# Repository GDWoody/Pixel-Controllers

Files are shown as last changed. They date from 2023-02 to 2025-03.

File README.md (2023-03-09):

# Copyright and Disclaimer
Copyright: GDWoody

This documentation describes Open Hardware and is licensed under the CERN Open Hardware License Version 2 - Strongly Reciprocal. (CERN-OHL-S)

You may redistribute and modify this documentation under the terms of the CERN OHL-S-v2 (https://ohwr.org/cern_ohl_s_v2.txt). This documentation is distributed WITHOUT ANY EXPRESS OR IMPLIED WARRANTY, INCLUDING OF MERCHANTABILITY, SATISFACTORY QUALITY AND FITNESS FOR A PARTICULAR PURPOSE. Please see the CERN OHL v2-S for applicable conditions

Under CERN OHL-S-v2, derivative work must be publicly released as defined in subsection 3.3

---
# Controllers & Expansion Boards

These Pixel Controllers are based on Scott Hanson's BBB 16v2 SMD controller [https://github.com/computergeek1507/PB_16](https://github.com/computergeek1507/PB_16/blob/master/BBB_16_SMD/README.md) with a few modifications and are designed as open source DIY hobbyist controllers. They are **not** intended to be sold as commercial products. All controller boards are 5v DC only and do not supply power for Pixel Strings, only data and ground. They all run FPP to drive the pixel and serial ports. Connection to a network/internet is by ethernet also WIFI and audio are supported via the USB port. All design files are open source and available on github, EasyEDA was used to create the designs.

Disclaimer: If you wish to build your own boards, please do so at your own risk. I use [jlcpcb.com](https://jlcpcb.com) for PCB manufacture and [lcsc.co](https://www.lcsc.com/) for parts, all the nessasary files are in the jlcpcb folders.

## [**BBB 16v2 SMD**](bbb_16/)

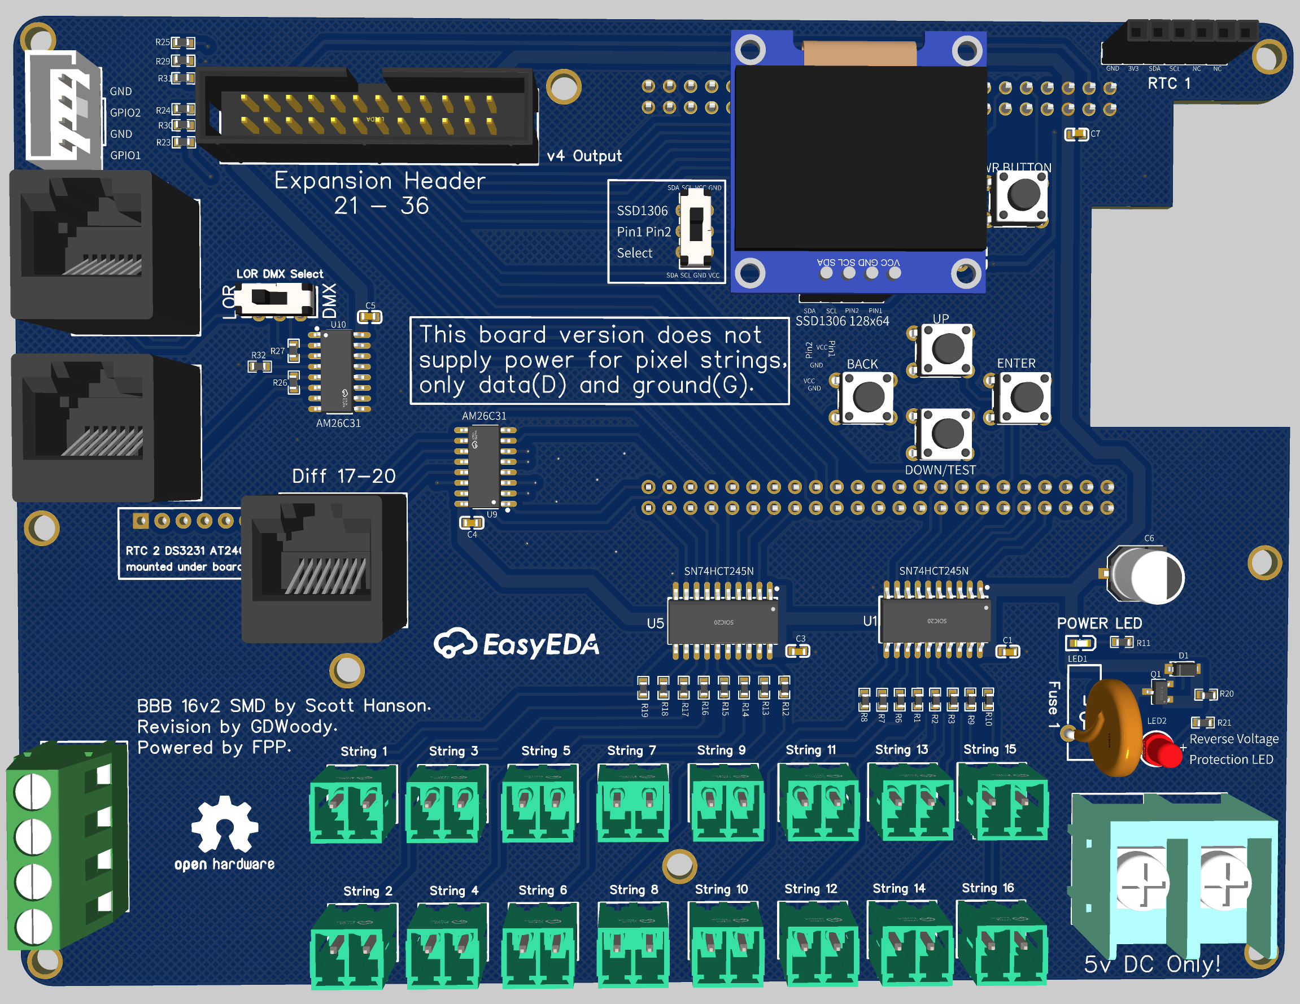
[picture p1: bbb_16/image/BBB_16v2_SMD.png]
Image of BBB 16v2 SMD Out


---
## [**Ordering PCB's from JLCPCB Instructions**](https://github.com/GDWoody/Pixel-Controllers/blob/main/JLC_PCB.md)

## [**Ordering Parts from LCSC Instructions**](https://github.com/GDWoody/Pixel-Controllers/blob/main/LCSC.md)

---
# Variants
I created different variants of the BB 16v2 SMD, to give more options for specific needs.

* [**BBB 16v2 SMD Push Fit**](bbb_16_push/) - 16 local ports with push fit connectors, 1 Differential port and 2 serial ports.

* [**BBB 8v1 SMD**](bbb_8/) - 8 local ports, 3 Differnetial ports and 2 serial ports.

* [**BBB 8v1 SMD Push Fit**](bbb_8_push/) - 8 local ports with push fit connectors, 3 Differential ports and 2 serial ports.

* [**BBB 4v1 SMD**](bbb_4/) - 4 local ports, 4 Differential ports and 2 serial ports.

* [**BBB 4v1 SMD Push Fit**](bbb_4_push/) - 4 local ports with push fit connectors, 4 Differential ports and 2 serial ports

* [**BBB All Diff v1**](bbb_all_diff/) - No local ports, 5 Differential ports and 2 serial ports.

---
# Expansion Boards
 All Expansion Boards are compatable with my BBB boards and variants.

* [**Differential Expansion**](bbb_diff_expansion/) - 4 Port Remote Differential Expansion (24 pins).

* [**16 Port Expansion**](bbb_16_expansion/) - 16 Port Local Expansion.

---
# Differential Receiver Boards
 All Receiver Boards are compatable with my BBB boards and variants.

* [**Differential Receivers**](diff_receiver/) - 4 Port Remote Differential Receivers.

---
## Additional Hardware Required

* A good quality SD card with FPP installed on it

* FPP images can be found at [**https://github.com/FalconChristmas/fpp/releases**](https://github.com/FalconChristmas/fpp/releases)

* A BeagleBone Black, BeagleBone Black Wireless, BeagleBone Green, or SanCloud BeagleBone enhanced 

* A SSD1306 128x64 OLED Display

---
# WLED Controllers

* [**WLED Controller with 4 output ports**](wled/)

* [**WLED Controller with 1 Differential port**](wled_d/)

---
## [**View All Boards**](image/)

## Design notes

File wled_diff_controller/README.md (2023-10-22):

## Copyright and Disclaimer
Copyright: GDWoody

This documentation describes Open Hardware and is licensed under the CERN Open Hardware License Version 2 - Strongly Reciprocal. (CERN-OHL-S)

You may redistribute and modify this documentation under the terms of the CERN OHL-S-v2 (https://ohwr.org/cern_ohl_s_v2.txt). This documentation is distributed WITHOUT ANY EXPRESS OR IMPLIED WARRANTY, INCLUDING OF MERCHANTABILITY, SATISFACTORY QUALITY AND FITNESS FOR A PARTICULAR PURPOSE. Please see the CERN OHL v2-S for applicable conditions

Under CERN OHL-S-v2, derivative work must be publicly released as defined in subsection 3.3

# WLED Differential Controller

The WLED Differential Controller requires a 5v DC only! Connecting any other size power source will damage the board. The board does not supply power outputs for pixels, only pixel data and ground connections.

# Features

* 1 Differential Port

* Reverse Voltage Protection

* GPIO 15 Relay Connector

* Power On Timer Delay Connections

## Additional Hardware Required

* A ESP32 WT32-ETH01 with WLED Software installed.

* WLED Software can be found at [**https://github.com/Aircoookie/WLED/releases**](https://github.com/Aircoookie/WLED/releases)

* WLED Software Installation and Help can be found at [**https://kno.wled.ge/basics/getting-started/**](https://kno.wled.ge/basics/getting-started/)

* Fully Compatable with [**Differential Receivers - 4 Port Remote Differential Receivers**](https://github.com/GDWoody/Pixel-Controllers/tree/main/diff_receiver/)

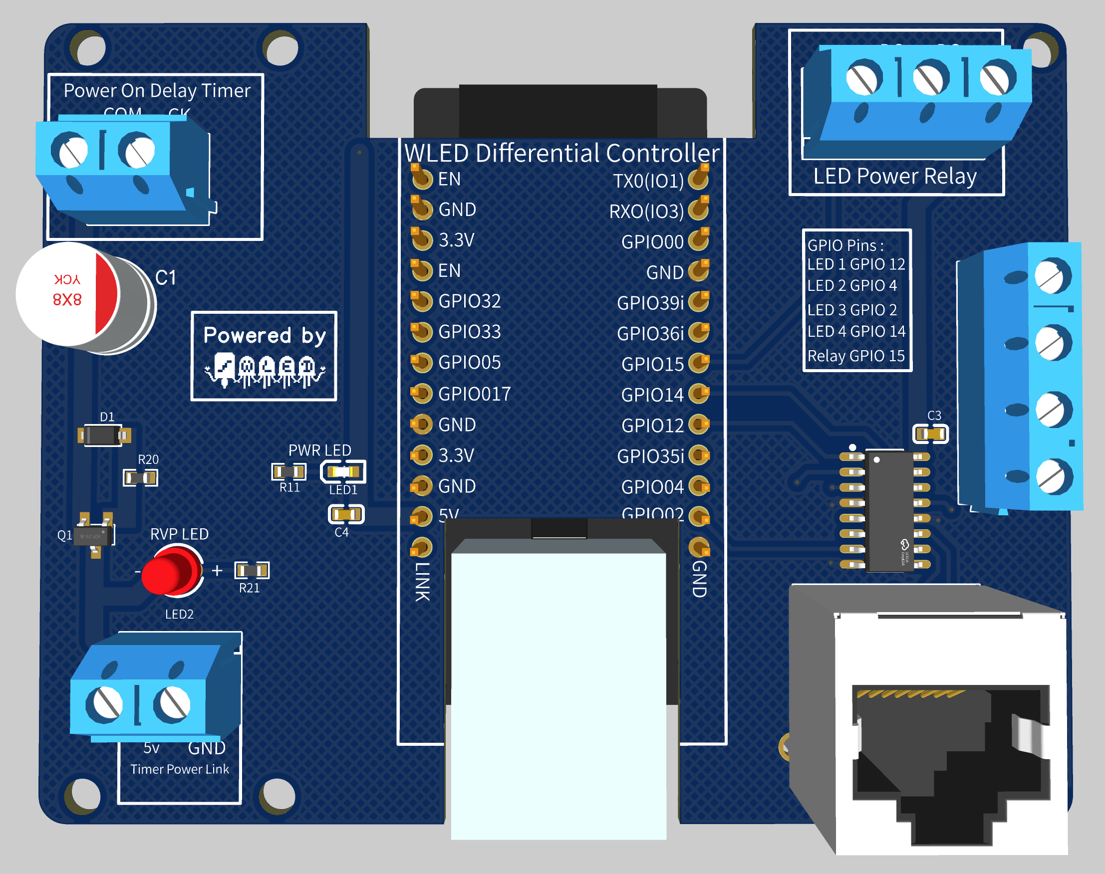
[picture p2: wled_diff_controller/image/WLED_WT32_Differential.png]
Image of WLED Differential Out


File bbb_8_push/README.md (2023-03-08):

## Copyright and Disclaimer
Copyright: GDWoody

This documentation describes Open Hardware and is licensed under the CERN Open Hardware License Version 2 - Strongly Reciprocal. (CERN-OHL-S)

You may redistribute and modify this documentation under the terms of the CERN OHL-S-v2 (https://ohwr.org/cern_ohl_s_v2.txt). This documentation is distributed WITHOUT ANY EXPRESS OR IMPLIED WARRANTY, INCLUDING OF MERCHANTABILITY, SATISFACTORY QUALITY AND FITNESS FOR A PARTICULAR PURPOSE. Please see the CERN OHL v2-S for applicable conditions

Under CERN OHL-S-v2, derivative work must be publicly released as defined in subsection 3.3

# BBB 8v1 SMD Push Fit Controller

Customised Pixel Controller based on Scott Hanson's BBB 16v2 SMD controller [https://github.com/computergeek1507/PB_16](https://github.com/computergeek1507/PB_16/blob/master/BBB_16_SMD/README.md). The board is largely the same as Scott's, but with a few modifications.

Note: The BBB 8v1 SMD Push Fit Controller requires a 5v DC only! Connecting any other size power source will damage the board. The board does no supply power outputs for pixels, only pixel data and ground connections.

# Features

* 700 pixel per output at 40 FPS or 1300 at 20 FPS

* 8 local ports with push fit connectors

* 3 Differential RJ45 ports

* 2 DMX Serial ports, DMX 1 can be selected as a DMX or LOR port

* 2 GPIO header

* 24 Pin expansion header

* SSD1306 128x64 OLED header

* Onboard 24LC256 eeprom

* Reverse Voltage Protection

* A RTC DS3231 AT24C32 can be connected to the board, either top mount or under mount.

* Onboard Resettable Fuse

---
## [**DIY Build Infomation**](https://github.com/GDWoody/Pixel-Controllers/blob/main/build.md)

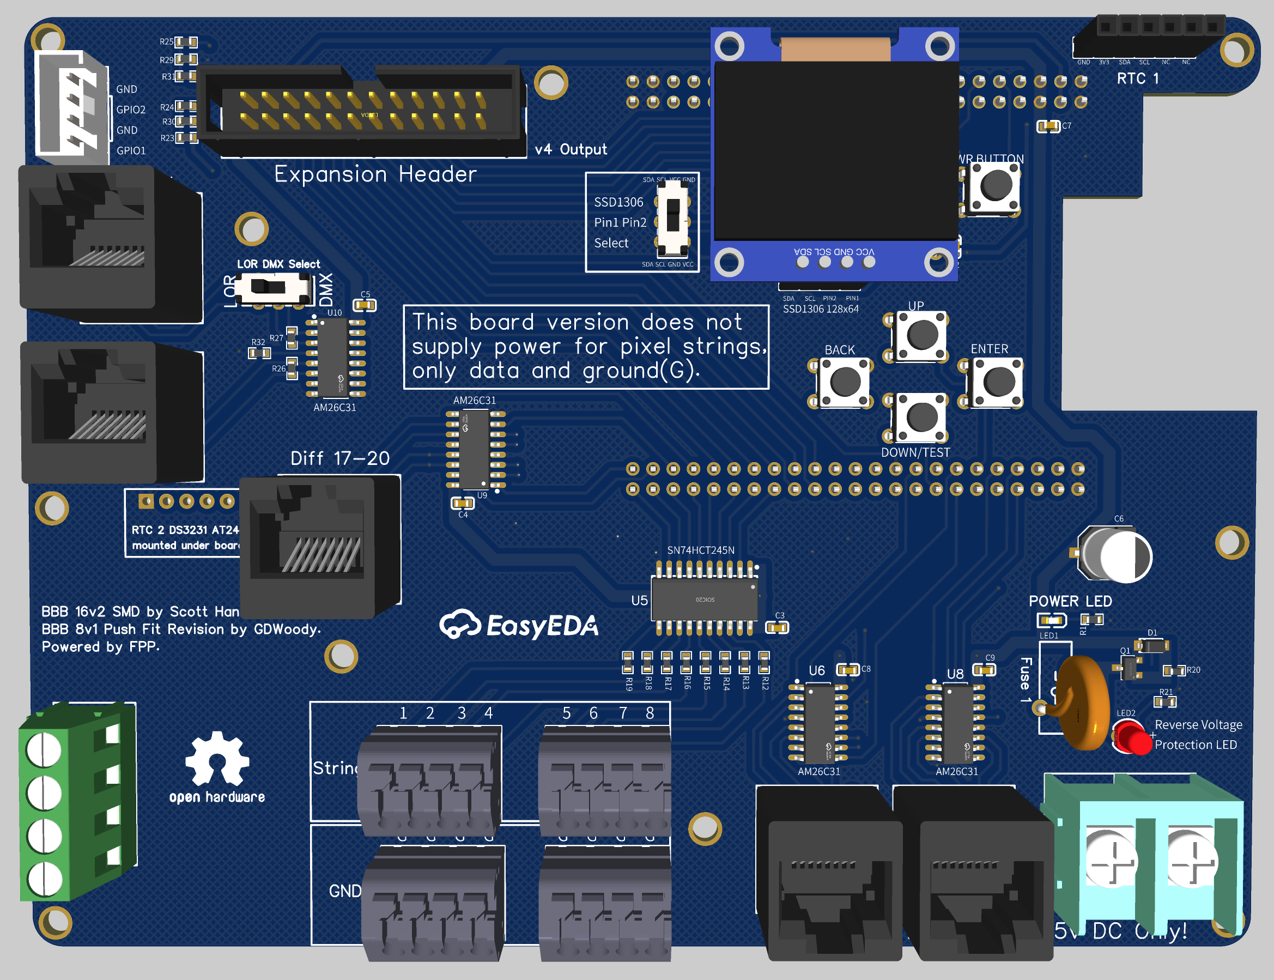
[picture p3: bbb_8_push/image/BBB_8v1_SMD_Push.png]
BBB_8v1_SMD_Push


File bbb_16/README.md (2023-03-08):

## Copyright and Disclaimer
Copyright: GDWoody

This documentation describes Open Hardware and is licensed under the CERN Open Hardware License Version 2 - Strongly Reciprocal. (CERN-OHL-S)

You may redistribute and modify this documentation under the terms of the CERN OHL-S-v2 (https://ohwr.org/cern_ohl_s_v2.txt). This documentation is distributed WITHOUT ANY EXPRESS OR IMPLIED WARRANTY, INCLUDING OF MERCHANTABILITY, SATISFACTORY QUALITY AND FITNESS FOR A PARTICULAR PURPOSE. Please see the CERN OHL v2-S for applicable conditions

Under CERN OHL-S-v2, derivative work must be publicly released as defined in subsection 3.3

# BBB 16v2 SMD Controller

Customised Pixel Controller based on Scott Hanson's BBB 16v2 SMD controller [https://github.com/computergeek1507/PB_16](https://github.com/computergeek1507/PB_16/blob/master/BBB_16_SMD/README.md). The board is largely the same as Scott's, but with a few modifications.

Note: The BBB 16v2 SMD Controller requires a 5v DC only! Connecting any other size power source will damage the board. The board does not supply power outputs for pixels, only pixel data and ground connections.

# Features

* 700 pixel per output at 40 FPS or 1300 at 20 FPS

* 16 local ports with 2 pin Phoenix style connectors

* 1 Differential RJ45 port

* 2 DMX Serial ports, DMX 1 can be selected as a DMX or LOR port

* 2 GPIO header

* 24 Pin expansion header

* SSD1306 128x64 OLED header

* Onboard 24LC256 eeprom

* Reverse Voltage Protection LED

* A RTC DS3231 AT24C32 can be connected to the board by either the top header RTC 1 or the under board header RTC 2

* Onboard Resettable Fuse

* Screw Terminal Block with 4 Additional GND connections

---
## [**DIY Build Infomation**](https://github.com/GDWoody/Pixel-Controllers/blob/main/build.md)

 BBB_16v2_SMD

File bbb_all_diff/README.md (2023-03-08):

## Copyright and Disclaimer
Copyright: GDWoody

This documentation describes Open Hardware and is licensed under the CERN Open Hardware License Version 2 - Strongly Reciprocal. (CERN-OHL-S)

You may redistribute and modify this documentation under the terms of the CERN OHL-S-v2 (https://ohwr.org/cern_ohl_s_v2.txt). This documentation is distributed WITHOUT ANY EXPRESS OR IMPLIED WARRANTY, INCLUDING OF MERCHANTABILITY, SATISFACTORY QUALITY AND FITNESS FOR A PARTICULAR PURPOSE. Please see the CERN OHL v2-S for applicable conditions

Under CERN OHL-S-v2, derivative work must be publicly released as defined in subsection 3.3

# BBB All Diff SMD Controller

Customised Pixel Controller based on Scott Hanson's BBB 16v2 SMD controller [https://github.com/computergeek1507/PB_16](https://github.com/computergeek1507/PB_16/blob/master/BBB_16_SMD/README.md). The board is largely the same as Scott's, but with a few modifications.

Note: The BBB All Diff SMD Controller requires 5v DC only! Connecting any other size power source will damage the board.

# Features

* 700 pixel per output at 40 FPS or 1300 at 20 FPS

* 5 Differential RJ45 ports

* 2 DMX Serial ports, DMX 1 can be selected as a DMX or LOR port

* 2 GPIO header

* 24 Pin expansion header

* SSD1306 128x64 OLED header

* Onboard 24LC256 eeprom

* Reverse Voltage Protection LED

* A RTC DS3231 AT24C32 can be connected to the board by either the top header RTC 1 or the under board header RTC 2

* Onboard Resettable Fuse

* Screw Terminal Blocks with 8 Additional GND connections

## [**DIY Build Infomation**](https://github.com/GDWoody/Pixel-Controllers/blob/main/build.md) 

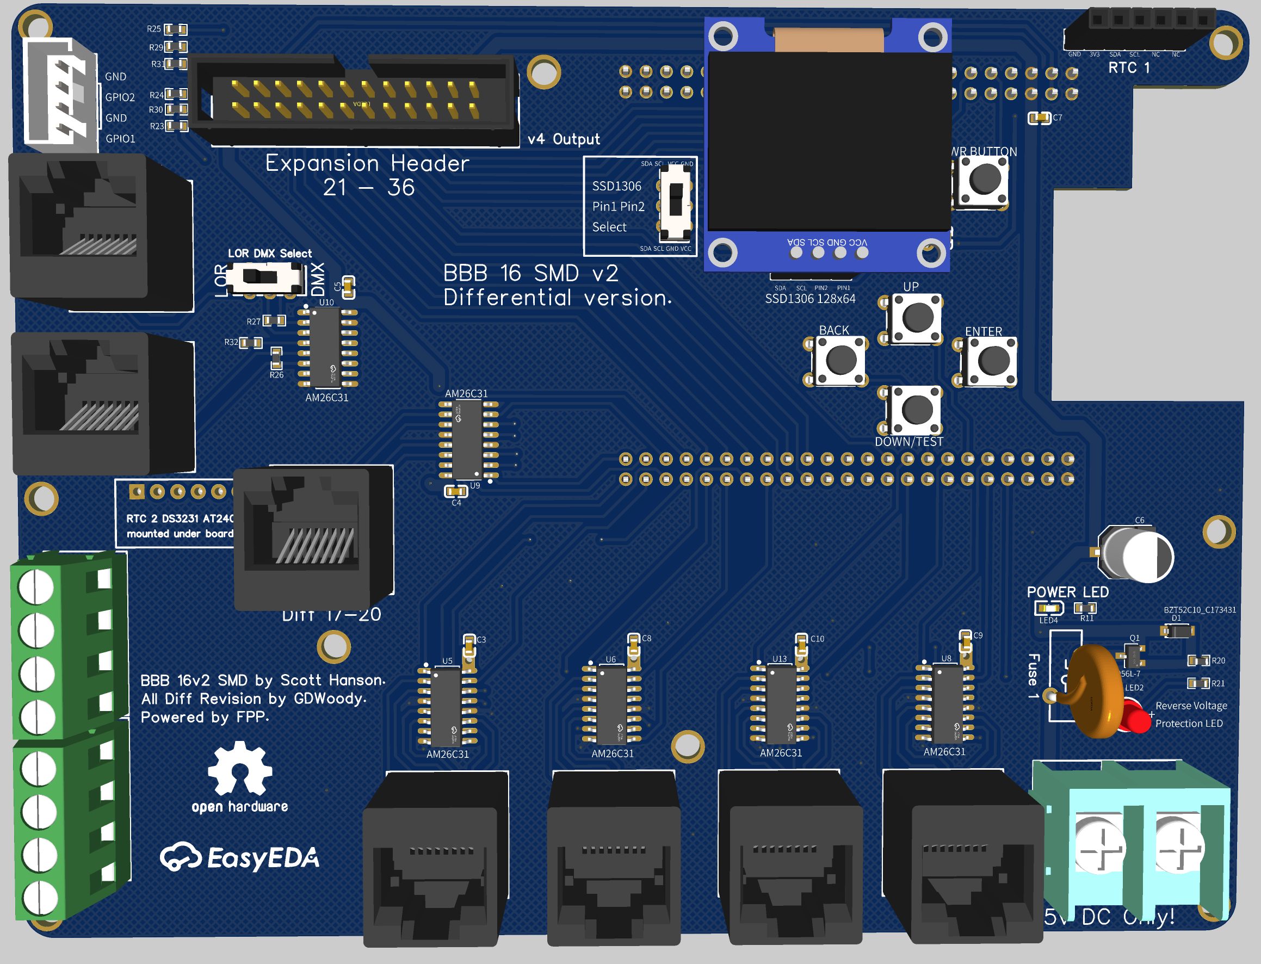
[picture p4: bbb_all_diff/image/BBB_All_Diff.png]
Image of BBB_All_Diff Out


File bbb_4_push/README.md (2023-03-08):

## Copyright and Disclaimer
Copyright: GDWoody

This documentation describes Open Hardware and is licensed under the CERN Open Hardware License Version 2 - Strongly Reciprocal. (CERN-OHL-S)

You may redistribute and modify this documentation under the terms of the CERN OHL-S-v2 (https://ohwr.org/cern_ohl_s_v2.txt). This documentation is distributed WITHOUT ANY EXPRESS OR IMPLIED WARRANTY, INCLUDING OF MERCHANTABILITY, SATISFACTORY QUALITY AND FITNESS FOR A PARTICULAR PURPOSE. Please see the CERN OHL v2-S for applicable conditions

Under CERN OHL-S-v2, derivative work must be publicly released as defined in subsection 3.3

# BBB 4v1 SMD Push Fit Controller

Customised Pixel Controller based on Scott Hanson's BBB 16v2 SMD controller [https://github.com/computergeek1507/PB_16](https://github.com/computergeek1507/PB_16/blob/master/BBB_16_SMD/README.md). The board is largely the same as Scott's, but with a few modifications.

Note: The BBB 4v1 SMD Push Fit Controller requires a 5v DC only! Connecting any other size power source will damage the board. The board does no supply power outputs for pixels, only pixel data and ground connections.

# Features

* 700 pixel per output at 40 FPS or 1300 at 20 FPS

* 4 local ports with push fit connectors

* 4 Differential RJ45 ports

* 2 DMX Serial ports, DMX 1 can be selected as a DMX or LOR port

* 2 GPIO header

* 24 Pin expansion header

* SSD1306 128x64 OLED header

* Onboard 24LC256 eeprom

* Reverse Voltage Protection

* A RTC DS3231 AT24C32 can be connected to the board, either top mount or under mount.

* Onboard Resettable Fuse

## [**DIY Build Infomation**](https://github.com/GDWoody/Pixel-Controllers/blob/main/build.md)

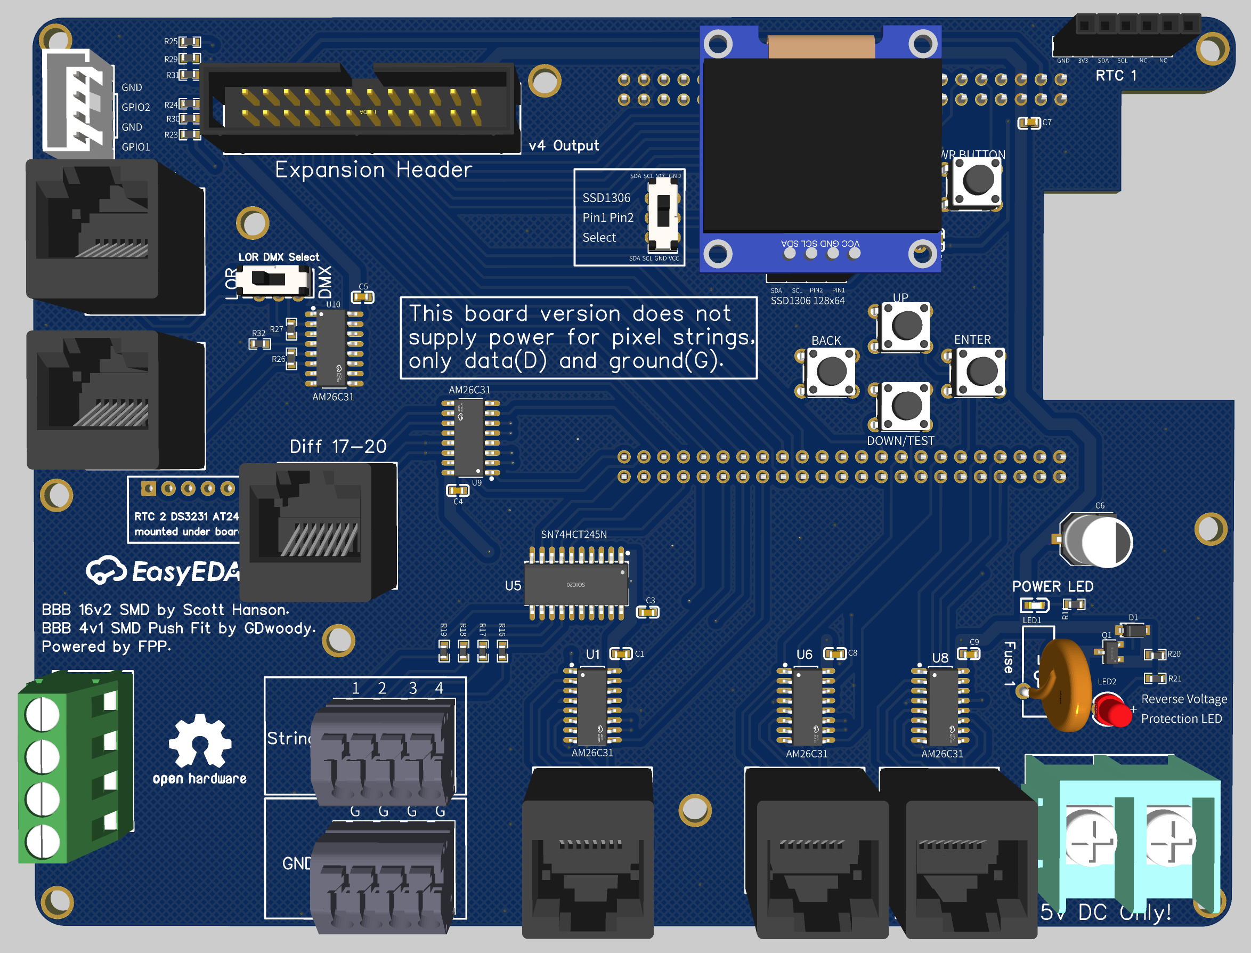
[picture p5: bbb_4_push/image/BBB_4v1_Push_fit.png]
BBB_4v1_SMD_Push


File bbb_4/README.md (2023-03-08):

## Copyright and Disclaimer
Copyright: GDWoody

This documentation describes Open Hardware and is licensed under the CERN Open Hardware License Version 2 - Strongly Reciprocal. (CERN-OHL-S)

You may redistribute and modify this documentation under the terms of the CERN OHL-S-v2 (https://ohwr.org/cern_ohl_s_v2.txt). This documentation is distributed WITHOUT ANY EXPRESS OR IMPLIED WARRANTY, INCLUDING OF MERCHANTABILITY, SATISFACTORY QUALITY AND FITNESS FOR A PARTICULAR PURPOSE. Please see the CERN OHL v2-S for applicable conditions

Under CERN OHL-S-v2, derivative work must be publicly released as defined in subsection 3.3

# BBB 4v1 SMD Controller

Customised Pixel Controller based on Scott Hanson's BBB 16v2 SMD controller [https://github.com/computergeek1507/PB_16](https://github.com/computergeek1507/PB_16/blob/master/BBB_16_SMD/README.md). The board is largely the same as Scott's, but with a few modifications.

Note: The BBB 4v1 SMD Controller requires a 5v DC only! Connecting any other size power source will damage the board. The board does not supply power outputs for pixels, only pixel data and ground connections.

# Features

* 700 pixel per output at 40 FPS or 1300 at 20 FPS

* 4 local ports with 2 pin Phoenix style connectors

* 4 Differential RJ45 ports

* 2 DMX Serial ports, DMX 1 can be selected as a DMX or LOR port

* 2 GPIO header

* 24 Pin expansion header

* SSD1306 128x64 OLED header

* Onboard 24LC256 eeprom

* Reverse Voltage Protection

* A RTC DS3231 AT24C32 can be connected to the board, either top mount or under mount.

* Onboard Resettable Fuse
 
## [**DIY Build Infomation**](https://github.com/GDWoody/Pixel-Controllers/blob/main/build.md)

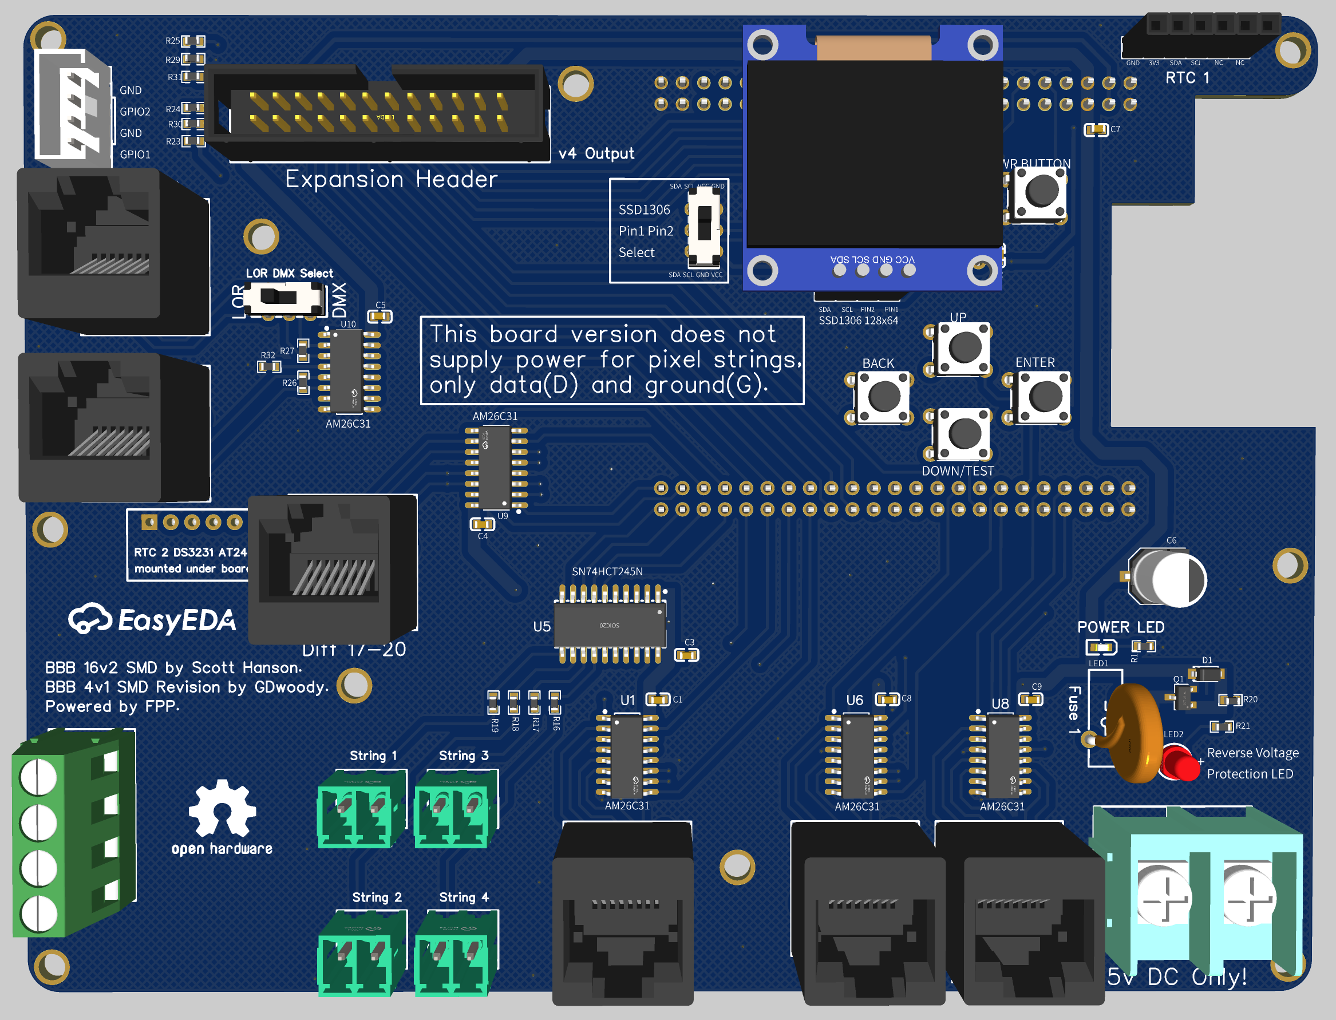
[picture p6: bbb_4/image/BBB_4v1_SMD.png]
Image of BBB 4v1 Out


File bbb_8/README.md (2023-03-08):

## Copyright and Disclaimer
Copyright: GDWoody

This documentation describes Open Hardware and is licensed under the CERN Open Hardware License Version 2 - Strongly Reciprocal. (CERN-OHL-S)

You may redistribute and modify this documentation under the terms of the CERN OHL-S-v2 (https://ohwr.org/cern_ohl_s_v2.txt). This documentation is distributed WITHOUT ANY EXPRESS OR IMPLIED WARRANTY, INCLUDING OF MERCHANTABILITY, SATISFACTORY QUALITY AND FITNESS FOR A PARTICULAR PURPOSE. Please see the CERN OHL v2-S for applicable conditions

Under CERN OHL-S-v2, derivative work must be publicly released as defined in subsection 3.3

# BBB 8v1 SMD Controller

Customised Pixel Controller based on Scott Hanson's BBB 16v2 SMD controller [https://github.com/computergeek1507/PB_16](https://github.com/computergeek1507/PB_16/blob/master/BBB_16_SMD/README.md). The board is largely the same as Scott's, but with a few modifications.

Note: The BBB 8v1 SMD Controller requires a 5v DC only! Connecting any other size power source will damage the board. The board does not supply power outputs for pixels, only pixel data and ground connections.

# Features

* 700 pixel per output at 40 FPS or 1300 at 20 FPS

* 8 local ports with 2 pin Phoenix style connectors

* 3 Differential RJ45 ports

* 2 DMX Serial ports, DMX 1 can be selected as a DMX or LOR port

* 2 GPIO header

* 24 Pin expansion header

* SSD1306 128x64 OLED header

* Onboard 24LC256 eeprom

* Reverse Voltage Protection

* A RTC DS3231 AT24C32 can be connected to the board, either top mount or under mount.

* Onboard Resettable Fuse

## [**DIY Build Infomation**](https://github.com/GDWoody/Pixel-Controllers/blob/main/build.md) 

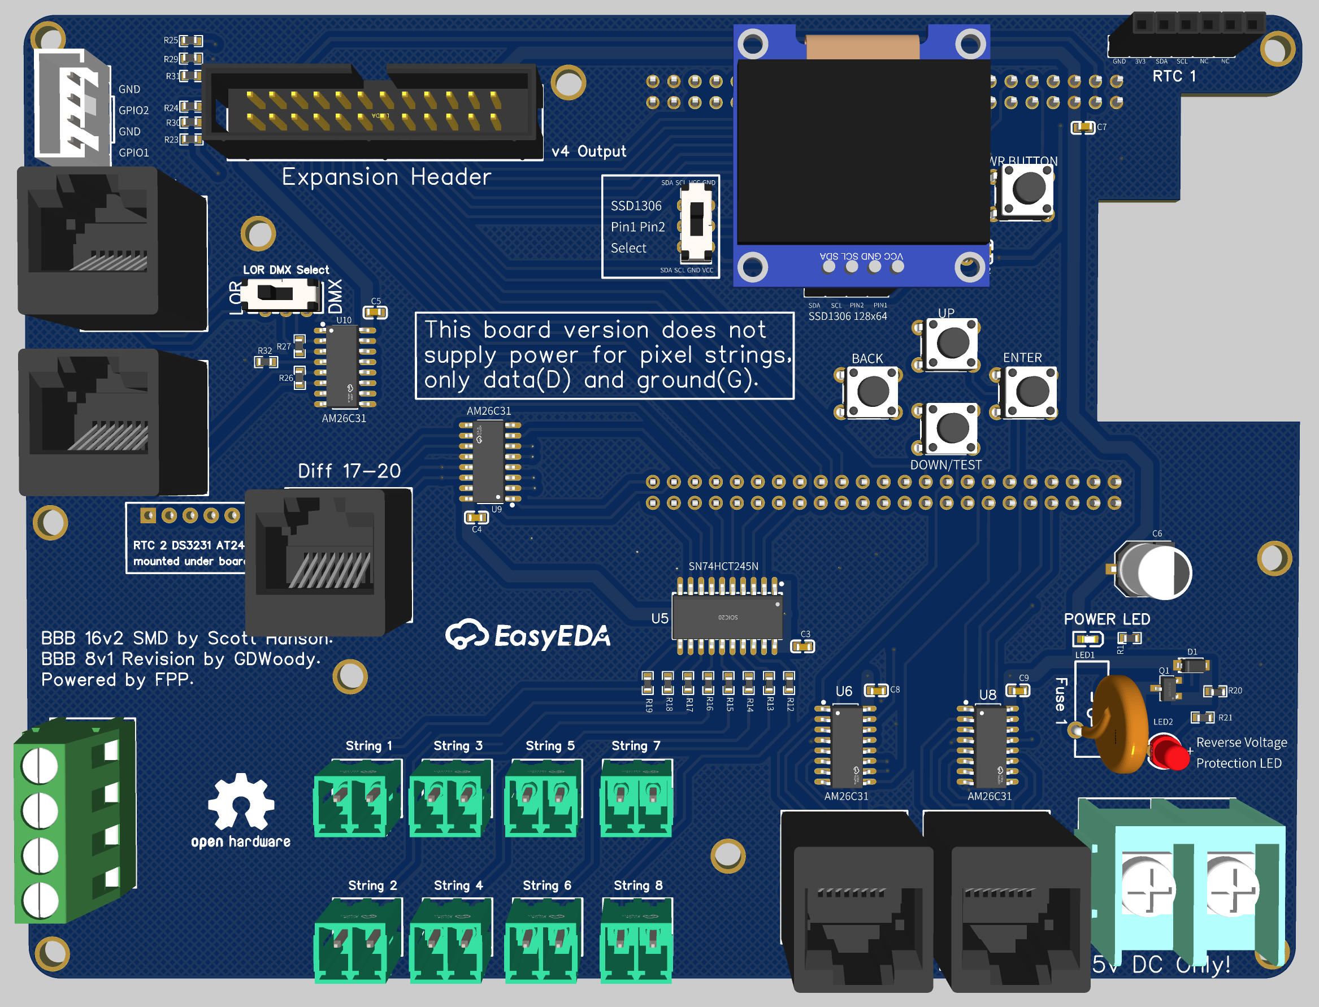
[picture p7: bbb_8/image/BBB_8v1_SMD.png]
Image of BBB 8v1 Out


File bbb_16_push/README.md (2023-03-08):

## Copyright and Disclaimer
Copyright: GDWoody

This documentation describes Open Hardware and is licensed under the CERN Open Hardware License Version 2 - Strongly Reciprocal. (CERN-OHL-S)

You may redistribute and modify this documentation under the terms of the CERN OHL-S-v2 (https://ohwr.org/cern_ohl_s_v2.txt). This documentation is distributed WITHOUT ANY EXPRESS OR IMPLIED WARRANTY, INCLUDING OF MERCHANTABILITY, SATISFACTORY QUALITY AND FITNESS FOR A PARTICULAR PURPOSE. Please see the CERN OHL v2-S for applicable conditions

Under CERN OHL-S-v2, derivative work must be publicly released as defined in subsection 3.3

# BBB 16v2 SMD Push Fit Controller

Customised Pixel Controller based on Scott Hanson's BBB 16v2 SMD controller [https://github.com/computergeek1507/PB_16](https://github.com/computergeek1507/PB_16/blob/master/BBB_16_SMD/README.md). The board is largely the same as Scott's, but with a few modifications.

Note: The BBB 16v2 SMD Push Fit Controller requires a 5v DC only! Connecting any other size power source will damage the board. The board does not supply power outputs for pixels, only pixel data and ground connections.

# Features

* 700 pixel per output at 40 FPS or 1300 at 20 FPS

* 16 local ports with push fit connectors

* 1 Differential RJ45 connection

* 2 DMX Serial ports, DMX 1 can be selected as a DMX or LOR port

* 2 GPIO header

* 24 Pin expansion header

* SSD1306 128x64 OLED header

* Onboard 24LC256 eeprom

* Reverse Voltage Protection

* A RTC DS3231 AT24C32 can be connected to the board, either top mount or under mount.

* Onboard Resettable Fuse

## [**DIY Build Infomation**](https://github.com/GDWoody/Pixel-Controllers/blob/main/build.md)

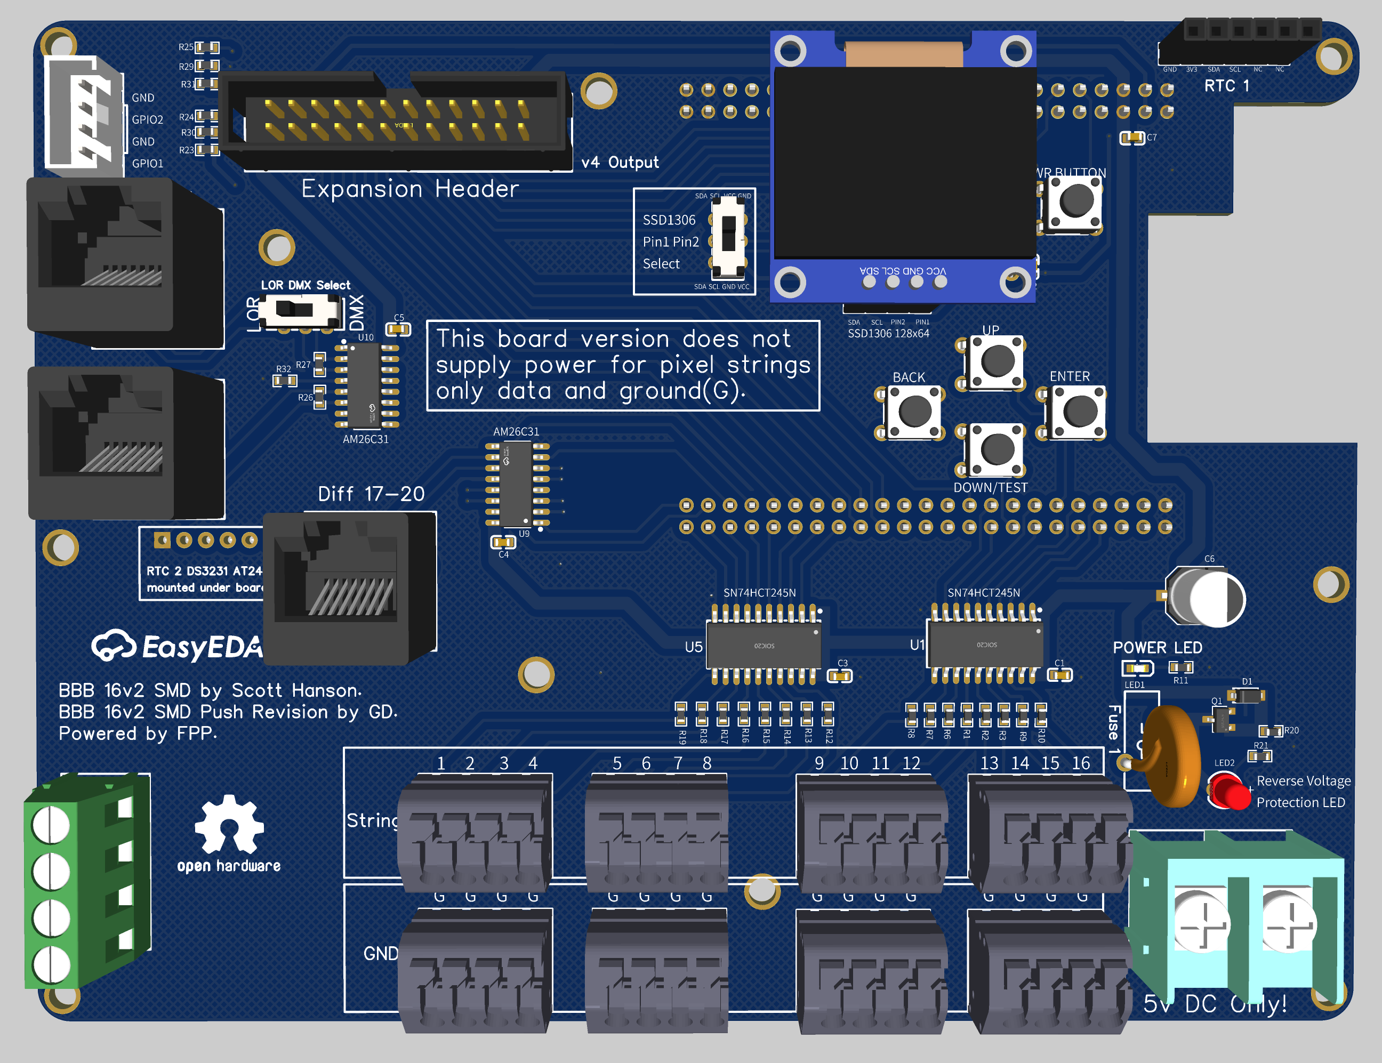
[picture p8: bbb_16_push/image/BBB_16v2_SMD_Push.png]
Image of BBB_16v2_SMD_Push Out


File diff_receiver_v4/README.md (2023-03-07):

## Copyright and Disclaimer
Copyright: GDWoody

This documentation describes Open Hardware and is licensed under the CERN Open Hardware License Version 2 - Strongly Reciprocal. (CERN-OHL-S)

You may redistribute and modify this documentation under the terms of the CERN OHL-S-v2 (https://ohwr.org/cern_ohl_s_v2.txt). This documentation is distributed WITHOUT ANY EXPRESS OR IMPLIED WARRANTY, INCLUDING OF MERCHANTABILITY, SATISFACTORY QUALITY AND FITNESS FOR A PARTICULAR PURPOSE. Please see the CERN OHL v2-S for applicable conditions

Under CERN OHL-S-v2, derivative work must be publicly released as defined in subsection 3.3

# Differential Receiver Boards

Note: All Differential Receiver Boards are 5v DC only! Connecting any other size power source will damage the board. The boards do not supply power outputs for pixels, only pixel data and ground connections.

* All boards have 4 output ports

* v2 boards have screw terminals

* v3 boards have 2 pin pheonix style plug connectors

* v4 boards have push fit connectors 
 
---
## v2

* Screw Terminals

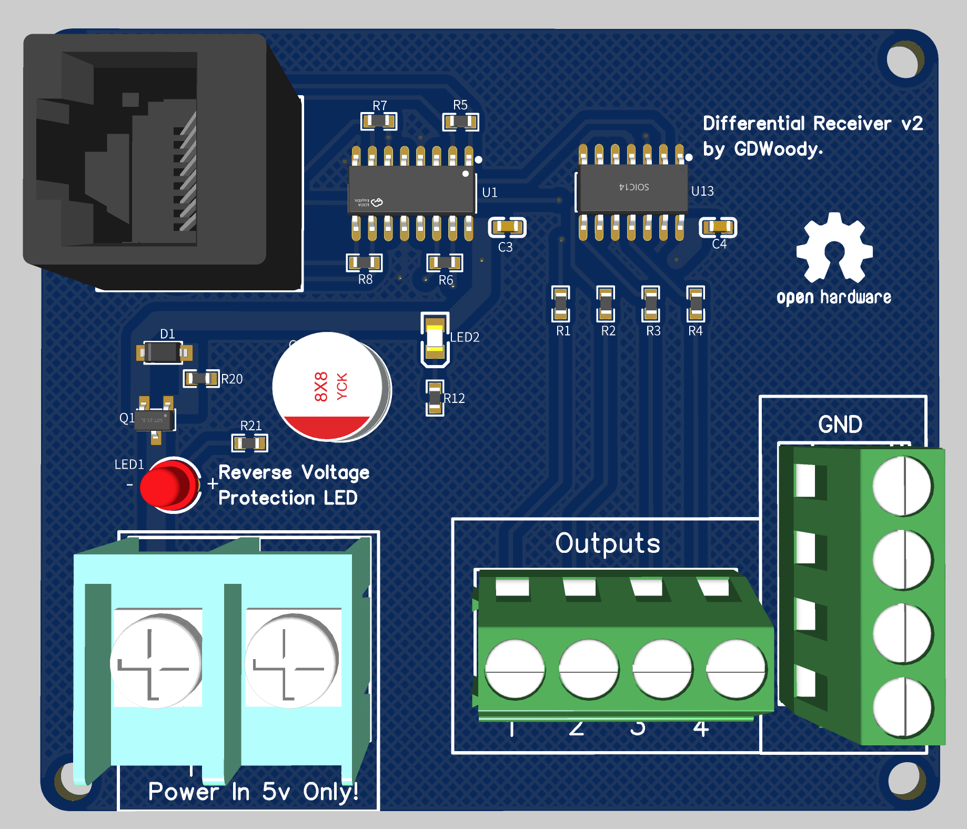
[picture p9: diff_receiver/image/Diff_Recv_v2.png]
Image of v2 Out


## v3

* 2 Pin Phoenix Style Connectors

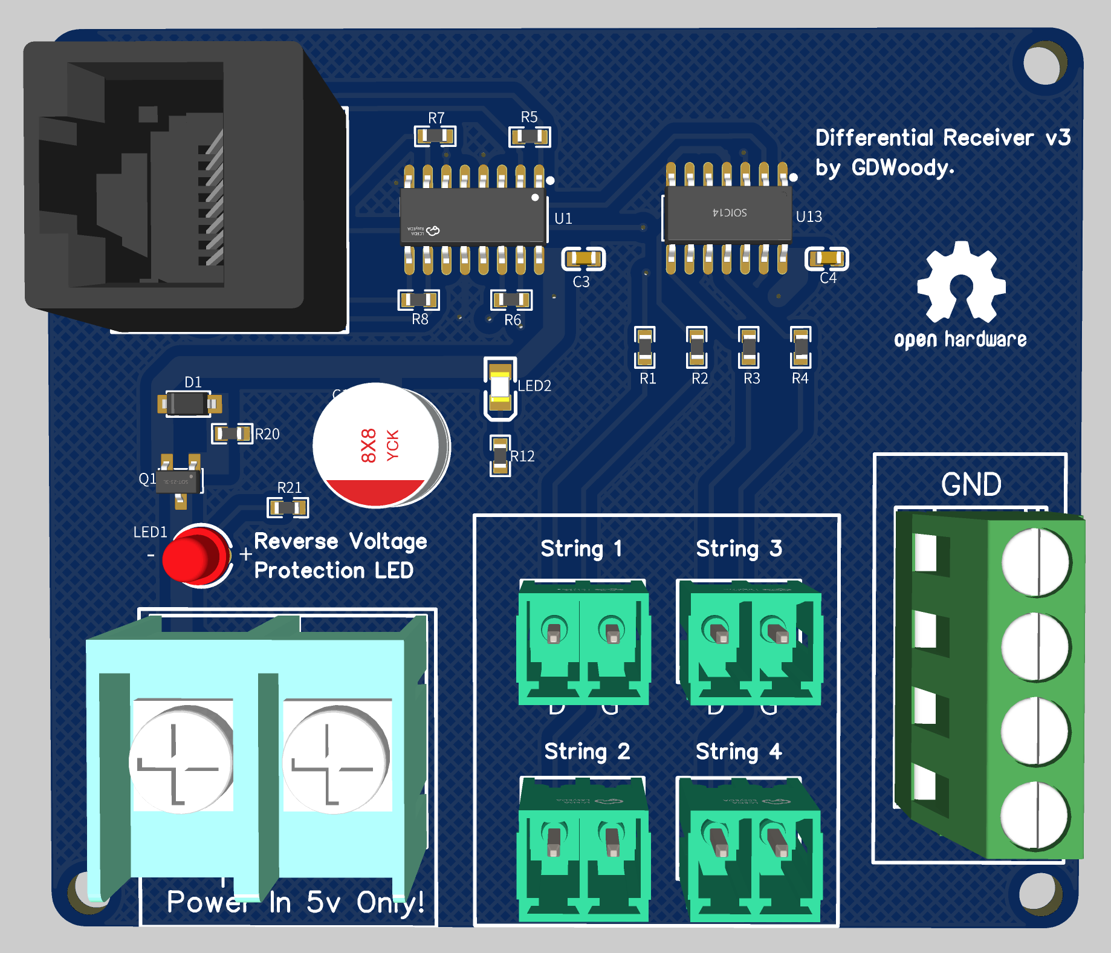
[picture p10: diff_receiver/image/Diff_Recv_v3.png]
Image of v3 Out


## v4

* Push Fit Connectors

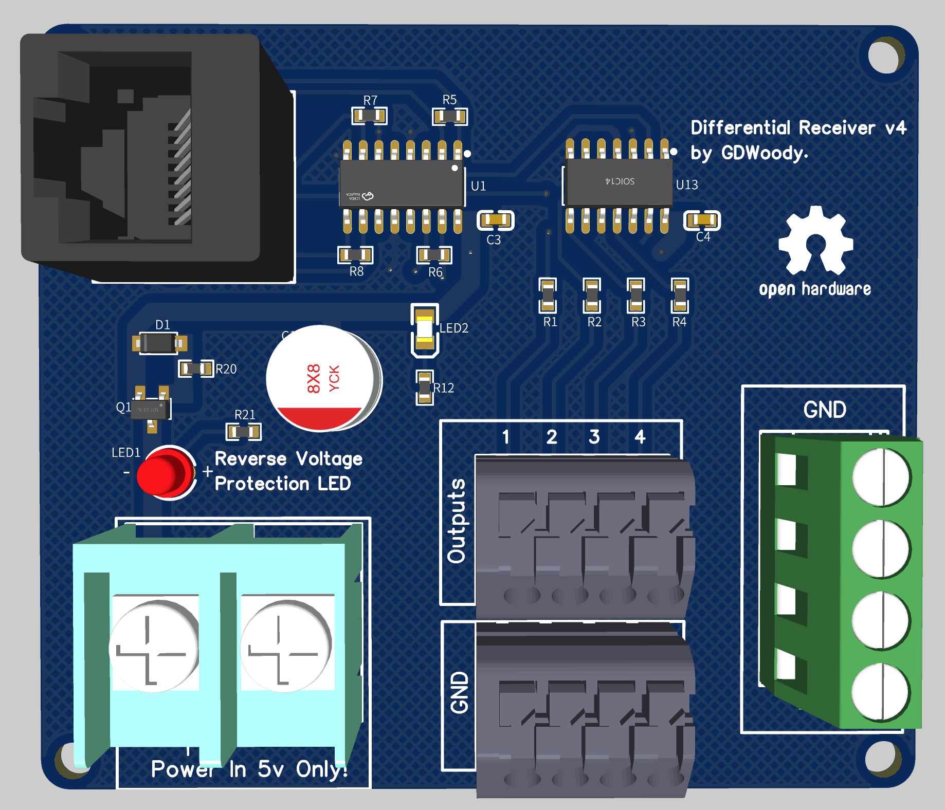
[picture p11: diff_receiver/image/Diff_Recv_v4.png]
Image of v4 Out


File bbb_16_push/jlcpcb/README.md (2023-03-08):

# BBB 16v2 SMD Push Fit Controller

## Copyright and Disclaimer
Copyright: GDWoody

This documentation describes Open Hardware and is licensed under the CERN Open Hardware License Version 2 - Strongly Reciprocal. (CERN-OHL-S)

You may redistribute and modify this documentation under the terms of the CERN OHL-S-v2 (https://ohwr.org/cern_ohl_s_v2.txt). This documentation is distributed WITHOUT ANY EXPRESS OR IMPLIED WARRANTY, INCLUDING OF MERCHANTABILITY, SATISFACTORY QUALITY AND FITNESS FOR A PARTICULAR PURPOSE. Please see the CERN OHL v2-S for applicable conditions

Under CERN OHL-S-v2, derivative work must be publicly released as defined in subsection 3.3

---
## BBB 16v2 SMD Push Fit Controller PCB's and Part Ordering
Following the instructions below your boards will arrive with only the SMD components fitted. To complete them you will also need to get and fit the 'Additional Components'.  

## To order BBB 16v2 SMD Push Fit PCBs From JLCPCB:

* Download the  [**Gerber_BBB_16v2_SMD_Push.zip**](https://github.com/GDWoody/Pixel-Controllers/blob/main/bbb_16_push/jlcpcb/gerber/Gerber_BBB_16v2_SMD_Push.zip) file in the jlcpcb\gerber folder.

* Download the  [**BOM_BBB_16v2_SMD_Push.xlsx**](https://github.com/GDWoody/Pixel-Controllers/blob/main/bbb_16_push/jlcpcb/assembly/BOM_BBB_16v2_SMD_Push.xlsx) file in the jlcpcb\assembly folder.

* Download the  [**CPL_BBB_16v2_SMD_Push.xlsx**](https://github.com/GDWoody/Pixel-Controllers/blob/main/bbb_16_push/jlcpcb/assembly/CPL_BBB_16v2_SMD_Push.xlsx) file in the jlcpcb\assembly folder.

*  Goto [**jlcpcb.com**](https://jlcpcb.com), sign in or make a new account, select Instant Quote and Upload the the Gerber_BBB_16v2_SMD_Push.zip file.

* The default settings should be ok. However you can choose 'PCB Color' and change 'Remove Order Number' to 'Specify a location'.

* Enable the SMD service, 'BOM_BBB_16v2_SMD_Push.xlsx' is the BOM file and 'CPL_BBB_16v2_SMD_Push.xlsx' is the CPL file.

* [**See here for detailed PCB ordering instructions for JLCPCB**](https://github.com/GDWoody/Pixel-Controllers/blob/main/JLC_PCB.md)

## To order Additional Required Parts from LCSC

* Download the [**BOM_BBB_16v2_SMD_Push_other_parts.xlsx**](https://github.com/GDWoody/Pixel-Controllers/blob/main/bbb_16_push/lcsc/BOM_BBB_16v2_SMD_Push_other_parts.xlsx) file in the lcsc folder.

* Goto [**lcsc.com**](https://lcsc.com), sign in or make a new account and select 'BOM Tool' and upload the /BOM_BBB_16v2_SMD_Push_other_parts.xlsx file.

* [**See here for detailed Parts ordering instructions for LCSC**](https://github.com/GDWoody/Pixel-Controllers/blob/main/LCSC.md)

## [**DIY Build Infomation**](https://github.com/GDWoody/Pixel-Controllers/blob/main/build.md)

---
## Additional Components Required

* A BeagleBone Black, BeagleBone Black Wireless, BeagleBone Green, or SanCloud BeagleBone enhanced 

* A SSD1306 128x64 OLED Display

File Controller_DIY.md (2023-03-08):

## Copyright and Disclaimer
Copyright: GDWoody

This documentation describes Open Hardware and is licensed under the CERN Open Hardware License Version 2 - Strongly Reciprocal. (CERN-OHL-S)

You may redistribute and modify this documentation under the terms of the CERN OHL-S-v2 (https://ohwr.org/cern_ohl_s_v2.txt). This documentation is distributed WITHOUT ANY EXPRESS OR IMPLIED WARRANTY, INCLUDING OF MERCHANTABILITY, SATISFACTORY QUALITY AND FITNESS FOR A PARTICULAR PURPOSE. Please see the CERN OHL v2-S for applicable conditions

Under CERN OHL-S-v2, derivative work must be publicly released as defined in subsection 3.3

# DIY Instructions for all Controller Boards

**Instructions apply to all Controller Boards, the example images shown here are for the BBB 16v2.**

## SMD Parts

* When you recieve your PCB's from JLCPCB they will only have the SMD parts fitted.

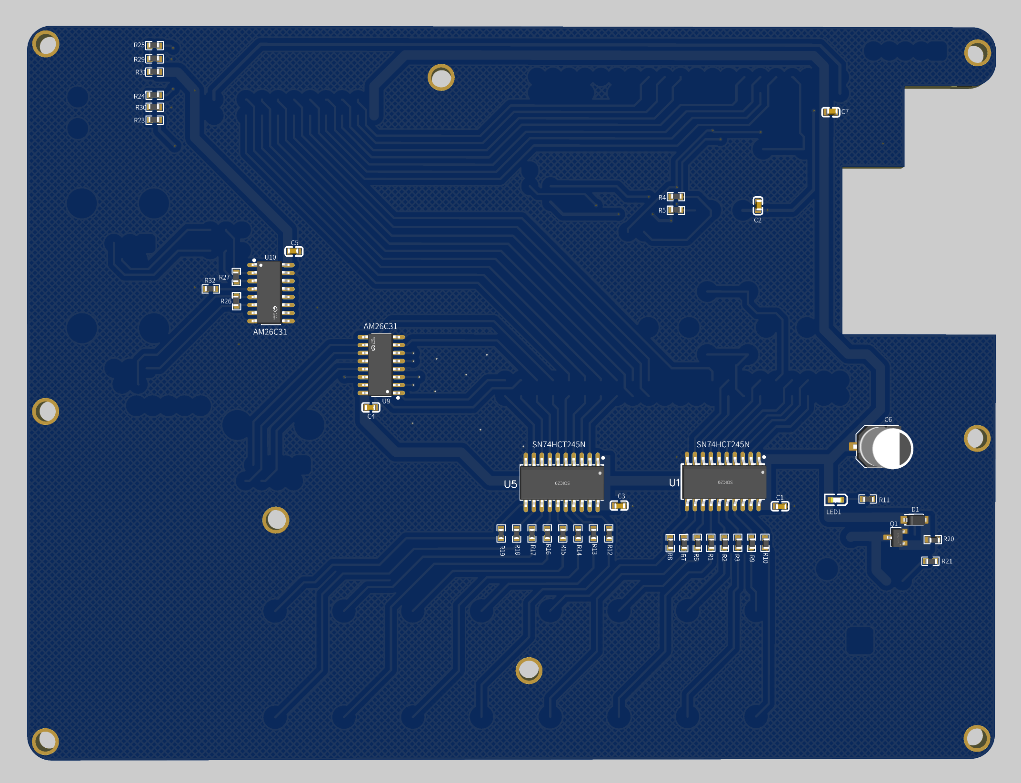
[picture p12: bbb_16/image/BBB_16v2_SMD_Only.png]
SMD Only


## Upper side DIY Parts

You can now complete the boards with the additional parts you ordered from LCSC.com

* Install the parts with the correct orientation 

* Make sure LED 2 is installed with the correct polarity!

* I recomend to use a DIP IC Socket for the 24LC256 EEPROM

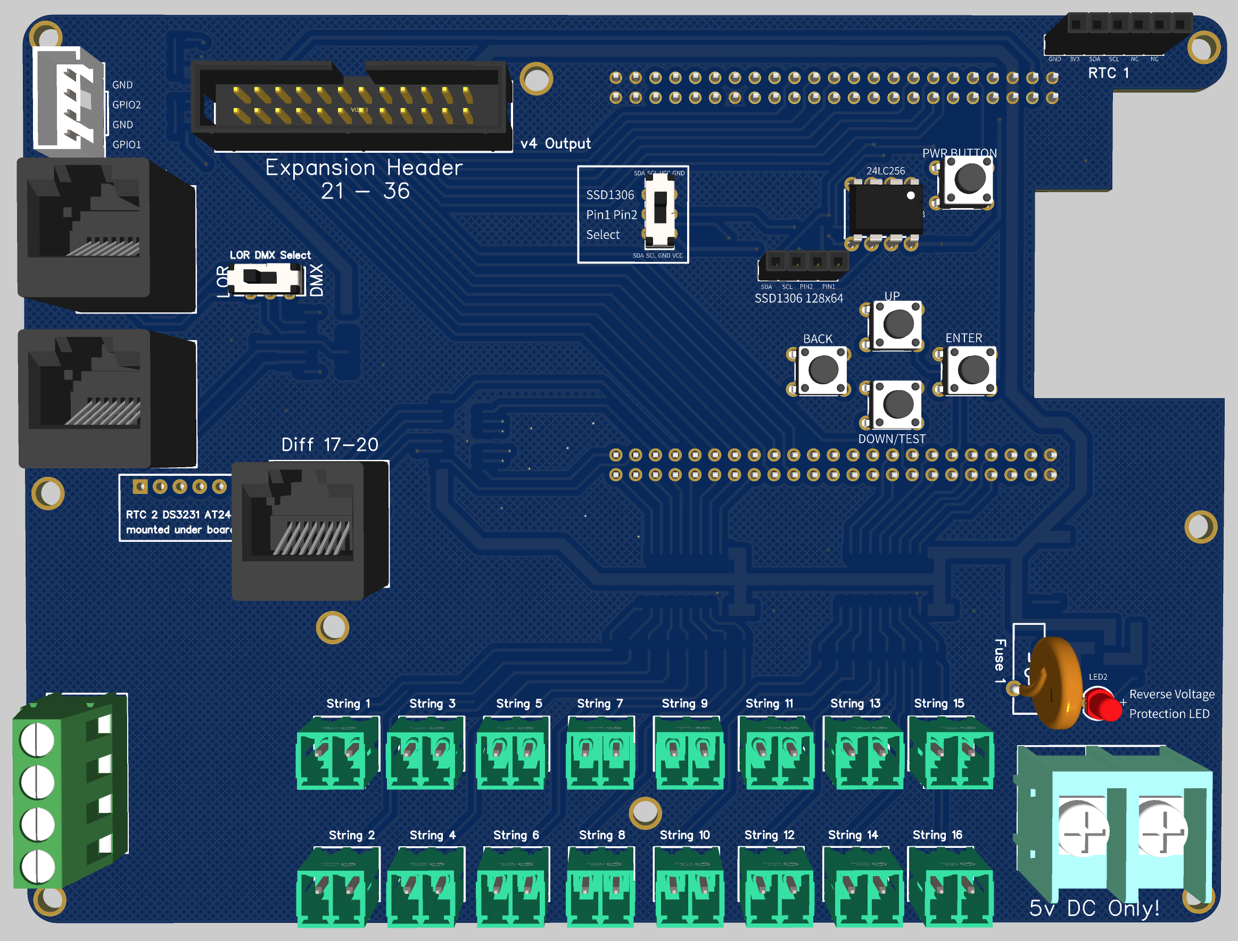
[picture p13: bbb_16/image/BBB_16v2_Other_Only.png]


## Under side DIY Parts

* Two 46 pin headers

* One 6 pin right angle header 

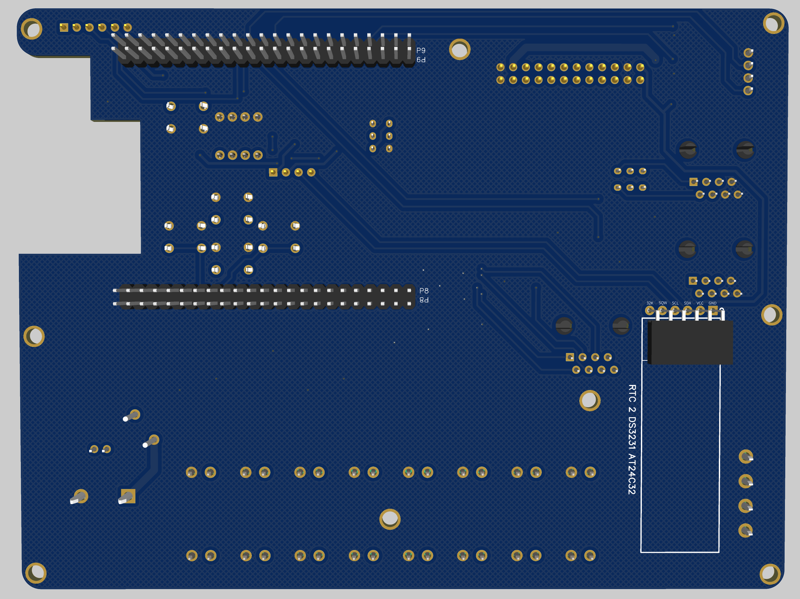
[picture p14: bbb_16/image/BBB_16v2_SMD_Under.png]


## You should now have a completed board

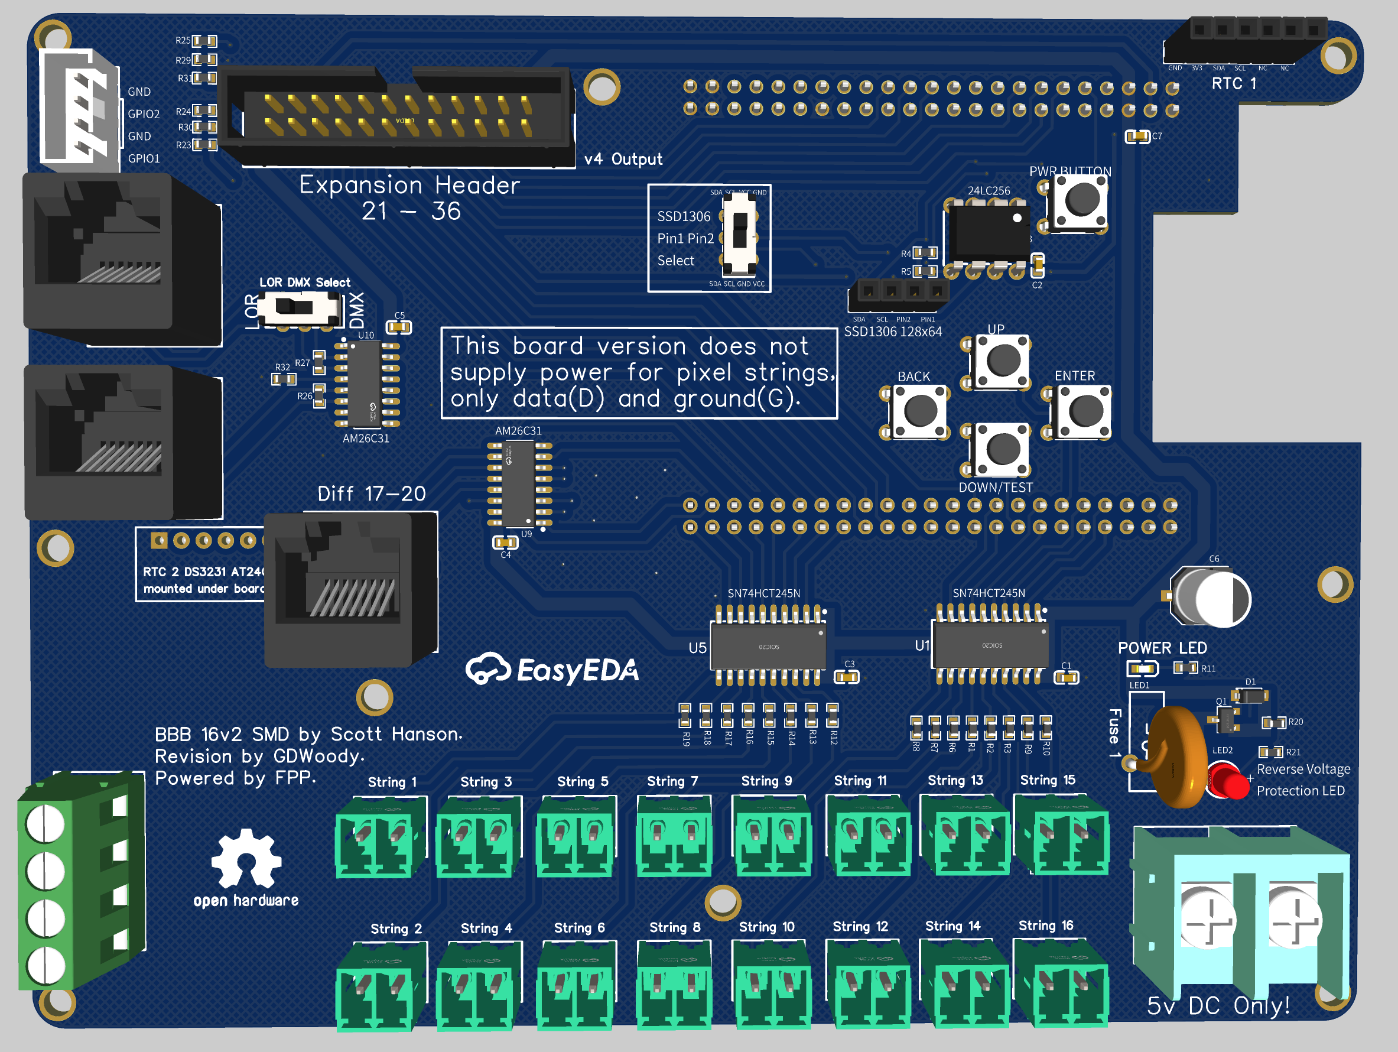
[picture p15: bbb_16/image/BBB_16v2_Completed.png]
Completed


## SSD1306 128x64 OLED Display

* Note: Some SSD1306 OLED displays have different VCC and GND pin layout

* Before powering up use the 'SSD1306 Select Switch' to set Pin1 and Pin2 on the SSD1306 128x64 header for your OLED display!

SSD1306

 ## EEPROM

 * [EEPROM Download](https://github.com/GDWoody/Pixel-Controllers/blob/main/eeprom/BBB16v2-221118135219-eeprom.bin)

 * [Scott's EEPROM lashing instructions](https://github.com/computergeek1507/PB_16/blob/master/Flashing_EEPROM.md)

---
## Controller Interactive Bom's

* ## [**BBB 16v2 iBom**](https://gdwoody.github.io/bbb_16/ibom.html)
* ## [**BBB 16v2 Push Fit iBom**](https://gdwoody.github.io/bbb_16_push/ibom.html)
* ## [**BBB 8v1 iBom**](https://gdwoody.github.io/bbb_8/ibom.html)
* ## [**BBB 8v1 Push Fit iBom**](https://gdwoody.github.io/bbb_8_push/ibom.html)
* ## [**BBB 4v1 iBom**](https://gdwoody.github.io/bbb_4/ibom.html)
* ## [**BBB 4v1 Push Fit iBom**](https://gdwoody.github.io/bbb_4_push/ibom.html)
* ## [**BBB All Differential iBom**](https://gdwoody.github.io/bbb_all_diff/ibom.html)

 ## Additional Hardware Required

* A good quality SD card with FPP installed on it. FPP images can be found at [**https://github.com/FalconChristmas/fpp/releases**](https://github.com/FalconChristmas/fpp/releases)

* A BeagleBone Black, BeagleBone Black Wireless, BeagleBone Green, or SanCloud BeagleBone enhanced 

* A SSD1306 128x64 OLED Display

---

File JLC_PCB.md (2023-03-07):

## Ordering from [jlcpcb.com](https://jlcpcb.com/)

Download the Gerber file from the jlcpcb/gerber folder for the board you are making.

* 'Gerber_xxxxxxx.zip' is the Gerber file.

Download the BOM and CPL files from the jlcpcb/assembly folder for the board you are making.

* 'BOM_xxxxxxx.xlsx' is the BOM file.
* 'CPL_xxxxxxx.xlsx' is the CPL file.

### SMD PCB's

Go to https://cart.jlcpcb.com/quote to upload the PCB design files.

Upload the "Gerber_xxxxx.zip" file by clicking the "Add Gerber File" button.

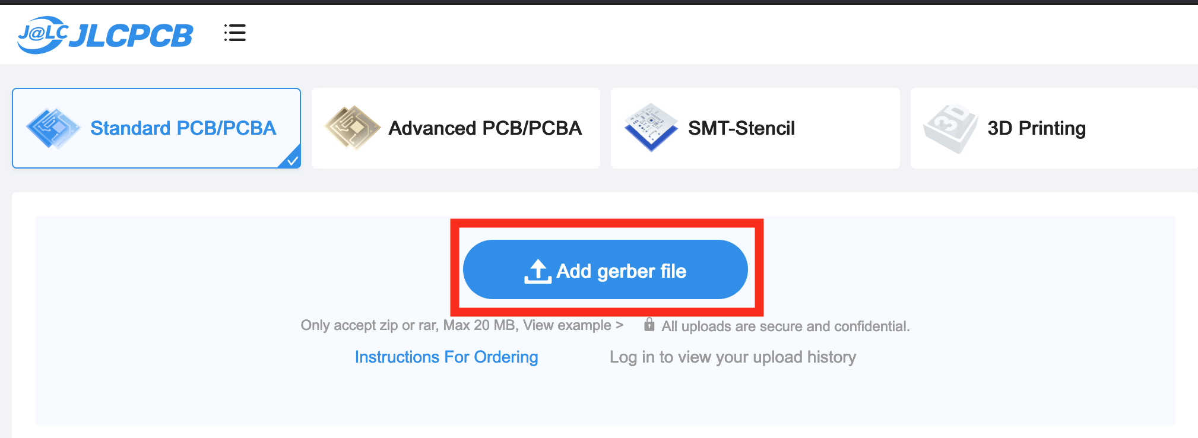
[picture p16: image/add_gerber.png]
Add Button


The default settings should be ok. However you can choose 'PCB Color', any other color than green will add two days to the build time.

Option: To hide the order number being visable on the PCB change 'Remove Order Number' to 'Specify a location'.

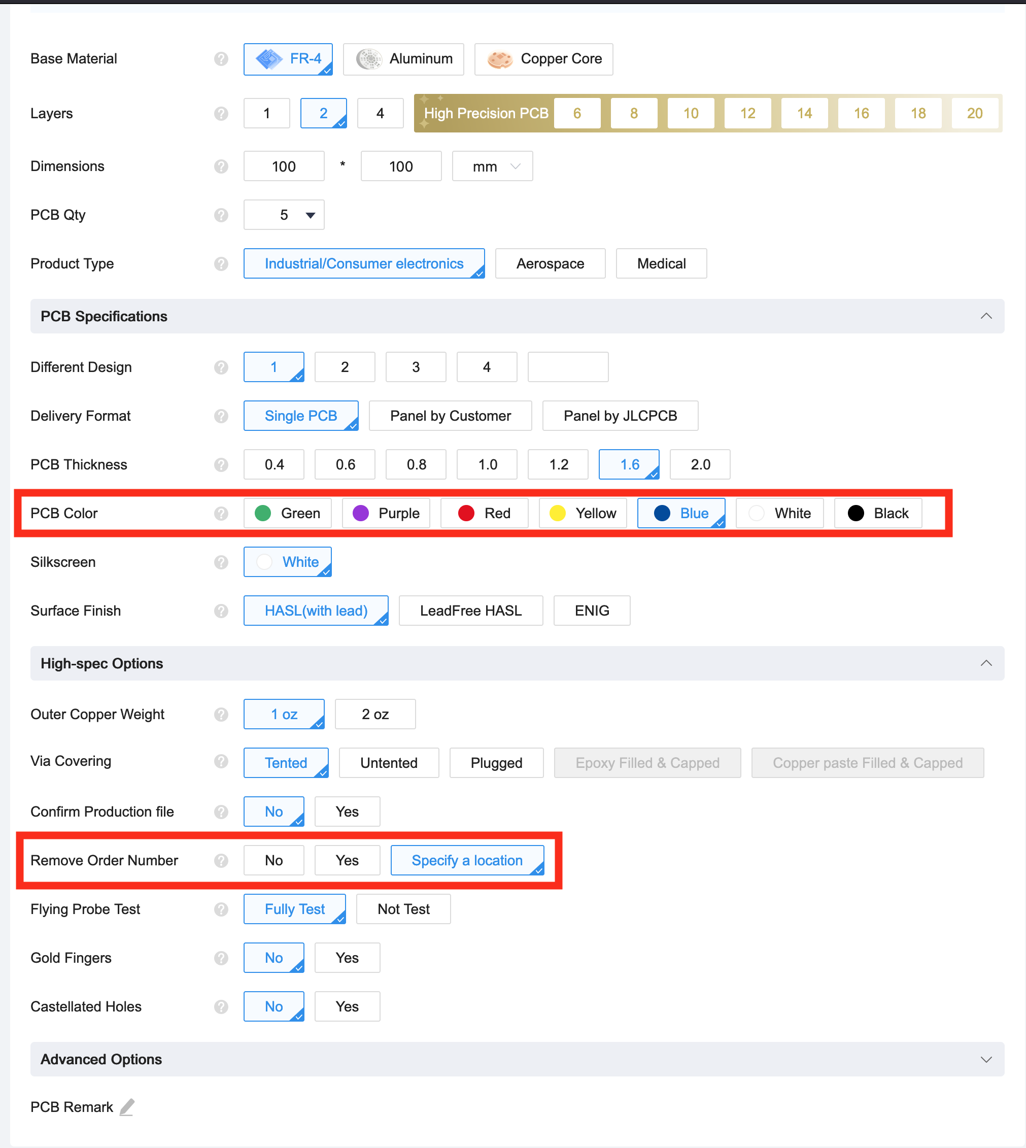
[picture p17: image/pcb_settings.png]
PCB Settings


### Surface Mount Assembly Service

Scroll down and Enable the SMD service and make sure the settings are as in the image.

Accept the Terms and Conditions then click "Confirm".

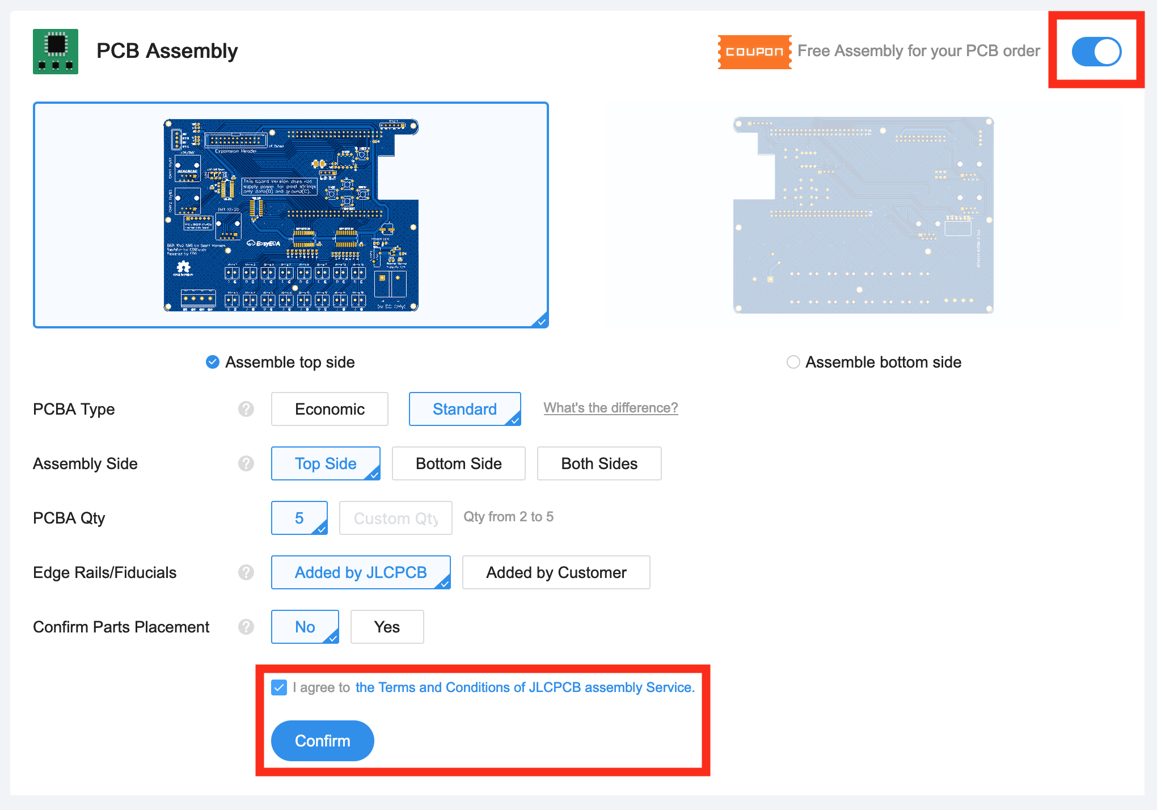
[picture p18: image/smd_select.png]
SMD ON


Click "Next" on the right below the Calculated Price heading.

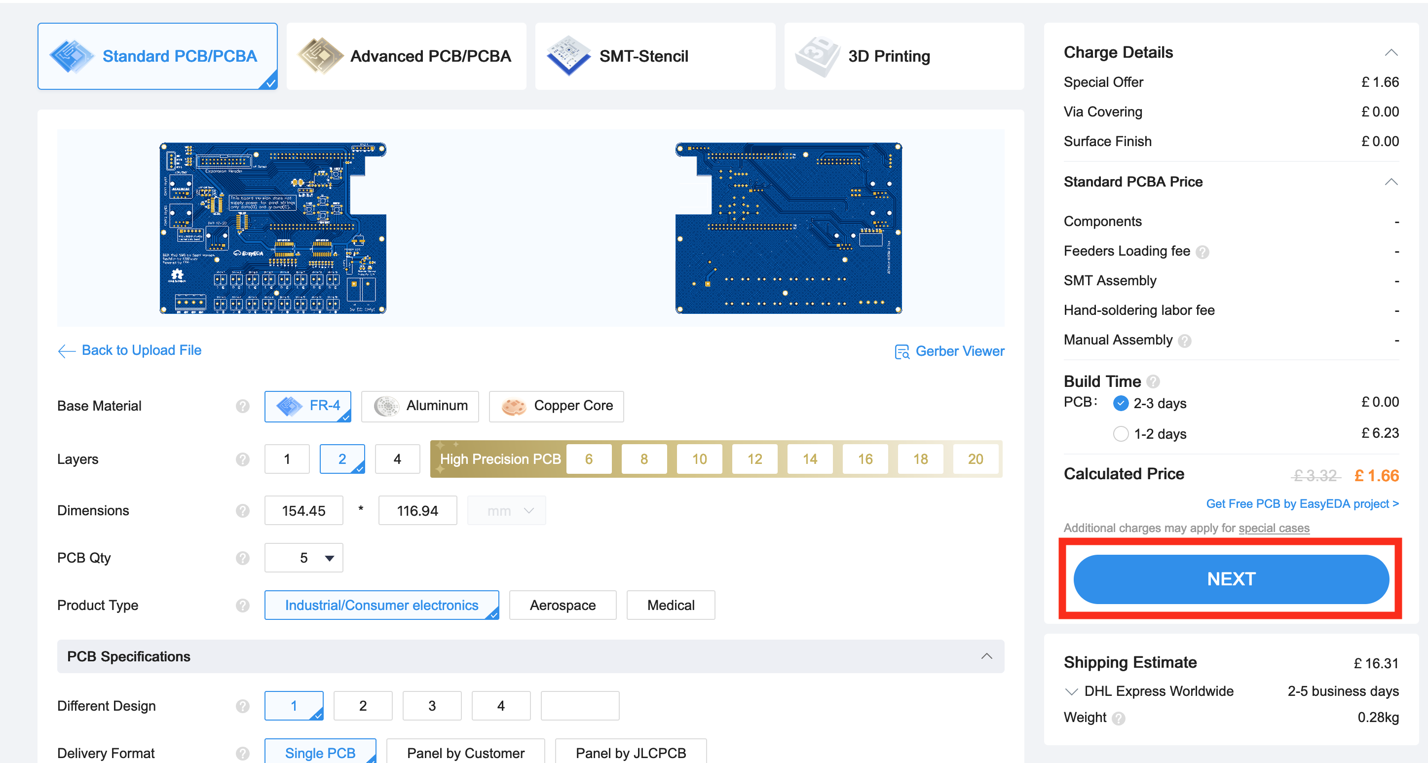
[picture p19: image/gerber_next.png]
SMD Next


### PCB page

Click "Next"

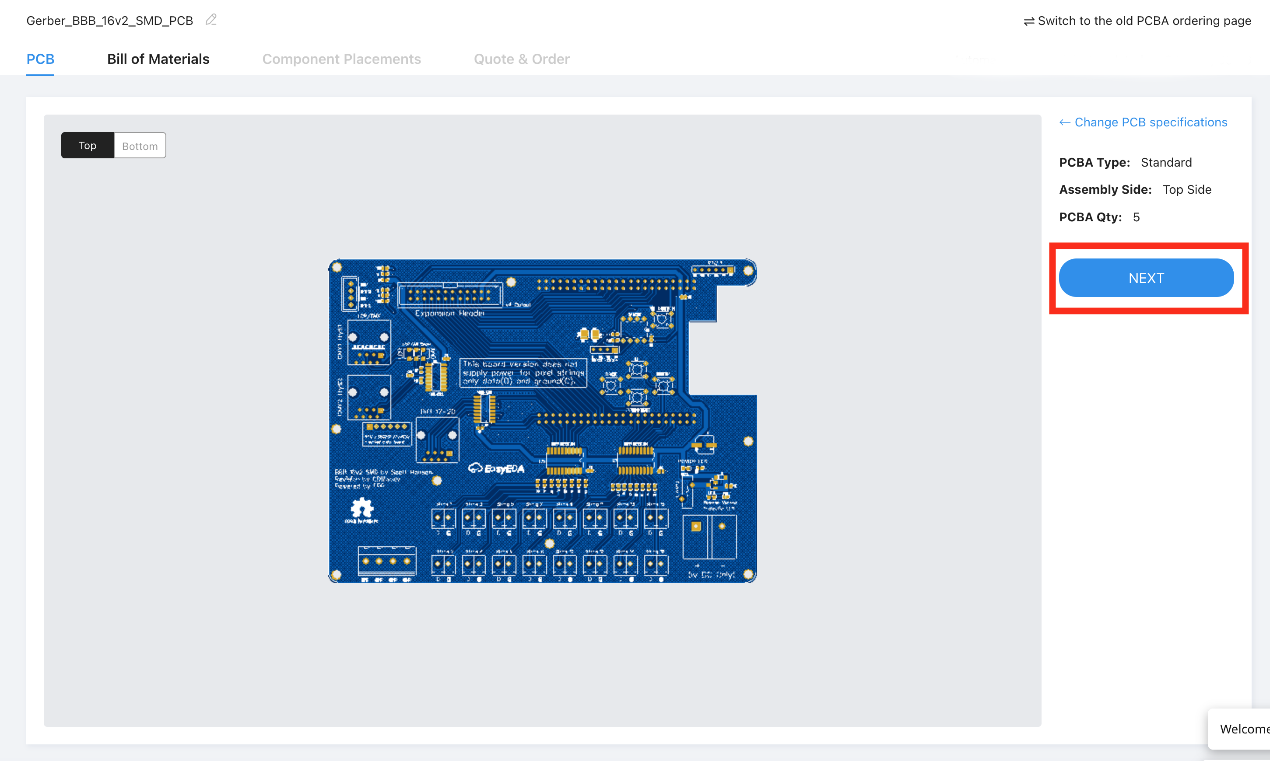
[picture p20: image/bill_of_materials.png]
Bill of Materials Next


### Bill of Materials page

Select the BOM and CPL Files to upload.

* 'BOM_xxxxxxx.xlsx' is the BOM file.
* 'CPL_xxxxxxx.xlsx' is the CPL file.

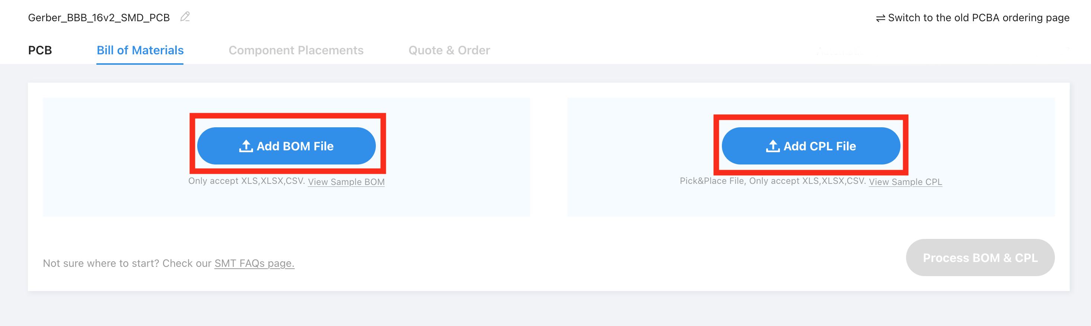
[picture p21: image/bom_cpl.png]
Bom and CPL


* When upload is complete click Procces BOM & CPL

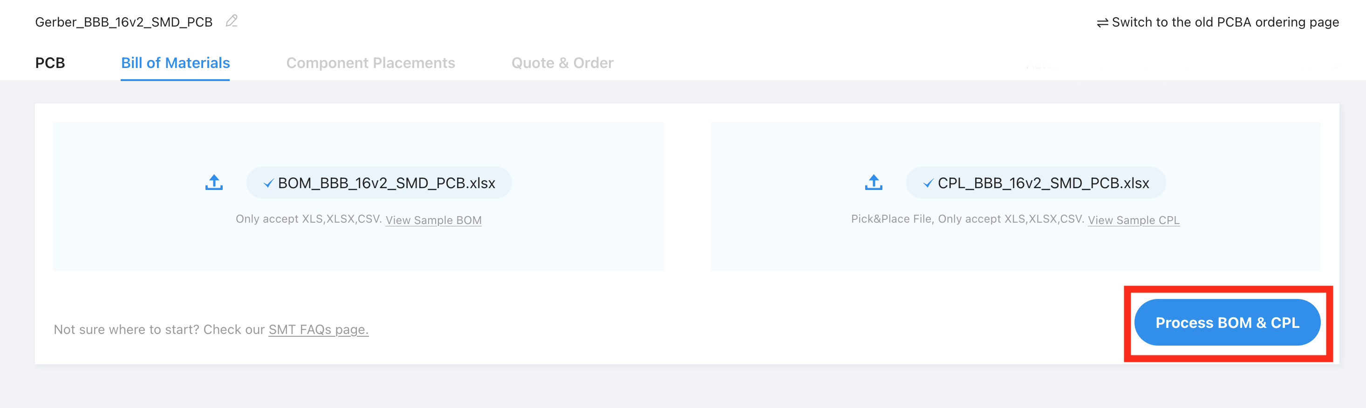
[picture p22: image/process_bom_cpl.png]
Bom and CPL Process


The next page will need to confirm all the BOM parts in the 'BOM_xxxxxxxx.xlsx' file.

* Click "Next"

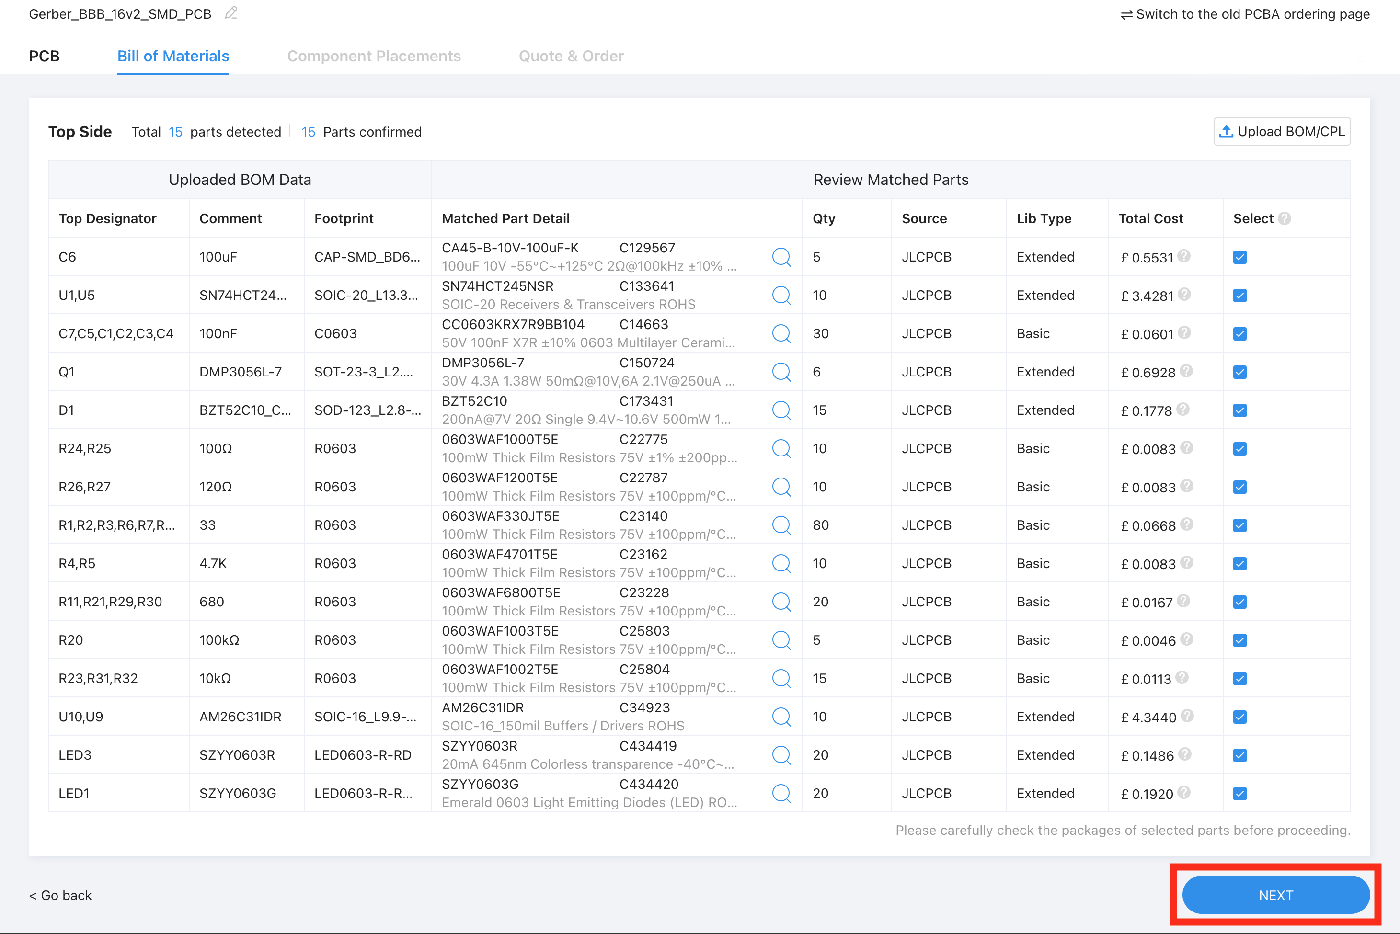
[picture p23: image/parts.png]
Bom Parts


### Component Placements page.

This page will confirm all the SMD part placements in the CPL XLSX file.
* Click "Next"

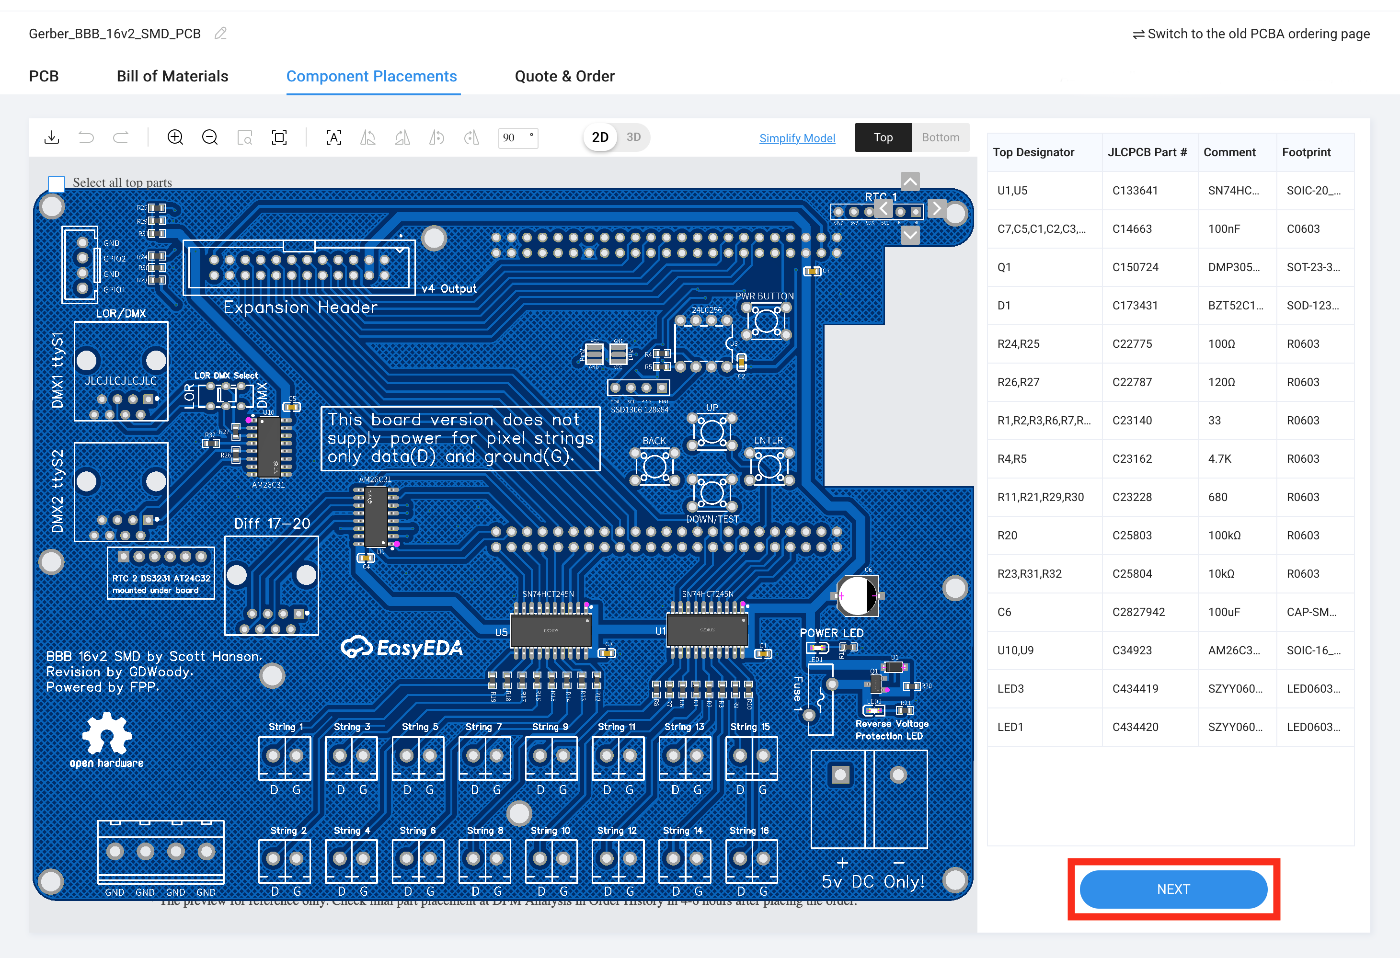
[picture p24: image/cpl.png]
Placement Review


### Order & Quote page.

You will need to choose the 'Product Description', this is used for Customs. I select ' Reserch\Education\DIY\Entertainment / Developnent Board' your choice may be different depending on your circumstances.

* Click Save to Cart and proceed to Checkout and Shipping as normal.

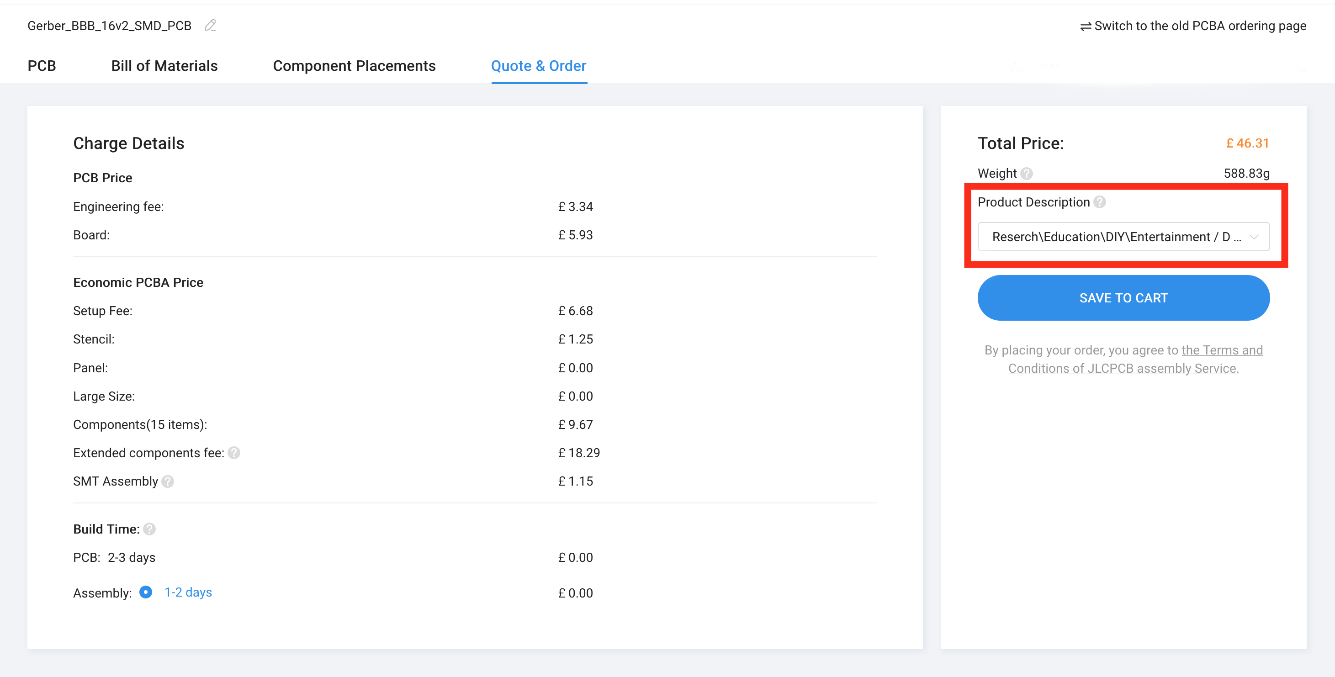
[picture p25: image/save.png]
Order & Quote


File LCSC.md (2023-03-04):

## Ordering Parts from [lcsc.com](https://lcsc.com/)

### Parts to complete PCB's

Download the appropriate 'BOM_xxxxxx_Other_Parts.xlsx' file from the lcsc folder for the board you are making.

* Note: The minimum number of PCB boards that can be ordered from JLCPCB is 5, this BOM file will have enough parts to complete all 5 PCB's.

Go to https://lcsc.com 

* Select BOM Tool

LCSC

Upload the 'BOM_xxxxxx_Other_Parts.xlsx' file

LCSC

* Change 'select type' for the Quantity column to 'Quantity'

* Change 'select type' for the Supplier Part column to 'LCSC Part Number'

* Click "Next"

LCSC

You should now see the uploaded BOM

* Check that all parts are there and in stock

* Note: Some parts have a minimum order quantity, you may need to increase the number of parts to reach the minimum required

* Click "Add To Cart" and proceed to Checkout and Shipping as normal.

LCSC

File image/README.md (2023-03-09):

## Copyright and Disclaimer
Copyright: GDWoody

This documentation describes Open Hardware and is licensed under the CERN Open Hardware License Version 2 - Strongly Reciprocal. (CERN-OHL-S)

You may redistribute and modify this documentation under the terms of the CERN OHL-S-v2 (https://ohwr.org/cern_ohl_s_v2.txt). This documentation is distributed WITHOUT ANY EXPRESS OR IMPLIED WARRANTY, INCLUDING OF MERCHANTABILITY, SATISFACTORY QUALITY AND FITNESS FOR A PARTICULAR PURPOSE. Please see the CERN OHL v2-S for applicable conditions

Under CERN OHL-S-v2, derivative work must be publicly released as defined in subsection 3.3

---
# All boards

* # BBB 16v2

Image of BBB 16v2

* # BBB 16v2 Push Fit

Image of BBB 16v2 Push Fit

* # BBB 8v1

Image of BBB 8v1

* # BBB 8v1 Push Fit

Image of BBB 8v1 Push Fit

* # BBB 4v1

Image of BBB 4v1

* # BBB 4v1 Push Fit

Image of BBB 4v1 Push Fit

* # BBB All Differential

Image of BBB All Differential

## Expansion Boards

* # BBB 16 Expansion Board

Image of BBB 16 Expansion

* # BBB Differential Board

Image of BBB differential Expansion

---
## WLED Boards

* # WLED 4 Port Controller

Image of WLED 4 Port

* # WLED Differential Controller

Image of WLED 4 Port

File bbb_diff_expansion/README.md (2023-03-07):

## Copyright and Disclaimer
Copyright: GDWoody

This documentation describes Open Hardware and is licensed under the CERN Open Hardware License Version 2 - Strongly Reciprocal. (CERN-OHL-S)

You may redistribute and modify this documentation under the terms of the CERN OHL-S-v2 (https://ohwr.org/cern_ohl_s_v2.txt). This documentation is distributed WITHOUT ANY EXPRESS OR IMPLIED WARRANTY, INCLUDING OF MERCHANTABILITY, SATISFACTORY QUALITY AND FITNESS FOR A PARTICULAR PURPOSE. Please see the CERN OHL v2-S for applicable conditions

Under CERN OHL-S-v2, derivative work must be publicly released as defined in subsection 3.3

# Differential Expansion Board

* 4 port Differential Output Expansion Board. 

Image of Diff Expansion Out

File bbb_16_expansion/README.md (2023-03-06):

## Copyright and Disclaimer
Copyright: GDWoody

This documentation describes Open Hardware and is licensed under the CERN Open Hardware License Version 2 - Strongly Reciprocal. (CERN-OHL-S)

You may redistribute and modify this documentation under the terms of the CERN OHL-S-v2 (https://ohwr.org/cern_ohl_s_v2.txt). This documentation is distributed WITHOUT ANY EXPRESS OR IMPLIED WARRANTY, INCLUDING OF MERCHANTABILITY, SATISFACTORY QUALITY AND FITNESS FOR A PARTICULAR PURPOSE. Please see the CERN OHL v2-S for applicable conditions

Under CERN OHL-S-v2, derivative work must be publicly released as defined in subsection 3.3

# 16 Expansion 24 Pin

# Features

* Adds additional 16 local ports

Image of 16 Expansion Out

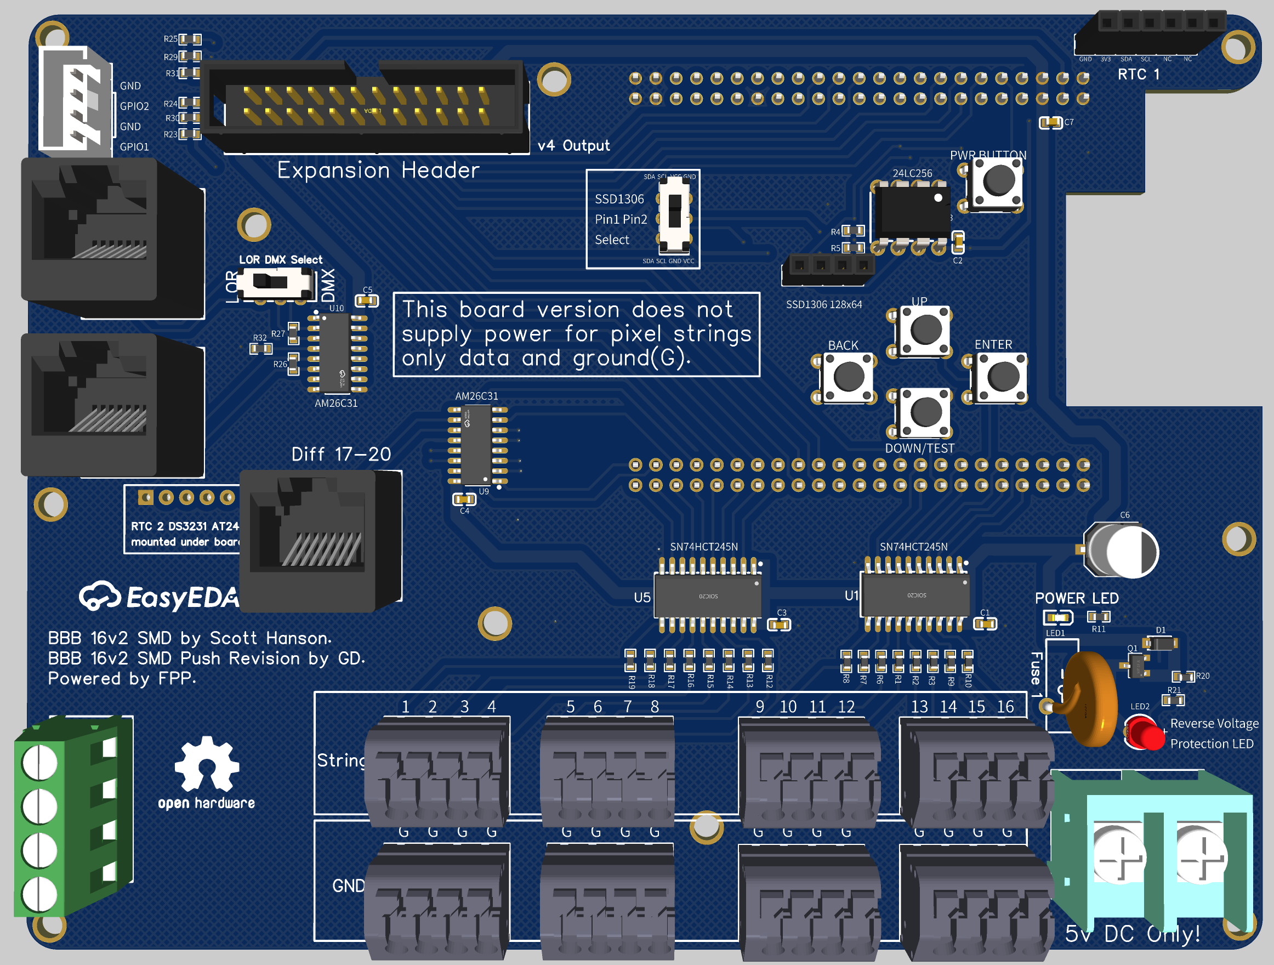
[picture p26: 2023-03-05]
bbb_16_push/image/BBB_16v2_Push_Complete.png

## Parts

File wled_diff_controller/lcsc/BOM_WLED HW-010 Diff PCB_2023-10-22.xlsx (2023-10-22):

ID | Name | Designator | Footprint | Quantity | Manufacturer Part | Manufacturer | Supplier | Supplier Part | Price
1 | 100nF | C3,C4 | C0603 | 2 | CC0603KRX7R9BB104 | YAGEO(国巨) | LCSC | C14663 | 0.002
2 | DMP3056L-7 | Q1 | SOT-23-3_L2.9-W1.6-P1.90-LS2.8-BR-CW | 1 | DMP3056L-7 | DIODES(美台) | LCSC | C150724 | 0.063
3 | 204-10SURD/S530-A3-L | LED2 | LED-TH_BD3.0-P2.54-FD | 1 | 204-10SURD/S530-A3-L | EVERLIGHT(亿光) | LCSC | C99771 | 0.025
4 | 680 | R11,R21 | R0603 | 2 | 0603WAF6800T5E | UNI-ROYAL(厚声) | LCSC | C23228 | 0.001
5 | BZT52C10_C173431 | D1 | SOD-123_L2.8-W1.8-LS3.7-RD | 1 | BZT52C10 | MDD | LCSC | C173431 | 0.012
6 | SZYY0603G | LED1 | LED0603-R-RD_GREEN | 1 | SZYY0603G | yongyu(永裕光电) | LCSC | C434420 | 0.011
7 | WJ301V-5.0-2P | P8,P1,P5,P6 | CONN-TH_2P-P5.00_WJ301V-5.00-2P | 4 | WJ301V-5.0-2P | KANGNEX(康奈克斯电气) | LCSC | C8475 | 0.074
8 | 100kΩ | R20 | R0603 | 1 | 0603WAF1003T5E | UNI-ROYAL(厚声) | LCSC | C25803 | 0.001
9 | WT32-ETH01-GDv2 | U1 | NEW_HW-0103D | 1
10 | 100uF | C1 | CAP-TH_BD8.0-P3.50-D0.6-FD | 1 | KF107M025F05RR0VH2FG0 | CX(承兴) | LCSC | C13376 | 0.024
11 | AM26C31IDR | U2 | SOIC-16_L9.9-W3.9-P1.27-LS6.0-BL | 1 | AM26C31IDR | TI(德州仪器) | LCSC | C34923 | 0.622
12 | DS1134-07-S8B0P | RJ1 | RJ45-TH_DS1134-07-S8B0P | 1 | DS1134-07-S8B0P | CONNFLY | LCSC | C86579 | 0.648
13 | WJ301V-5.0-3P | P4 | CONN-TH_2P-P5.00_WJ301V-5.00-3P | 1 | WJ301V-5.0-3P | KANGNEX(康奈克斯电气) | LCSC | C8483 | 0.112

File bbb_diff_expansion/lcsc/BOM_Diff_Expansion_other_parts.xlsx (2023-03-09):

Name | Designator | Footprint | Quantity | Manufacturer Part | Supplier | Supplier Part
MT5224IWA3DY1027 | RJ1,RJ2,RJ3,RJ4 | RJ45-TH_MINTRON_MT5224IWA3DY1027 | 4 | MT5224IWA3DY1027 | LCSC | C2843197
100uF | C6 | CAP-TH_BD8.0-P3.50-D0.6-FD | 1 | KF107M025F05RR0VH2FG0 | LCSC | C13376
HDR-IDC-2.54-2X12P | P1 | IDC-TH_24P-P2.54-V-R2-C12-S2.54 | 1 | 2.54-2*12P直简牛 | LCSC | C9137

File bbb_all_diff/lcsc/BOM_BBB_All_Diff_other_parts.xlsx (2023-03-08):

Name | Designator | Footprint | Quantity | Manufacturer Part | Supplier | Supplier Part
BBB Headers | U1 | BBB HEADERS | 10 | X6521WV-2x23H-C30D60 | LCSC | C725895
DW254W-11-06-85 | U12 | CONN-TH_6P-P2.54_DEALON_DW254W-11-06-85 | 5 | DW254W-11-06-85 | LCSC | C2935996
204-10SURD/S530-A3-L | LED2 | LED-TH_BD3.0-P2.54-FD | 5 | 204-10SURD/S530-A3-L | LCSC | C99771
SS-3235D-02-L3 | SW7,SW6 | SW-TH_SS-3235D-02-L3 | 10 | SS-3235D-02-L3 | LCSC | C500054
TS665CJ | SW1,SW2,SW3,SW4,SW5 | SW-TH_4P-L6.0-W6.0-P4.50-LS6.5 | 25 | TS665CJ | LCSC | C393938
MT5224IWA3DY1027 | RJ1,RJ2,RJ7,RJ8,RJ9,RJ10,RJ11 | RJ45-TH_MINTRON_MT5224IWA3DY1027 | 35 | MT5224IWA3DY1027 | LCSC | C2843197
HDR-F-2.54_1x4 | H2 | HDR-F-2.54_1X4 | 5 |  | LCSC | C225501
WJ128V-4P-5.0-14-00A | CN1,CN17 | CONN-TH_4P-P5.00_WJ128V-4P-5.0-14-00A | 10 | WJ128V-5.0-4P | LCSC | C192769
JK16-500_C369117 | F1 | FUSE-TH_L11.5-W3.8-P5.08-D1.0-S3.8 | 5 | JK16-500 | LCSC | C369117
XHB-4A(White)/4needle | P2 | CONN-TH_4P_XHB-4A | 5 | XHB-4A | LCSC | C61277
24LC256-I/P | U3 | PDIP-8_L9.3-W6.4-P2.54-LS7.6-BL | 5 | 24LC256-I/P | LCSC | C411624
HDR-F-2.54_1x6 | H1 | HDR-F-2.54_1X6 | 5 |  | LCSC | C40877
DBT50P-9.5-2P-GN | U4 | CONN-TH_2P-P9.50_L16.0-W19.0-EX4.0 | 5 | DBT50P-9.5-2P-GN-P | LCSC | C496129
HDR-IDC-2.54-2X12P | P1 | IDC-TH_24P-P2.54-V-R2-C12-S2.54 | 5 | 2.54-2*12P直简牛 | LCSC | C9137
CONNFLY Elec DS1009-08AT1NX-0A2 |  |  | 5 | DS1009-08AT1NX-0A2 | LCSC | C72124

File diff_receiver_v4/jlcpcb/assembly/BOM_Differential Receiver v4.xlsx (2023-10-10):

ID | Name | Designator | Footprint | Quantity | Manufacturer Part | Manufacturer | Supplier | Supplier Part | Price | Pins
1 | 100nF | C3,C4 | C0603 | 2 | CC0603KRX7R9BB104 | YAGEO(国巨) | LCSC | C14663 | 0.002 | 2
2 | DMP3056L-7 | Q1 | SOT-23-3_L2.9-W1.6-P1.90-LS2.8-BR-CW | 1 | DMP3056L-7 | DIODES(美台) | LCSC | C150724 | 0.063 | 3
3 | 0805G (Green) | LED2 | LED0805-R-RD | 1 | KT-0805翠绿 | KENTO | LCSC | C2297 | 0.014 | 2
4 | MT5224IWA3DY1027 | RJ1 | RJ45-TH_MINTRON_MT5224IWA3DY1027 | 1 | MT5224IWA3DY1027 | MINTRON(明硕) | LCSC | C2843197 | 0.199 | 8
5 | KF250-3.5-4P-2 | CN6,CN7 | CONN-TH_4P-P3.50_KF250-3.5-4P-2 | 2 | KF250-3.5-4P-2 | KEFA(科发) | LCSC | C475165 | 0.225 | 4
6 | 204-10SURD/S530-A3-L | LED1 | LED-TH_BD3.0-P2.54-FD | 1 | 204-10SURD/S530-A3-L | EVERLIGHT(亿光) | LCSC | C99771 | 0.025 | 2
7 | 33 | R1,R2,R3,R4 | R0603 | 4 | RC0603FR-0733RL | YAGEO(国巨) | LCSC | C108661 | 0.001 | 2
8 | 120 | R5,R6,R7,R8 | R0603 | 4 | RC0603FR-07120RL | YAGEO(国巨) | LCSC | C114640 |  | 2
9 | 330 | R12 | R0603 | 1 | 0603WAF3300T5E | UNI-ROYAL(厚声) | LCSC | C23138 | 0.001 | 2
10 | 680 | R21 | R0603 | 1 | 0603WAF6800T5E | UNI-ROYAL(厚声) | LCSC | C23228 | 0.001 | 2
11 | WJ128V-4P-5.0-14-00A | CN1 | CONN-TH_4P-P5.00_WJ128V-4P-5.0-14-00A | 1 | WJ128V-5.0-4P | KANGNEX(康奈克斯电气) | LCSC | C192769 | 0.192 | 4
12 | 100uF | C1 | CAP-TH_BD8.0-P3.50-D0.6-FD | 1 | KF107M025F05RR0VH2FG0 | CX(承兴) | LCSC | C13376 | 0.024 | 2
13 | BZT52C10_C173431 | D1 | SOD-123_L2.8-W1.8-LS3.7-RD | 1 | BZT52C10 | MDD | LCSC | C173431 | 0.012 | 2
14 | 100kΩ | R20 | R0603 | 1 | 0603WAF1003T5E | UNI-ROYAL(厚声) | LCSC | C25803 | 0.001 | 2
15 | AM26C32IDR | U1 | SOIC-16_L9.9-W3.9-P1.27-LS6.0-BL | 1 | AM26C32IDR | TI(德州仪器) | LCSC | C36693 | 0.667 | 16
16 | DBT50P-9.5-2P-GN | U2 | CONN-TH_2P-P9.50_L16.0-W19.0-EX4.0 | 1 | DBT50P-9.5-2P-GN-P | DIBO(地博电气) | LCSC | C496129 | 0.198 | 2
17 | SN74AHCT125DR | U13 | SOIC-14_L8.7-W3.9-P1.27-LS6.0-BL | 1 | SN74AHCT125DR | TI(德州仪器) | LCSC | C155176 | 0.211 | 14

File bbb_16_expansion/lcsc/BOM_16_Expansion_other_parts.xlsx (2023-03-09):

Name | Designator | Footprint | Quantity | Manufacturer Part | Supplier | Supplier Part
KF2EDGV-3.81-2P | CN1,CN2,CN3,CN4,CN5,CN6,CN7,CN8,CN9,CN10,CN11,CN12,CN13,CN14,CN15,CN16 | CONN-TH_2P-P3.81_KF2EDGV-3.81-2P | 80 | KF2EDGV-3.81-2P | LCSC | C441332
HDR-IDC-2.54-2X12P | P1 | IDC-TH_24P-P2.54-V-R2-C12-S2.54 | 5 | 2.54-2*12P直简牛 | LCSC | C9137
100uF | C6 | CAP-TH_BD8.0-P3.50-D0.6-FD | 5 | KF107M025F05RR0VH2FG0 | LCSC | C13376

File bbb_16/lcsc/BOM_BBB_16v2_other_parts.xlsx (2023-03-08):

Name | Designator | Footprint | Quantity | Manufacturer Part | Supplier | Supplier Part
BBB Headers | U8 | BBB HEADERS | 10 | X6521WV-2x23H-C30D60 | LCSC | C725895
DW254W-11-06-85 | U12 | CONN-TH_6P-P2.54_DEALON_DW254W-11-06-85 | 5 | DW254W-11-06-85 | LCSC | C2935996
SS-3235D-02-L3 | SW7,SW6 | SW-TH_SS-3235D-02-L3 | 10 | SS-3235D-02-L3 | LCSC | C500054
204-10SURD/S530-A3-L | LED2 | LED-TH_BD3.0-P2.54-FD | 5 | 204-10SURD/S530-A3-L | LCSC | C99771
HDR-F-2.54_1x4 | H2 | HDR-F-2.54_1X4 | 5 |  | LCSC | C2718488
TS665CJ | SW1,SW2,SW3,SW4,SW5 | SW-TH_4P-L6.0-W6.0-P4.50-LS6.5 | 25 | TS665CJ | LCSC | C393938
MT5224IWA3DY1027 | RJ3,RJ4,RJ5 | RJ45-TH_MINTRON_MT5224IWA3DY1027 | 15 | MT5224IWA3DY1027 | LCSC | C2843197
KF2EDGV-3.81-2P | CN2,CN3,CN4,CN5,CN6,CN7,CN8,CN9,CN10,CN11,CN12,CN13,CN14,CN15,CN16,CN1 | CONN-TH_2P-P3.81_KF2EDGV-3.81-2P | 80 | KF2EDGV-3.81-2P | LCSC | C441332
WJ128V-4P-5.0-14-00A | CN17 | CONN-TH_4P-P5.00_WJ128V-4P-5.0-14-00A | 5 | WJ128V-5.0-4P | LCSC | C192769
JK16-500_C369117 | F1 | FUSE-TH_L11.5-W3.8-P5.08-D1.0-S3.8 | 5 | JK16-500 | LCSC | C369117
XHB-4A(White)/4needle | P2 | CONN-TH_4P_XHB-4A | 5 | XHB-4A | LCSC | C61277
24LC256-I/P | U3 | PDIP-8_L9.3-W6.4-P2.54-LS7.6-BL | 5 | 24LC256-I/P | LCSC | C411624
HDR-F-2.54_1x6 | H1 | HDR-F-2.54_1X6 | 5 |  | LCSC | C40877
DBT50P-9.5-2P-GN | U4 | CONN-TH_2P-P9.50_L16.0-W19.0-EX4.0 | 5 | DBT50P-9.5-2P-GN-P | LCSC | C496129
HDR-IDC-2.54-2X12P | P1 | IDC-TH_24P-P2.54-V-R2-C12-S2.54 | 5 | 2.54-2*12P直简牛 | LCSC | C9137
CONNFLY Elec DS1009-08AT1NX-0A2 |  |  | 5 | DS1009-08AT1NX-0A2 | LCSC | C72124
Cixi Kefa Elec KF2EDGK-3.81-2P |  |  | 80 | KF2EDGK-3.81-2P | LCSC | C440858

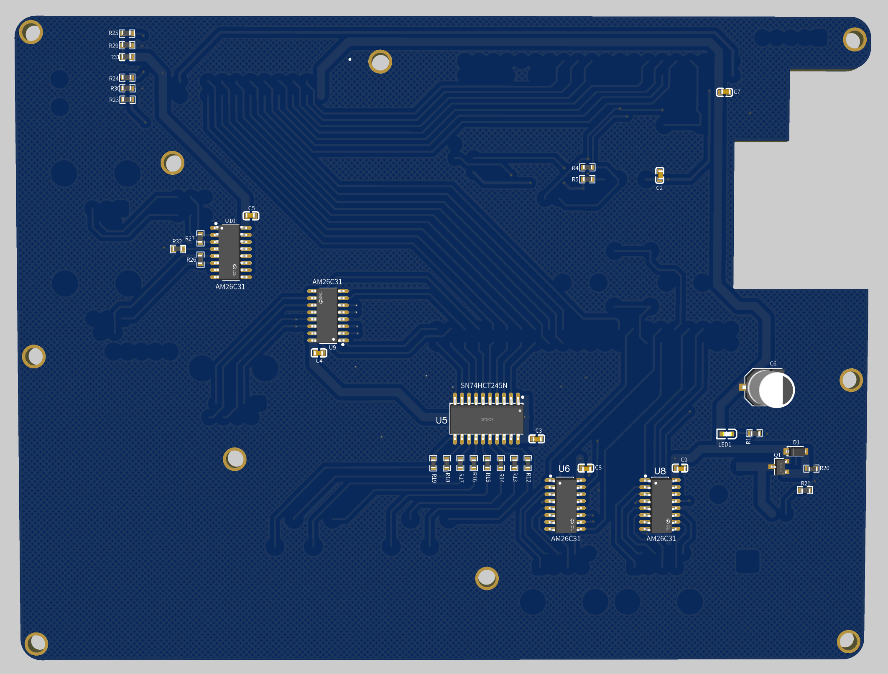
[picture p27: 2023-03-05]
bbb_8_push/image/BBB_8v1_SMD_Push_Parts.png

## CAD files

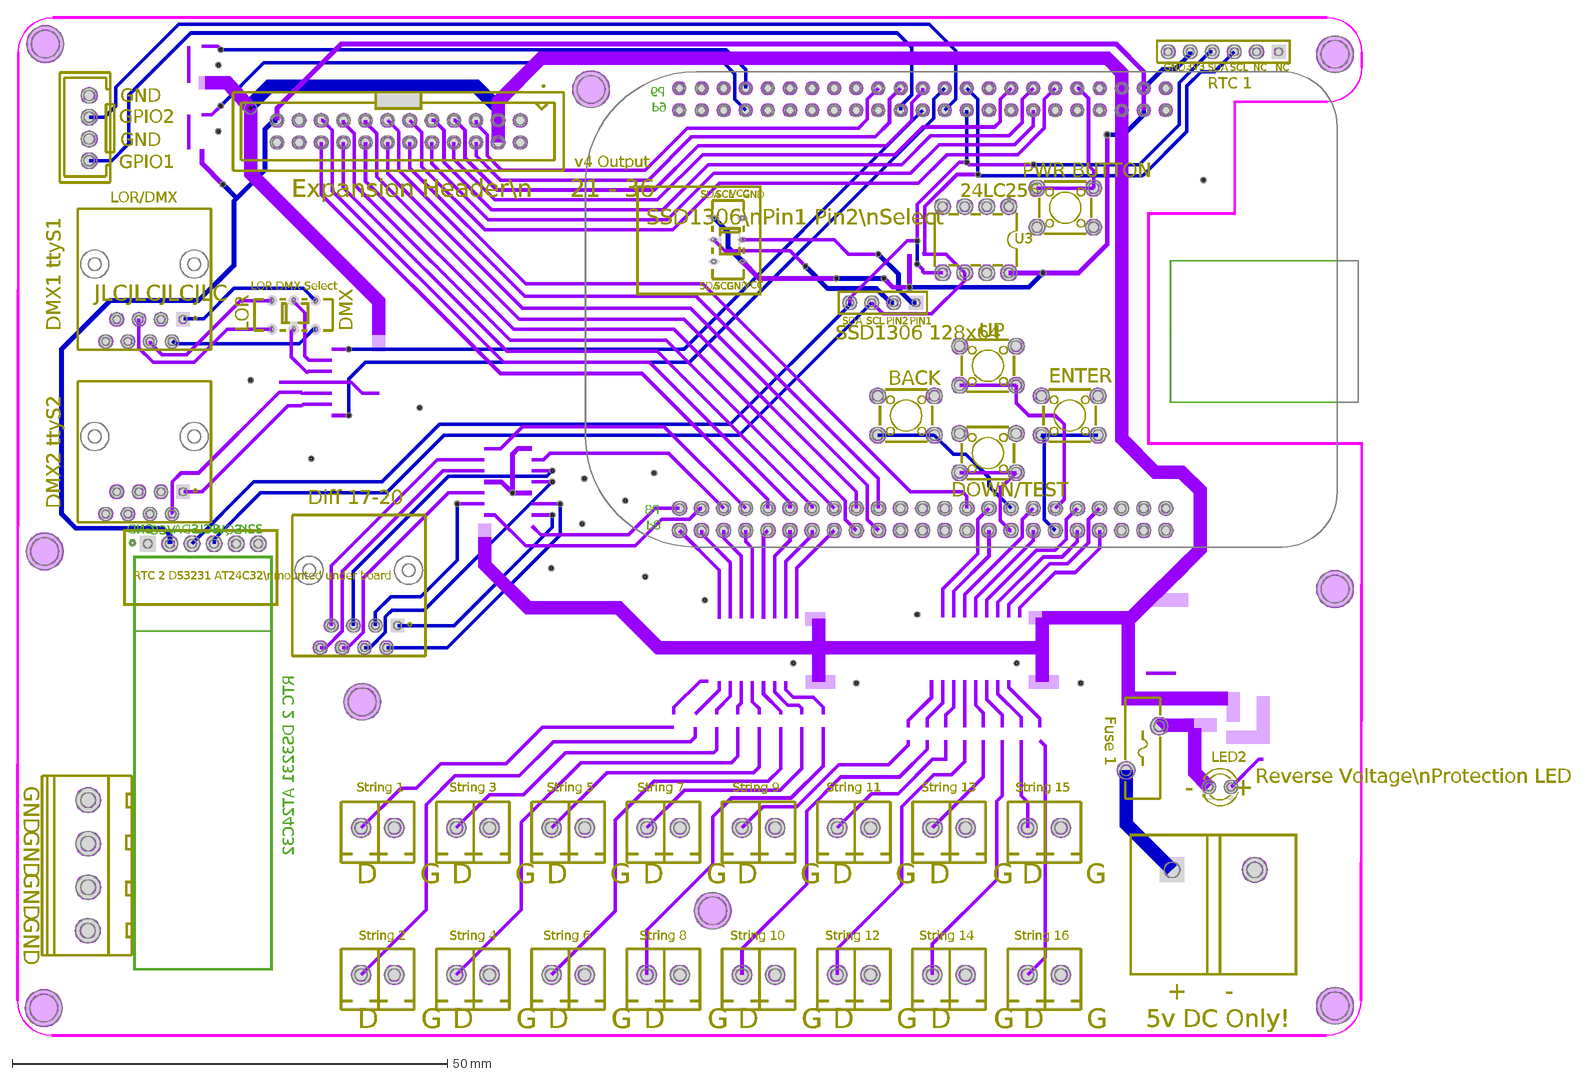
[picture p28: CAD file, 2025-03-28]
bbb_16/dfx/BBB-16v2-SMD-PCB-No-SMD-copy_2025-03-28.dxf
32K
SQW
SCL
SDA
VCC
GND
RTC 2 DS3231 AT24C32
DMX1 ttyS1
DMX2 ttyS2
UP
DOWN/TEST
ENTER
BACK
PWR BUTTON
RTC 1
3V3
Diff 17-20
+ -
5v DC Only!
JLCJLCJLCJLC
GPIO1
GPIO2
String 1
String 3
String 5
String 7
String 9
String 11
String 13
String 15
D G
String 8
String 16
String 14
String 12
String 10
String 6
String 4
String 2
SSD1306 128x64
v4 Output
24LC256
Fuse 1
NC
RTC 2 DS3231 AT24C32\nmounted under board
DMX
LOR
LOR DMX Select
LOR/DMX
Reverse Voltage\nProtection LED
-
+
SSD1306\nPin1 Pin2\nSelect
Expansion Header\n 21 - 36
PIN1
PIN2
P9
P8
LED2
U3

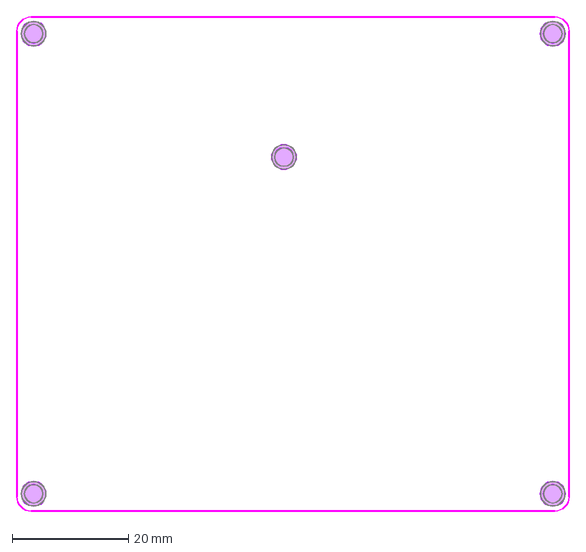
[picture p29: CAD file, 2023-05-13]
bbb_16_expansion/dfx/16 Expansion PCB Mount.dxf
95.3 x 85.3 mm

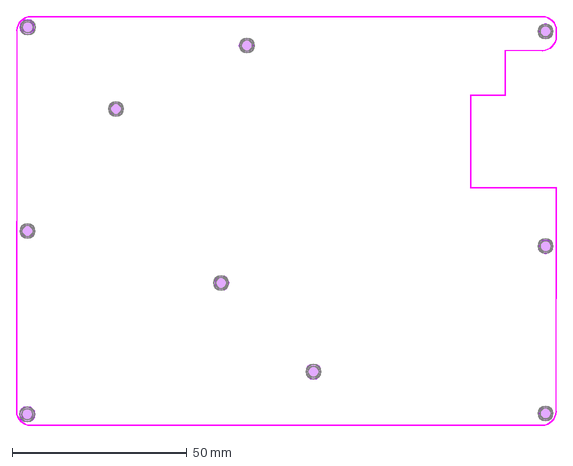
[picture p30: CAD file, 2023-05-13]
bbb_16_push/dfx/BBB 16v2 SMD Push Mount.dxf
154.7 x 117.2 mm

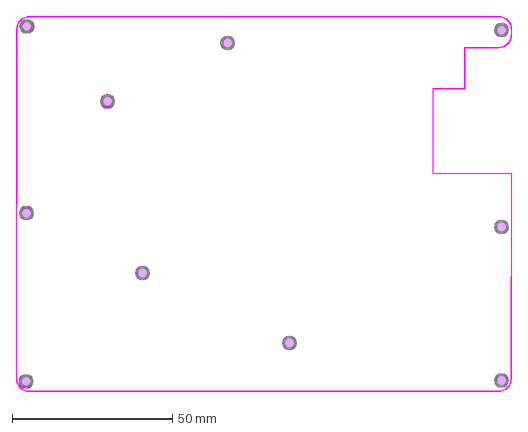
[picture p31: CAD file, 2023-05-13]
bbb_8_push/dfx/BBB 8v1 SMD PCB Push Mount.dxf
154.7 x 117.2 mm

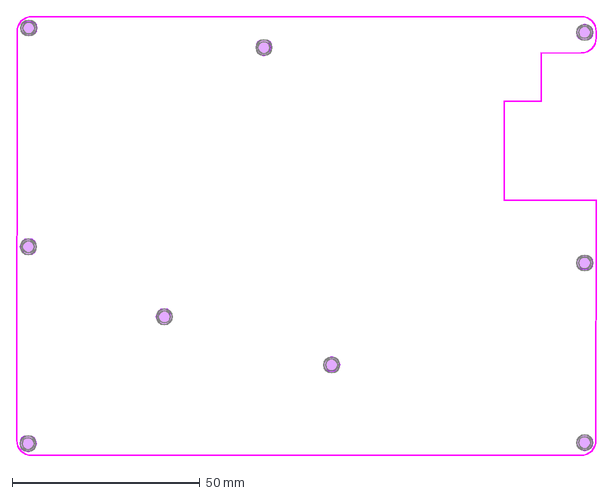
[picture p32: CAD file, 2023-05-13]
bbb_all_diff/dfx/BBB All Diff SMD Mount.dxf
154.7 x 117.2 mm

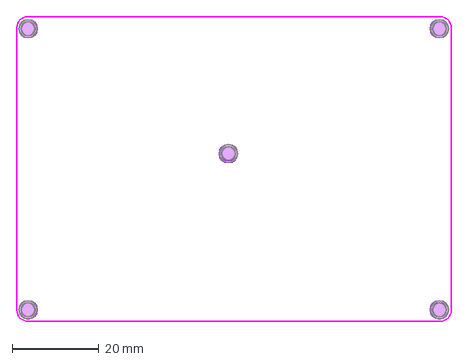
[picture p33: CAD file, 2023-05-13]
bbb_diff_expansion/dfx/Diff Expansion Mount.dxf
100.2 x 70.3 mm

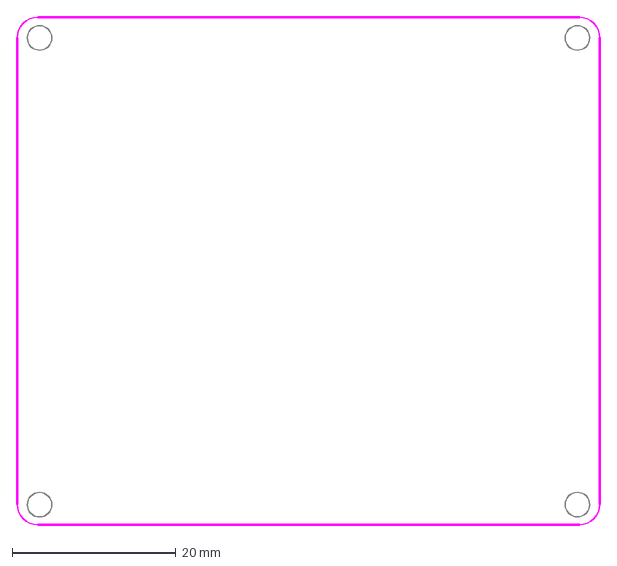
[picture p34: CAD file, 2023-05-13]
diff_receiver_v4/dfx/Differential Receiver v4 Mount.dxf
71.4 x 62.3 mm

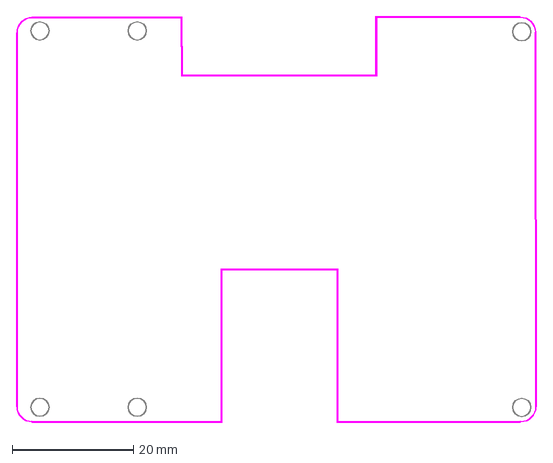
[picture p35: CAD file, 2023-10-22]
wled_diff_controller/dfx/WLED HW-010 Diff PCB.dxf
85.7 x 66.9 mm

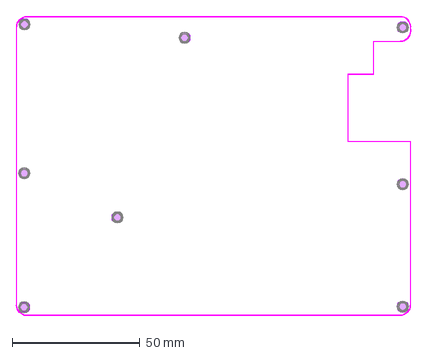
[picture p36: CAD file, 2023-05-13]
bbb_16/dfx/BBB 16v2 SMD Mount.dxf
154.7 x 117.2 mm

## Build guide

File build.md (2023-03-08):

## Copyright and Disclaimer
Copyright: GDWoody

This documentation describes Open Hardware and is licensed under the CERN Open Hardware License Version 2 - Strongly Reciprocal. (CERN-OHL-S)

You may redistribute and modify this documentation under the terms of the CERN OHL-S-v2 (https://ohwr.org/cern_ohl_s_v2.txt). This documentation is distributed WITHOUT ANY EXPRESS OR IMPLIED WARRANTY, INCLUDING OF MERCHANTABILITY, SATISFACTORY QUALITY AND FITNESS FOR A PARTICULAR PURPOSE. Please see the CERN OHL v2-S for applicable conditions

Under CERN OHL-S-v2, derivative work must be publicly released as defined in subsection 3.3

---
## JLCPCB PCB's and LCSC Part Ordering
Following the instructions below your boards will arrive with only the SMD components fitted. To complete them you will also need to get and fit the 'Additional Components'.  

## To order PCB's From JLCPCB:

* All the files needed to order from [**jlcpcb.com**](https://jlcpcb.com) can be found in the jlcpcb/gerber and jlcpcb/assembly folders for each board.

* Select the board you wish to make

* Download the  **Gerber_xxxxxxx.zip** from the jlcpcb\gerber folder.

* Download the  **BOM_xxxxxxx.xlsx** file in the jlcpcb\assembly folder.

* Download the **CPL_xxxxxxx.xlsx** file in the jlcpcb\assembly folder.

*  Goto [**jlcpcb.com**](https://jlcpcb.com), sign in or make a new account, select Instant Quote and Upload the the Gerber_xxxxxx.zip file.

* The default settings should be ok. However you can choose 'PCB Color' and change 'Remove Order Number' to 'Specify a location'.

* Enable the SMD service, 'BOM_xxxxxxx.xlsx' is the BOM file and 'CPL_xxxxxxx.xlsx' is the CPL file.

* [**See here for detailed PCB ordering instructions for JLCPCB**](https://github.com/GDWoody/Pixel-Controllers/blob/main/JLC_PCB.md)

## To order Additional Required Parts from LCSC

* All the files needed to order from [**lcsc.com**](https://lcsc.com) can be found in the lcsc/ folders for each board.

* Download the **BOM_xxxxxxx_Other_Parts.xlsx** file in the lcsc folder.

* Goto [**lcsc.com**](https://lcsc.com), sign in or make a new account and select 'BOM Tool' and upload the BOM_xxxxxxx_Other_Parts.xlsx file.

* [**See here for detailed Parts ordering instructions for LCSC**](https://github.com/GDWoody/Pixel-Controllers/blob/main/LCSC.md)

## [**Controller DIY Build Instructions**](https://github.com/GDWoody/Pixel-Controllers/blob/main/Controller_DIY.md)

---
## Additional Hardware Required

* A good quality SD card with FPP installed on it. FPP images can be found at [**https://github.com/FalconChristmas/fpp/releases**](https://github.com/FalconChristmas/fpp/releases)

* A BeagleBone Black, BeagleBone Black Wireless, BeagleBone Green, or SanCloud BeagleBone enhanced 

* A SSD1306 128x64 OLED Display

---
Be sure to fit these three parts to the **underside**.

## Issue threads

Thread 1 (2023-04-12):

Question about a suitable receiver

joelhauxwell, 2023-04-12:
Hello,

I have been 'upgrading' my addressable LED strips to work with differential signals and your bbb_all_diff looks ideal for the transmit end.

My design for the receive end is using the SN75176AP IC.... do you have any idea if this will work with the AM26C31 you have used for the transmitter?

This is what I have done for the start of every strip:

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

If not, it would be great if I could find something pin compatible for my RX.

Cheers,

Joel.

GDWoody, 2023-04-12:
Hi Joel,

I don't know if a SN75176AP will work with an AM26C31, however, if you let me know a bit more about your project like what controller, how many outputs etc I might be able to come up with a solution for you.

joelhauxwell, 2023-04-12:
Hi,

Thanks for getting back to me.

Ideally, I just need to come up with a compatible single channel receiver for your bbb_all_diff controller.  I would like to make it fit within the same physical size as the PCB I had already made if possible.

I have a load of WS2812B strips mounted in aluminium extrusion and preparing for Christmas 2023! - differential wiring will make it so much easier to hook up.

If you could recommend a suitable receiver for the AM26C31 that would be great - even better if there is a something single channel (and small!).

GDWoody, 2023-04-12:
Joel,

Sure, what are the dimensions of your board?

joelhauxwell, 2023-04-12:
Here is the board:

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

If I can keep the mounting holes in the same place that would be advantageous.

Im happy to switch out to SMD components to save some space....

GDWoody, 2023-04-12:
Hi,

Could something like this work for you?

ESP32 WT32-ETH01 WLED Controller with 4 SN75176AP Transceivers.

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

joelhauxwell, 2023-05-13:
Just an update in this - the SN75176AP works well!

This is the very basic schematic for the receiver:

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

Its actually the same as Scott Hanson used on his 'Single Receiver Out"

https://github.com/computergeek1507/PB_16/blob/master/Single_Receiver_Out/Single_Receiver_Out.pdf

Thanks,

Joel.

Closed 2023-05-13.

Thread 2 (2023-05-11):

Cape dropdown in FPP - what now?

joelhauxwell, 2023-05-11:
Hello,

I went ahead and ordered some PBCs from JLCPCB and finished the assembly (the BBB_all_diff) board - they look great!

I've installed FPP and in the Initial Setup screen there is a drop-down list for the installed cape, but I'm not sure which one to choose:

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

Should i have done anything with the EEPROM yet?

Sorry if this is documented somewhere, I haven't been able to find much information.

Thanks,

Joel.

GDWoody, 2023-05-11:
Hi,

Thanks for using one of my controllers.

What version of FPP did you install? I am still on 5.5 as I have been waiting months for vouchers for FPP 6 but looks like it's not going to happen, so I will stick with 5.5.

You need to go here to download the eeprom.bin
https://github.com/GDWoody/Pixel-Controllers/tree/main/eeprom

Then here and follow Scott's instructions on how to install  https://github.com/computergeek1507/PB_16/blob/master/Flashing_EEPROM.md

After installing the bin file and rebooting go to the About Page should see the cape as Scott's BBB 16 SMDv2.1.

My controllers work fine on FPP 5.5

joelhauxwell, 2023-05-13:
I had installed the latest version, but as you have had no problem with 5.5 i ended up using that.

The EEPROM flashed successfully and ive been able to test with xlights - awesome!

I would like to 3D print some cases/mounts, are you able to export a DXF from EASYEDA with the board outline and mounting holes?

Thanks,

Joel.

GDWoody, 2023-05-13:
Good to hear you got it working.

You can find the DFX here.

bbb_all_diff/dfx/BBB All Diff SMD Mount.dxf

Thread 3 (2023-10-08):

Gerbers for diff_receiver

joelhauxwell, 2023-10-08:
Hey,

Would it be possible to upload the gerbers/JLCPCB files for the diff_receiver boards? - I am particularly interested in the fixed screw terminal version.

Cheers,

Joel.

GDWoody, 2023-10-10:
Hi,

Uploaded the JLCPCB files for the diff_receiver with screw terminals.

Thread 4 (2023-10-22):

Gerbers for WLED differential TX

joelhauxwell, 2023-10-22:
Hi again,

I think this will be the last thing I ask for....please could you upload the JLCPCB assembly files for your WLED differential TX board?

Cheers,

Joel.

GDWoody, 2023-10-22:
Hi,

No problem, WLED differential TX files uploaded.

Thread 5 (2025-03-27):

BBB16 DXF Export - With more layers

joelhauxwell, 2025-03-27:
Hello there,

I know a while back you kindly exported the board outline for me to assist with mounting for the BBB16 all diff board.

I have just received 10 of the BBB16 'standard' boards from JLCPCB for me and a friend for our 2025 Christmas lights.  I need to populate all the through hole connectors and i'd like to 3D print a jig to make it faster and easier.

Would it be possible to export DXFs with more of the layers so i can do this?

Thanks!

Joel

GDWoody, 2025-03-27:
Hi, sure, which board? BBB16 v2 SMD Mount?

joelhauxwell, 2025-03-27:
Hi, that's great - thanks!

Yes, it's the BBB16 v2 SMD Mount.

Cheers,

Joel.

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

GDWoody, 2025-03-28:
Hi, does this help?

joelhauxwell, 2025-03-28:
Hi - that is exactly what I was looking for....super helpful.

Thanks again for sharing your designs - they are awesome.

Joel.

joelhauxwell, 2025-04-23:
Hello again,

I Just wanted to let you know that the jig worked great and I have populated 10 boards-

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

Cheers,

Joel.

GDWoody, 2025-04-23:
Hi Joel, the jigs look fantastic! Would you be able to share the printer files with me?

joelhauxwell, 2025-04-23:
Here is the STL as promised.

Cheers!

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

joelhauxwell, 2025-04-23:
I had to zip it up as STLs aren't allowed to be uploaded here - hope it works!

[BBB16 SMD Thru Hole Connector Jig.zip](https://github.com/user-attachments/files/19873785/BBB16.SMD.Thru.Hole.Connector.Jig.zip)

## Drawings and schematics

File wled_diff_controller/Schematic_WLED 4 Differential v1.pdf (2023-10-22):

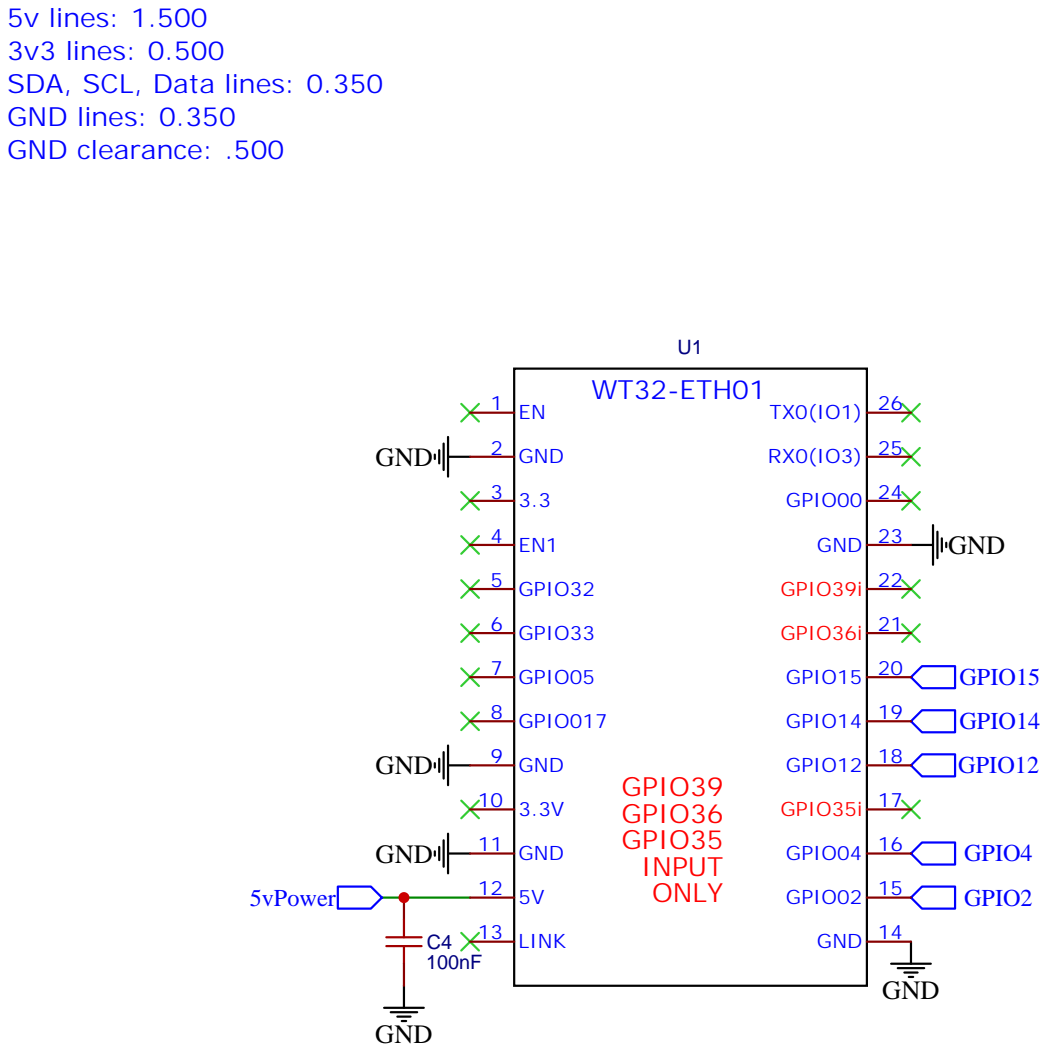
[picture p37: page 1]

5v lines: 1.500
3v3 lines: 0.500
SDA, SCL, Data lines: 0.350
GND lines: 0.350
GND clearance: .500

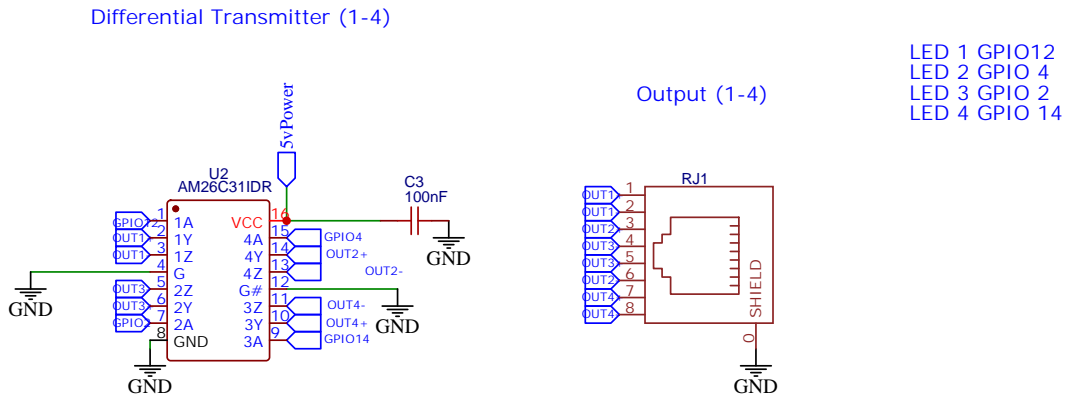
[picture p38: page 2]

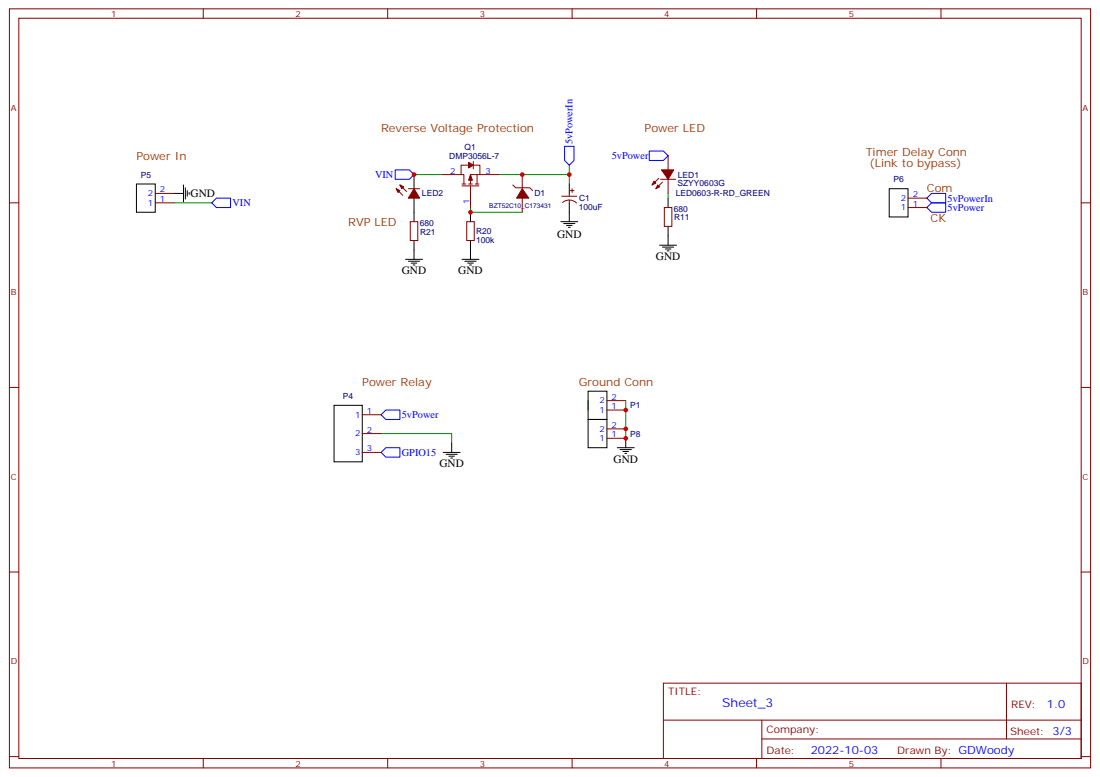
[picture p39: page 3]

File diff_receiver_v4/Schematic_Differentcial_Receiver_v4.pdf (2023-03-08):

# Receiver

+5V

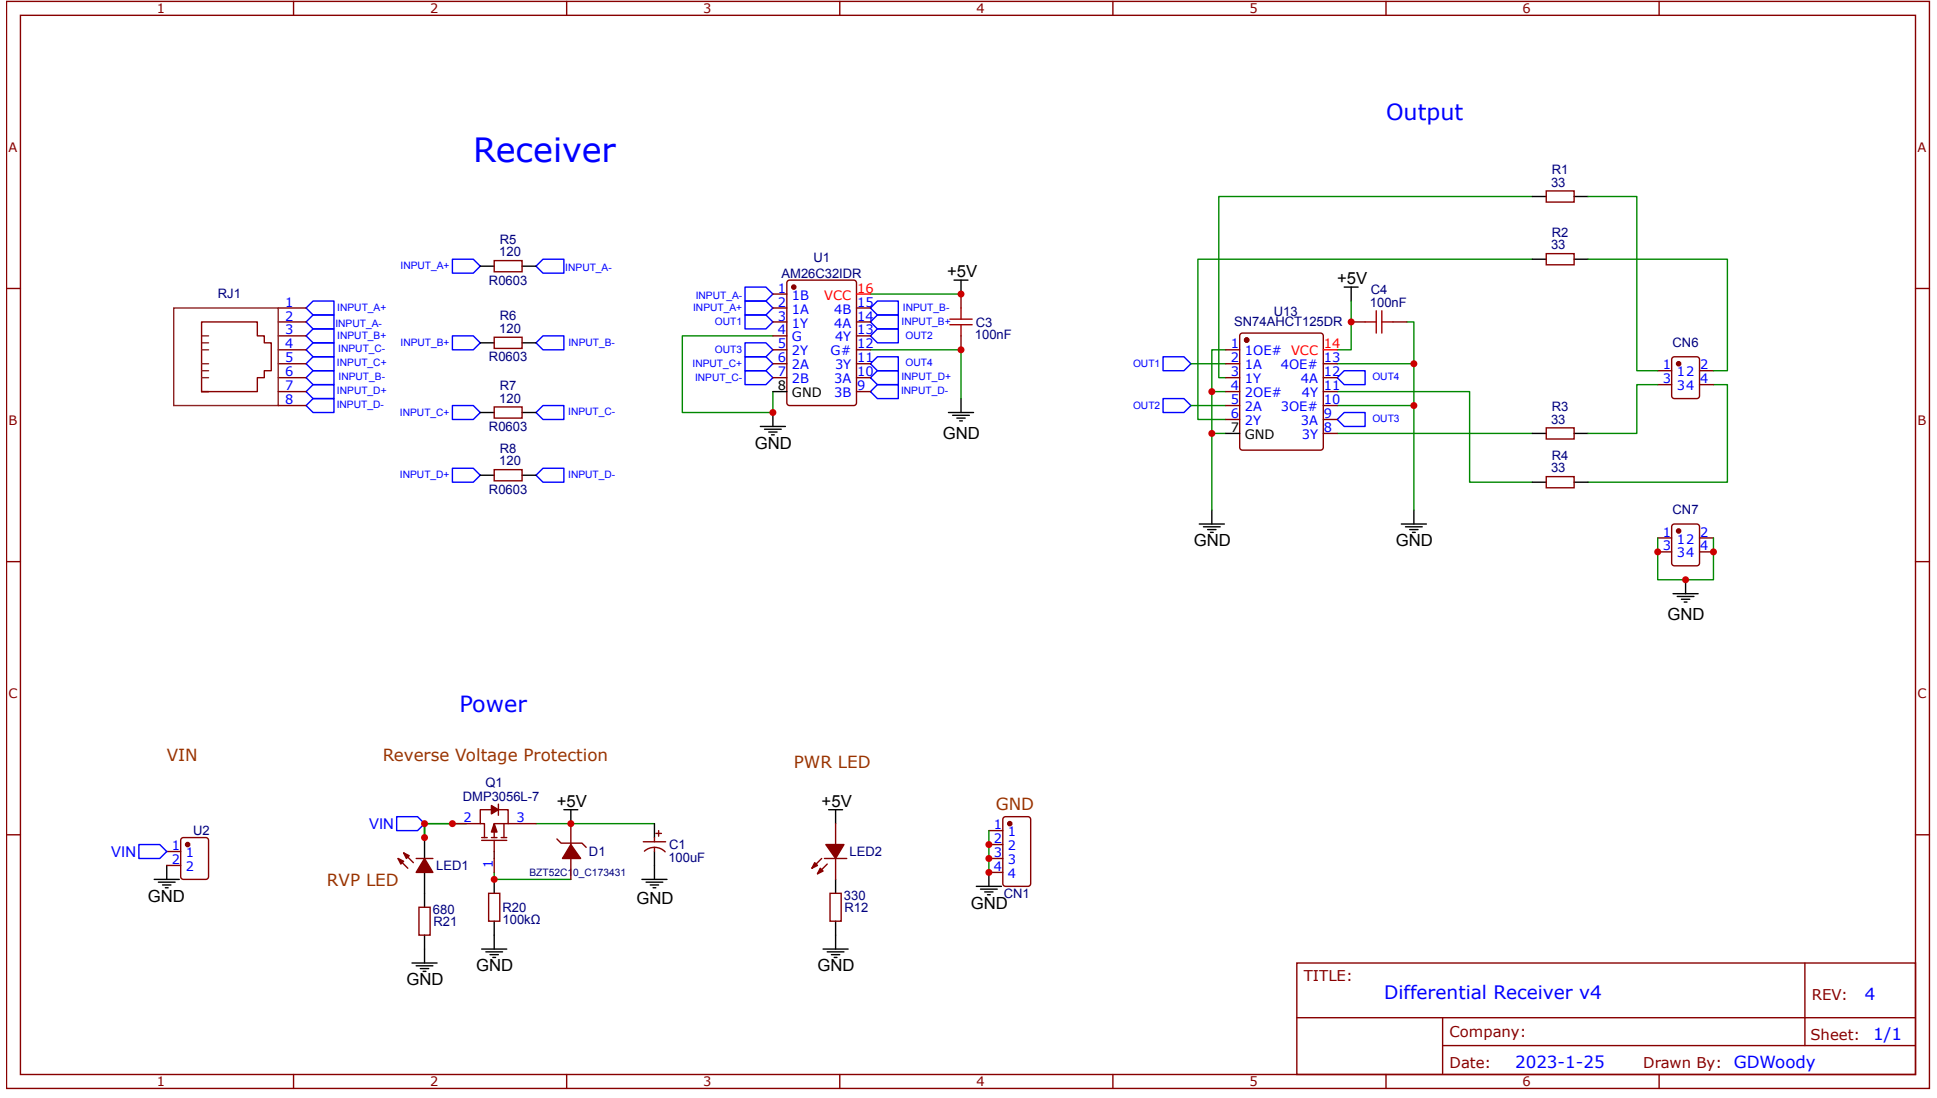
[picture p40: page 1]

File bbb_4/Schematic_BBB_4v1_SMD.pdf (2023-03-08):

### Power In Power In Fuse

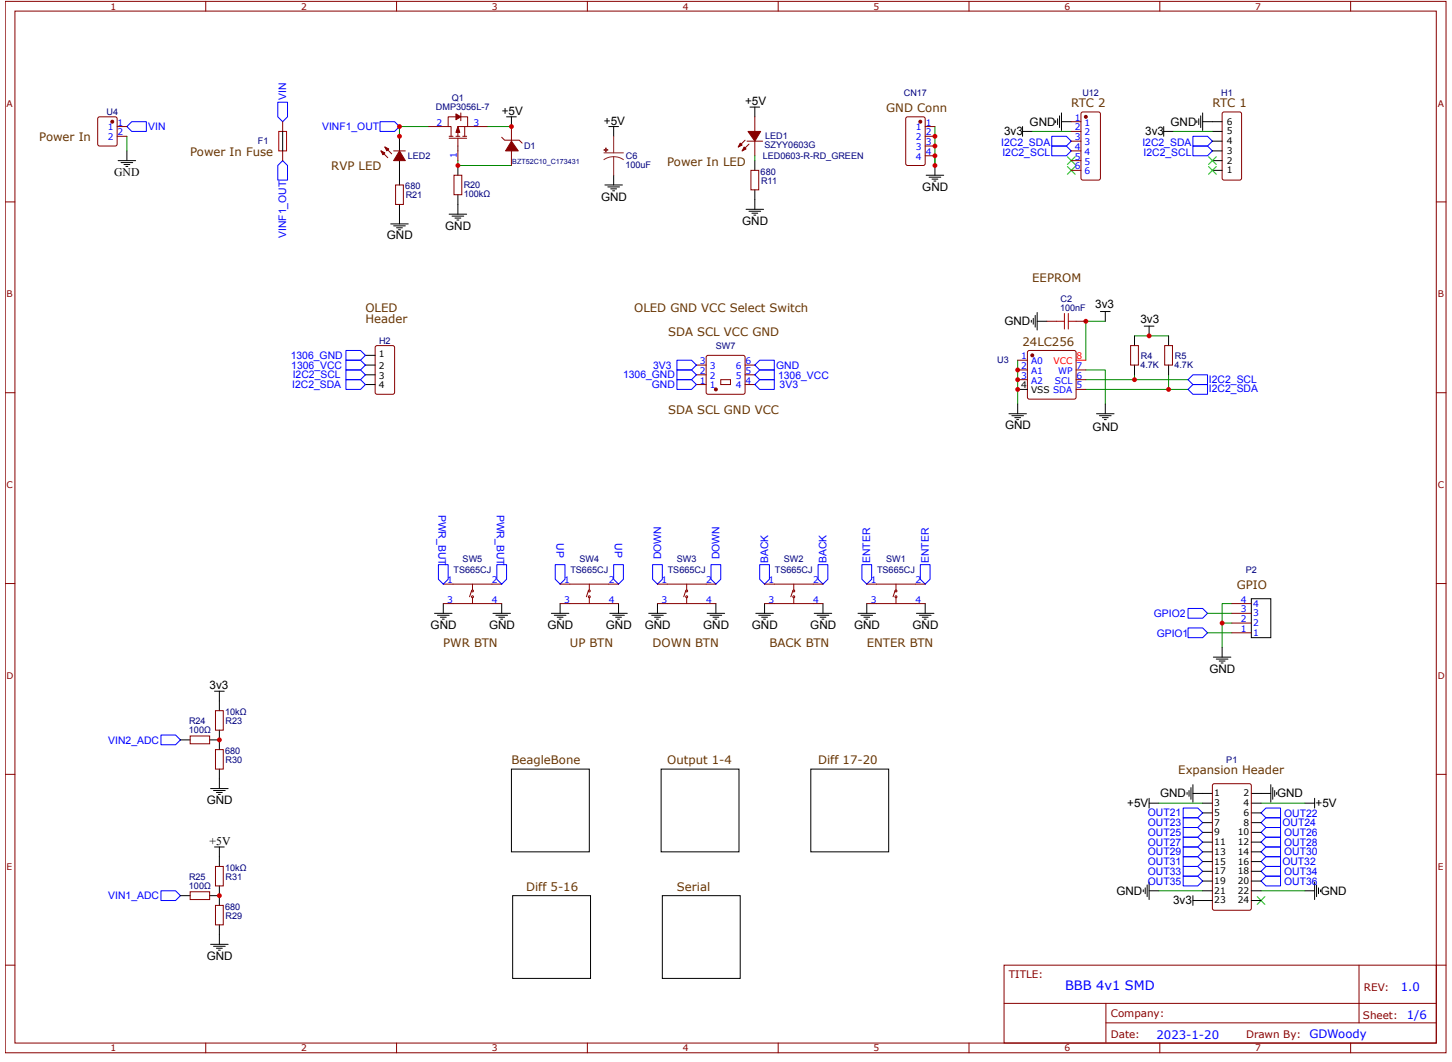
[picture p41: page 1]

OLED GND VCC Select Switch
SDA SCL VCC GND

# BeagleBone Black Rev.C

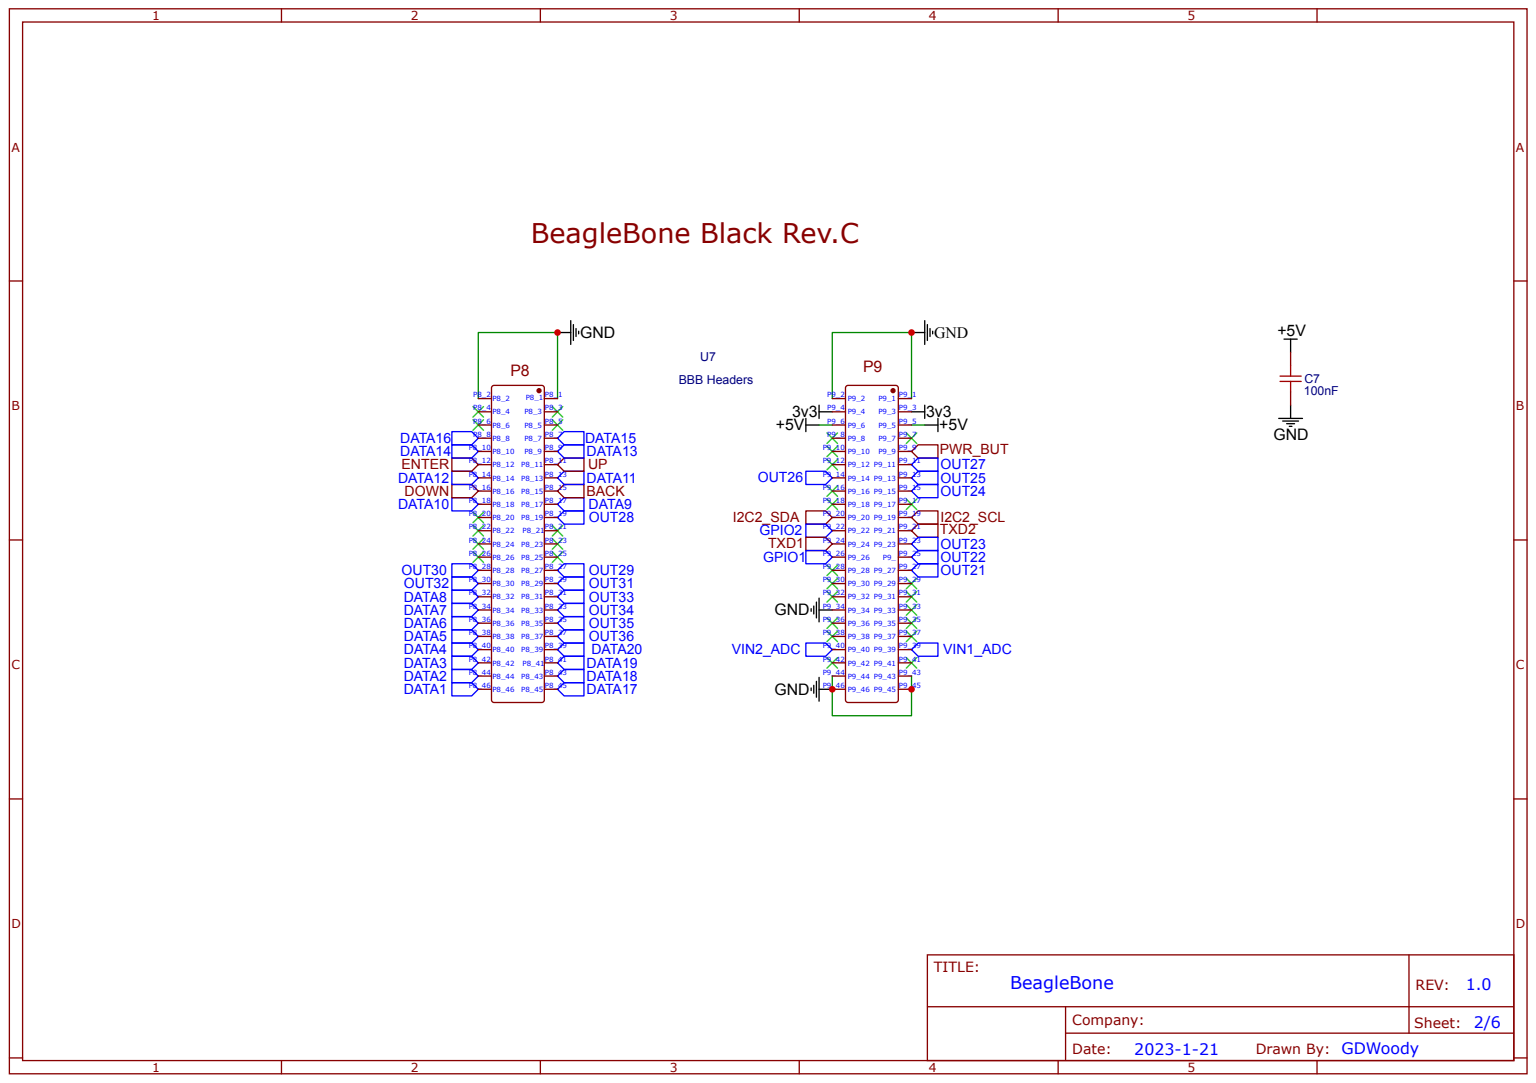
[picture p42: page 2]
TITLE:; BeagleBone; REV: 1.0; Date:; Sheet: 2/6; Company:; GND; PWR_BUT; OUT27 OUT26; OUT25; OUT24; I2C2_SDA; I2C2_SCL GPIO2; TXD2; TXD1; OUT23 GPIO1; OUT22; OUT21; VIN2_ADC; VIN1_ADC; DATA1; DATA17; GND DATA2; DATA18 DATA3; DATA19 DATA4; DATA20 DATA5; OUT36 DATA6; OUT35 DATA7; OUT34 DATA8; OUT33 OUT32; OUT31 OUT30; OUT29; OUT28 DATA10; DATA9 DOWN; BACK DATA12; DATA11 ENTER; UP DATA14; DATA13 DATA16; DATA15; BBB Headers

Drawn By: GDWoody

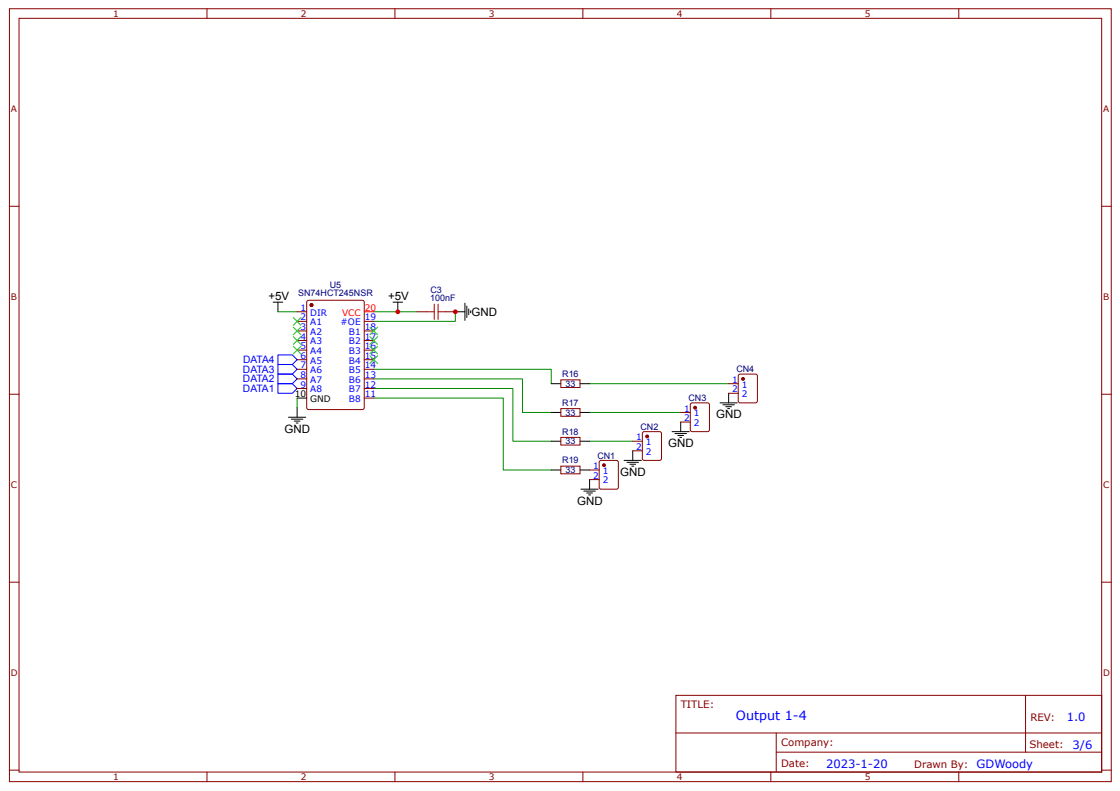
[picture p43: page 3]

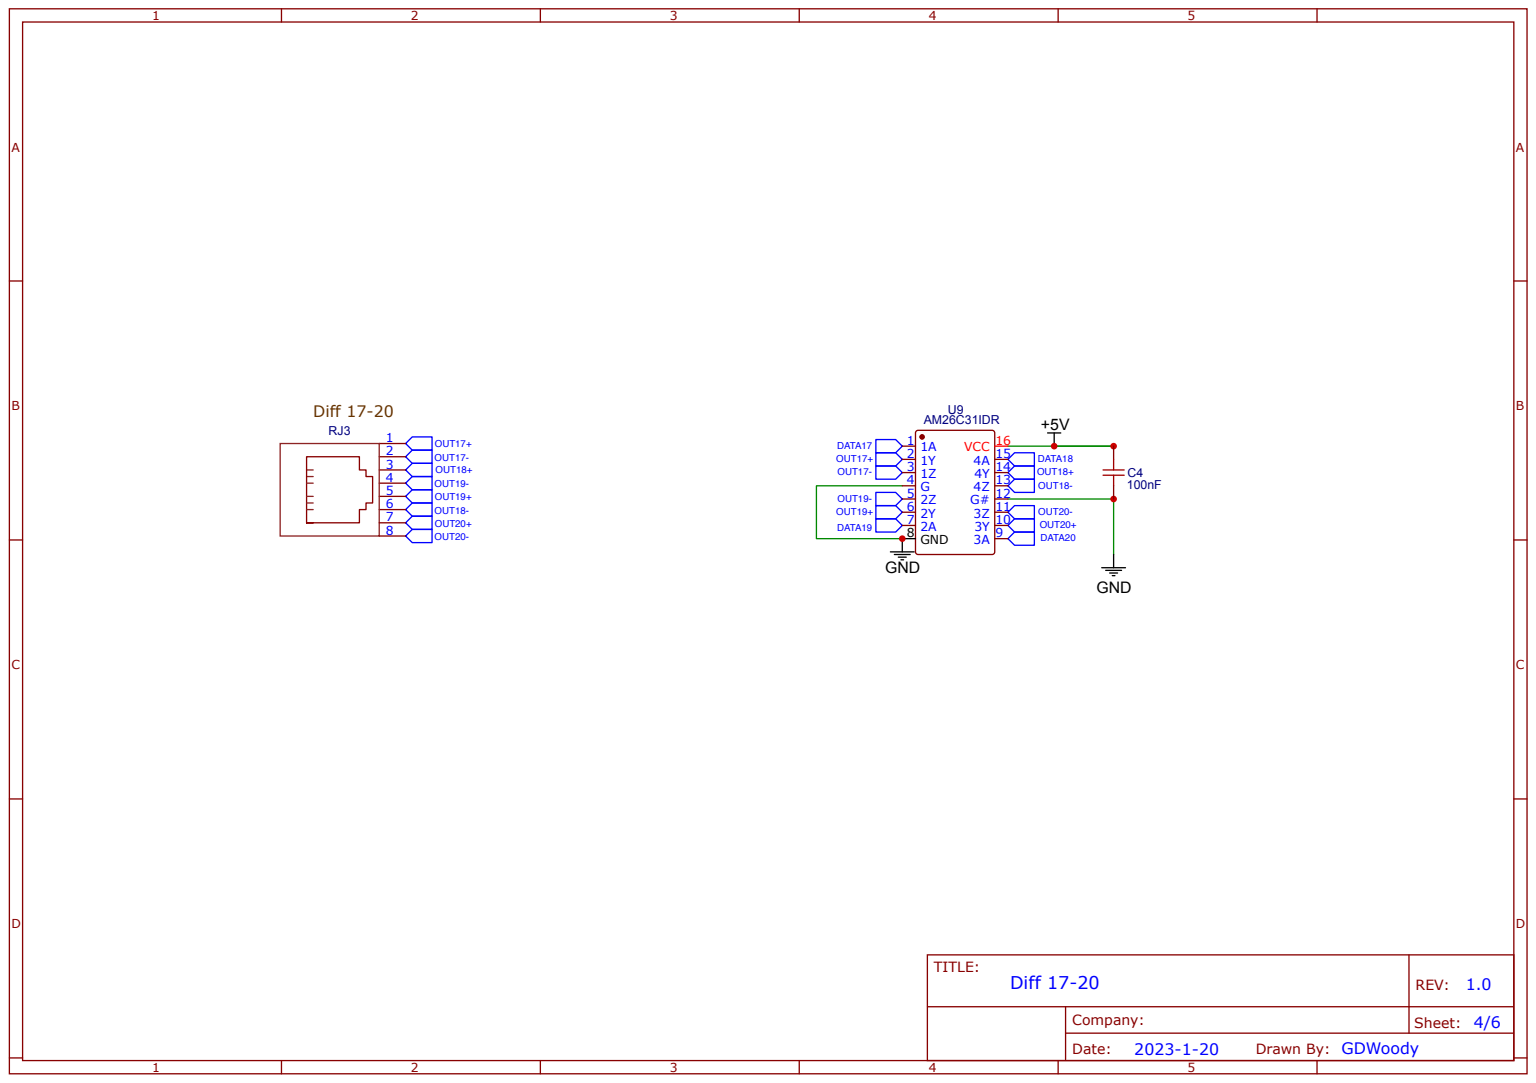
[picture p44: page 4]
OUT20-; OUT20+; OUT18-; OUT19+; OUT19-; OUT18+; OUT17+ OUT17-; OUT19- OUT19+; GND; DATA17; DATA18; DATA19; DATA20; TITLE:; Diff 17-20; REV: 1.0; Date:; Sheet: 4/6; Company:; AM26C31IDR U9; GND 8; 3A 9 3Y 10 3Z 11 G# 12 4Z 13 4Y 14 4A 15 VCC 16 RJ3

Drawn By: GDWoody

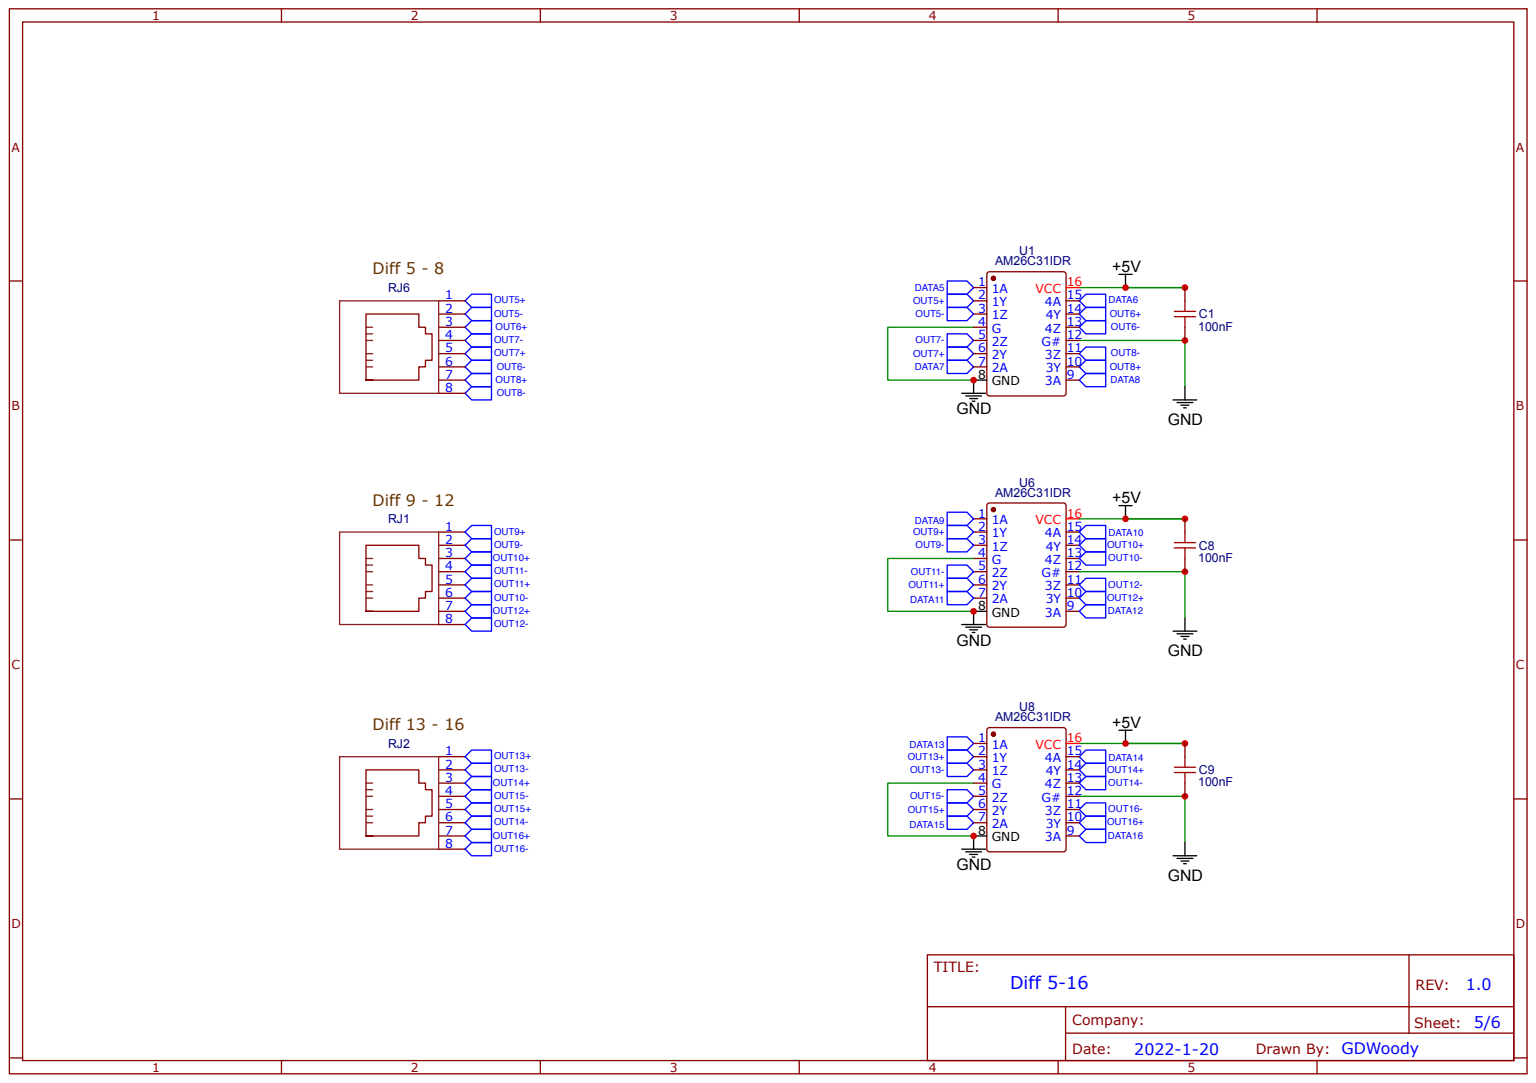
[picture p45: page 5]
TITLE:; Diff 5-16; REV: 1.0; Date:; Sheet: 5/6; Company:; AM26C31IDR U6; GND; 9 3Y 10 3Z 11 G# 12 4Z 13 4Y 14 4A 15 VCC 16 Diff 9 - 12; DATA12; DATA11; DATA10; DATA9; OUT9-; OUT9+; OUT11+; OUT11-; OUT12- OUT12+; OUT10+ OUT10-; OUT14-; OUT14+; OUT16+; OUT16-; OUT15- OUT15+; OUT13+ OUT13-; DATA13; DATA14; DATA15; DATA16; Diff 13 - 16; AM26C31IDR U8; 9 3Y 10 3Z 11 G# 12 4Z 13 4Y 14 4A 15 VCC 16 RJ2; OUT9+ OUT9- OUT10+ OUT11- OUT11+ OUT10-; OUT12-; OUT12+; OUT15+; OUT15-; OUT16+ OUT16-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

Drawn By: GDWoody

### LOR/DMX Select

6 6 5 5 4 4

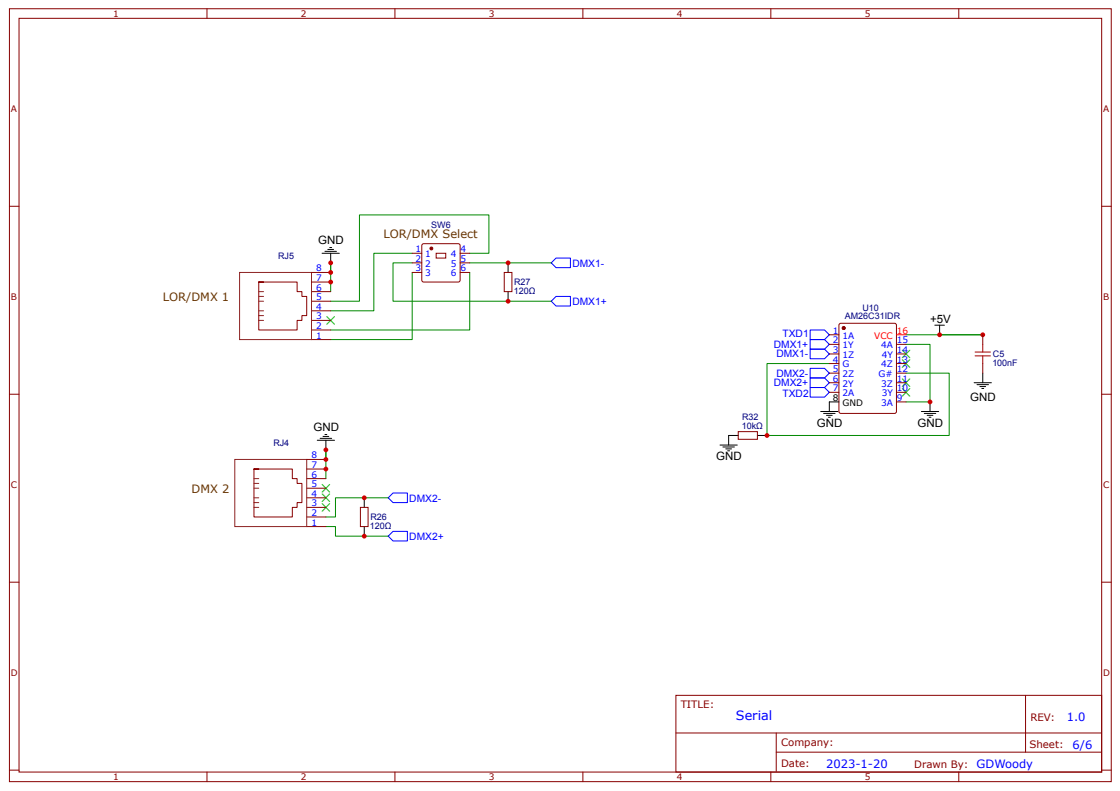
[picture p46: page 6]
TITLE:; Serial; REV: 1.0; Date:; Sheet: 6/6; Company:; TXD1; TXD2; DMX1+ DMX1-; DMX2- DMX2+; DMX1+; DMX1-; DMX2+; DMX2-; GND; DMX 2; LOR/DMX 1; AM26C31IDR U10; GND 8; 3A 9 3Y 10 3Z 11 G# 12 4Z 13 4Y 14 4A 15 VCC 16

Drawn By: GDWoody

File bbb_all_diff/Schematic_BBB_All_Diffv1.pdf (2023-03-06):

A | A

3v3

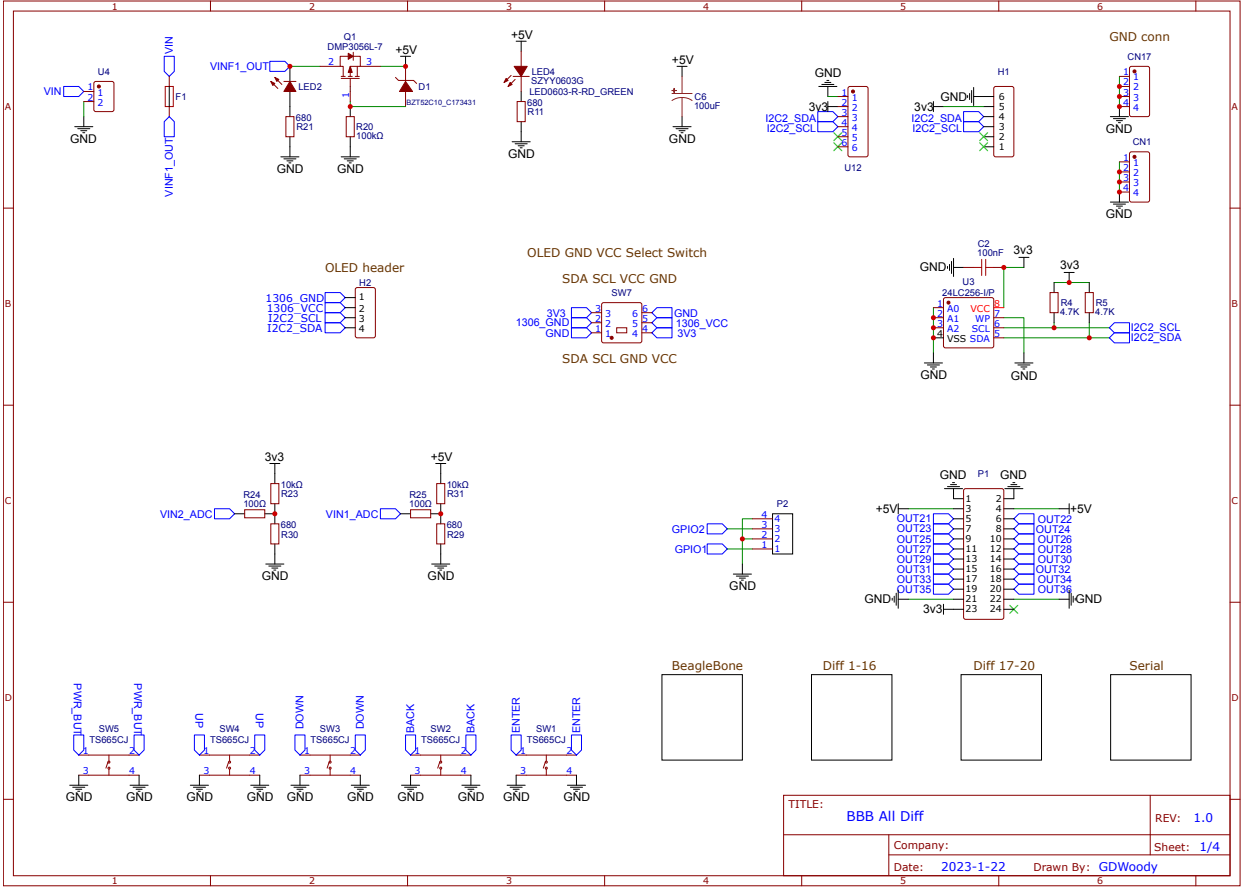
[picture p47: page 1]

OLED GND VCC Select Switch
SDA SCL VCC GND

A | A

# BeagleBone Black Rev.C

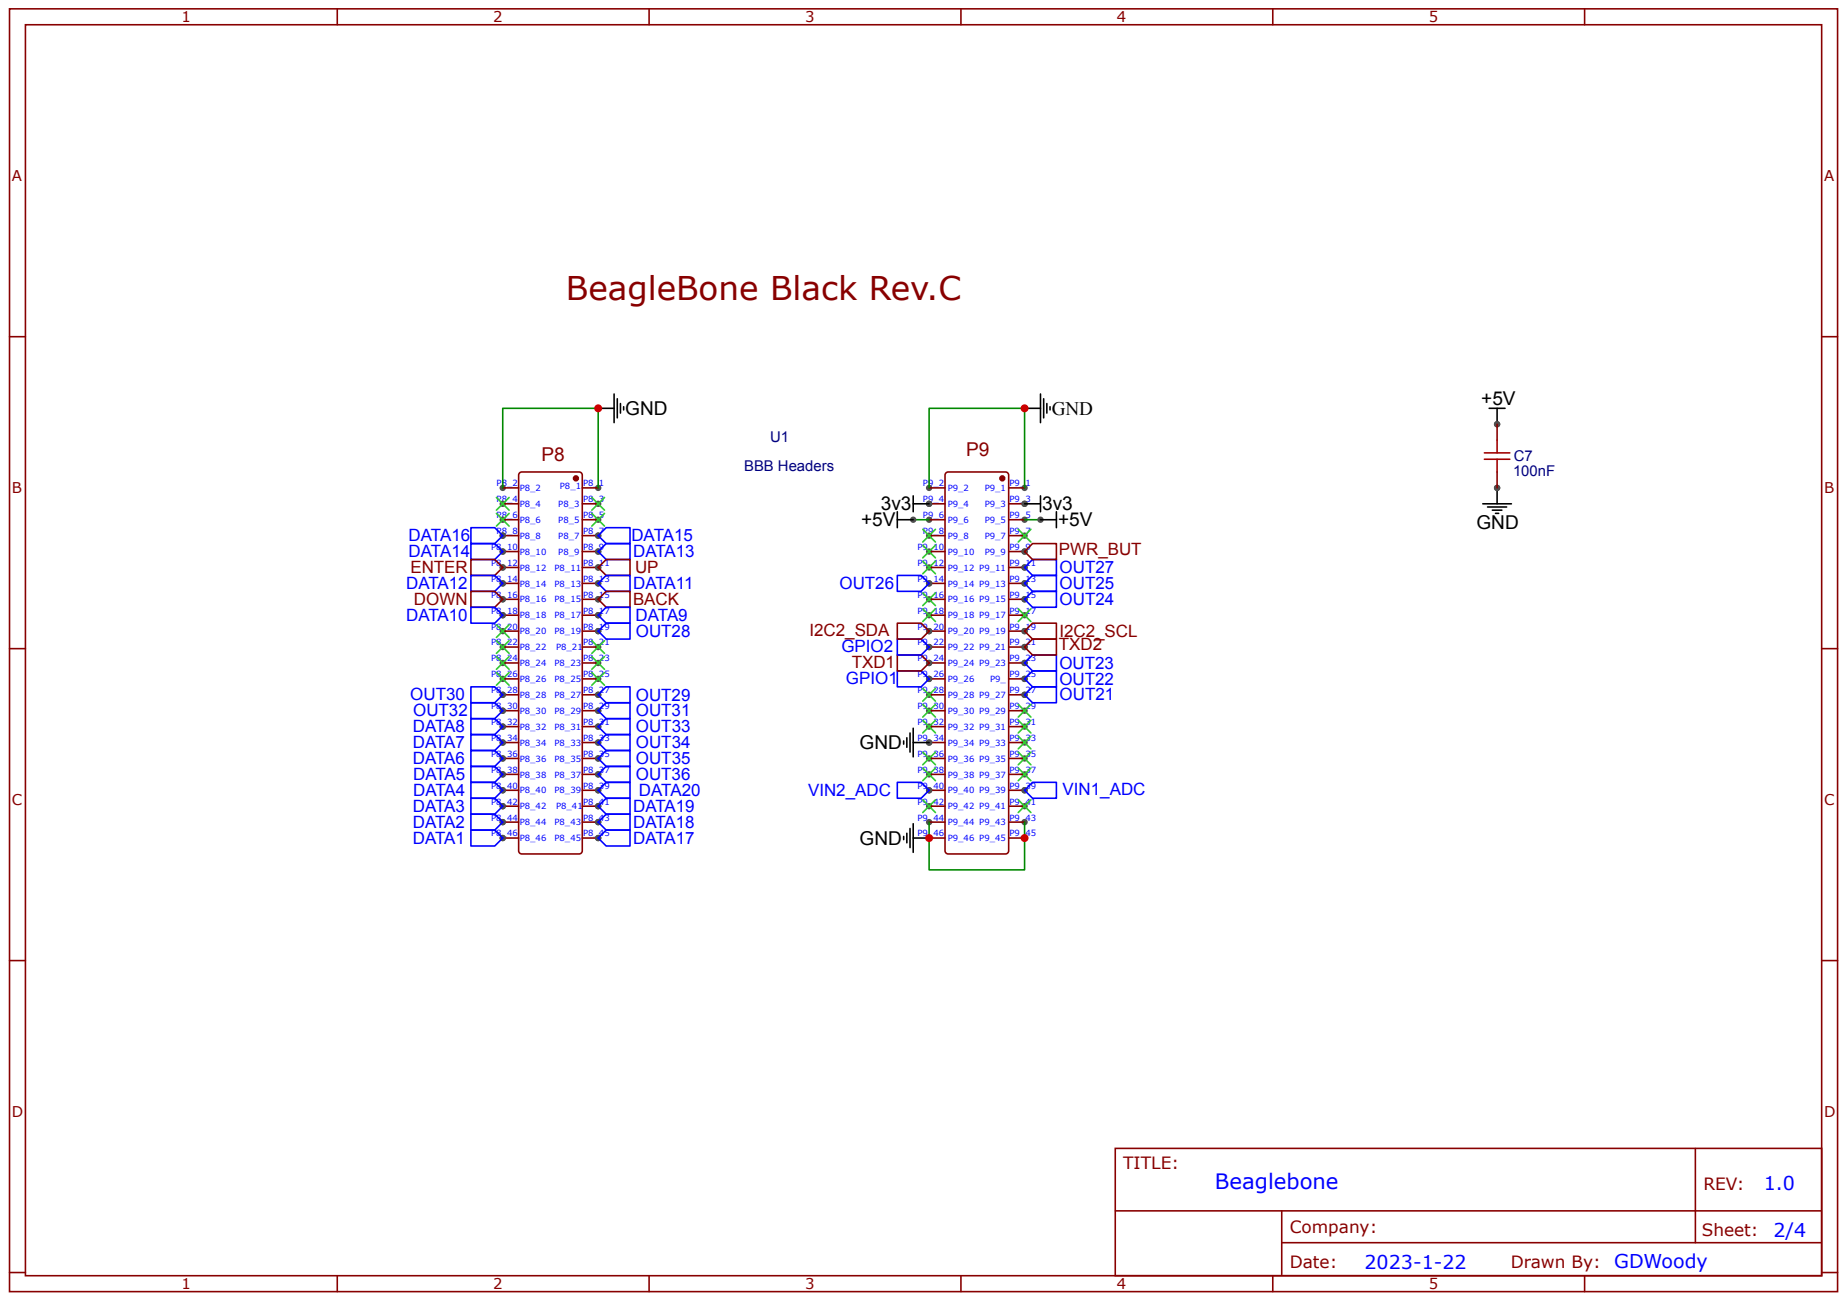
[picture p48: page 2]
TITLE:; Beaglebone; REV: 1.0; Date:; Sheet: 2/4; Company:; GND; C7 BBB Headers; DATA16; DATA15; DATA14; DATA13; ENTER; DATA12; DATA11; DOWN; BACK; DATA10; DATA9; OUT28; OUT30; OUT29; OUT32; OUT31; DATA8; OUT33; DATA7; OUT34; DATA6; OUT35; DATA5; OUT36; DATA4; DATA20; DATA3; DATA19; DATA2; DATA18; DATA1; DATA17; VIN2_ADC; VIN1_ADC; OUT21; GPIO1; OUT22; TXD1; OUT23; GPIO2; TXD2 I2C2_SDA; I2C2_SCL; OUT24; OUT26; OUT25; OUT27; PWR_BUT

Drawn By: GDWoody

A

A


A | A

OUT20-; OUT20+; OUT18-; OUT19+; OUT19-; OUT18+; OUT17+ OUT17-; OUT19- OUT19+; GND; DATA17; DATA18; DATA19; DATA20; TITLE:; Diff 17-20; REV: 1.0; Date:; Sheet: 4/5; Company:; AM26C31IDR U9; GND 8; 3A 9 3Y 10 3Z 11 G# 12 4Z 13 4Y 14 4A 15 VCC 16 RJ1

Drawn By: GDWoody

A | A

SW6

TITLE:; Serial; REV: 1.0; Date:; Sheet: 5/5; Company:; TXD1; TXD2; DMX1+ DMX1-; DMX2- DMX2+; DMX1+; DMX1-; DMX2+; DMX2-; GND; AM26C31IDR U10; GND 8; 3A 9 3Y 10 3Z 11 G# 12 4Z 13 4Y 14 4A 15 VCC 16

Drawn By: GDWoody

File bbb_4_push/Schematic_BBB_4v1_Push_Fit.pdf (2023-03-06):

### Power In Power In Fuse


OLED GND VCC Select Switch
SDA SCL VCC GND

# BeagleBone Black Rev.C

TITLE:; BeagleBone; REV: 1.0; Date:; Sheet: 2/6; Company:; GND; BBB Headers; DATA16; DATA15 DATA14; DATA13 ENTER; UP DATA12; DATA11 DOWN; BACK DATA10; DATA9; OUT28; OUT30; OUT29 OUT32; OUT31 DATA8; OUT33 DATA7; OUT34 DATA6; OUT35 DATA5; OUT36 DATA4; DATA20 DATA3; DATA19 DATA2; DATA18 DATA1; DATA17; VIN2_ADC; VIN1_ADC; OUT21 GPIO1; OUT22 TXD1; OUT23 GPIO2; TXD2 I2C2_SDA; I2C2_SCL; OUT24 OUT26; OUT25; OUT27; PWR_BUT

Drawn By: GDWoody


### Diff 5 - 8

TITLE:; Output 5-16; REV: 1.0; Date:; Sheet: 4/6; Company:; AM26C31IDR U6; GND; 9 3Y 10 3Z 11 G# 12 4Z 13 4Y 14 4A 15 VCC 16; Diff 9 - 12; DATA12; DATA11; DATA10; DATA9; OUT9-; OUT9+; OUT11+; OUT11-; OUT12- OUT12+; OUT10+ OUT10-; OUT14-; OUT14+; OUT16+; OUT16-; OUT15- OUT15+; OUT13+ OUT13-; DATA13; DATA14; DATA15; DATA16; Diff 13 - 16; AM26C31IDR U8; 9 3Y 10 3Z 11 G# 12 4Z 13 4Y 14 4A 15 VCC 16 RJ2; OUT9+ OUT9- OUT10+ OUT11- OUT11+ OUT10-; OUT12-; OUT12+; OUT15+; OUT15-; OUT16+ OUT16-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

Drawn By: GDWoody

OUT20-; OUT20+; OUT18-; OUT19+; OUT19-; OUT18+; OUT17+ OUT17-; OUT19- OUT19+; GND; DATA17; DATA18; DATA19; DATA20; TITLE:; Diff 17-20; REV: 1.0; Date:; Sheet: 5/6; Company:; AM26C31IDR U9; GND 8; 3A 9 3Y 10 3Z 11 G# 12 4Z 13 4Y 14 4A 15 VCC 16 RJ3

Drawn By: GDWoody

### LOR/DMX Select

6 6 5 5 4 4

TITLE:; Serial; REV: 1.0; Date:; Sheet: 6/6; Company:; TXD1; TXD2; DMX1+ DMX1-; DMX2- DMX2+; DMX1+; DMX1-; DMX2+; DMX2-; GND; DMX 2; LOR/DMX 1; AM26C31IDR U10; GND 8; 3A 9 3Y 10 3Z 11 G# 12 4Z 13 4Y 14 4A 15 VCC 16

Drawn By: GDWoody

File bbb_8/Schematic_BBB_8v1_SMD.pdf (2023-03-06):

### Power In Power In Fuse


OLED GND VCC Select Switch
SDA SCL VCC GND

# BeagleBone Black Rev.C

TITLE:; BeagleBone; REV: 1.0; Date:; Sheet: 2/6; Company:; GND; C7 GND; PWR_BUT; OUT27 OUT26; OUT25; OUT24; I2C2_SDA; I2C2_SCL GPIO2; TXD2; TXD1; OUT23 GPIO1; OUT22; OUT21; VIN2_ADC; VIN1_ADC; DATA1; DATA17; GND DATA2; DATA18 DATA3; DATA19 DATA4; DATA20 DATA5; OUT36 DATA6; OUT35 DATA7; OUT34 DATA8; OUT33 OUT32; OUT31 OUT30; OUT29; OUT28 DATA10; DATA9 DOWN; BACK DATA12; DATA11 ENTER; UP DATA14; DATA13 DATA16; DATA15; BBB Headers

Drawn By: GDWoody


### Diff 9 - 12

TITLE:; Diff 9-16; REV: 1.0; Date:; Sheet: 4/6; Company:; AM26C31IDR U6; GND 8; 3A 9 3Y 10 3Z 11 G# 12 4Z 13 4Y 14 4A 15 VCC 16; GND; DATA12; DATA11; DATA10; DATA9; OUT9-; OUT9+; OUT11+; OUT11-; OUT12- OUT12+; OUT10+ OUT10-; OUT14-; OUT14+; OUT16+; OUT16-; OUT15- OUT15+; OUT13+ OUT13-; DATA13; DATA14; DATA15; DATA16; Diff 13 - 16; AM26C31IDR U8; 3A 9 3Y 10 3Z 11 G# 12 4Z 13 4Y 14 4A 15 VCC 16 RJ2; OUT9+ OUT9- OUT10+ OUT11- OUT11+ OUT10-; OUT12-; OUT12+; OUT15+; OUT15-; OUT16+ OUT16-

Drawn By: GDWoody

OUT20-; OUT20+; OUT18-; OUT19+; OUT19-; OUT18+; OUT17+ OUT17-; OUT19- OUT19+; DATA17; DATA18; DATA19; DATA20; TITLE:; Diff 17-20; REV: 1.0; Date:; Sheet: 5/6; Company:; GND; AM26C31IDR U9; GND 8; 3A 9 3Y 10 3Z 11 G# 12 4Z 13 4Y 14 4A 15 VCC 16 RJ3

Drawn By: GDWoody

### LOR/DMX Select

6 6 5 5 4 4

TITLE:; Serial; REV: 1.0; Date:; Sheet: 6/6; Company:; TXD1; TXD2; DMX1+ DMX1-; DMX2- DMX2+; DMX1+; DMX1-; DMX2+; DMX2-; GND; DMX 2; LOR/DMX 1; AM26C31IDR U10; GND 8; 3A 9 3Y 10 3Z 11 G# 12 4Z 13 4Y 14 4A 15 VCC 16

Drawn By: GDWoody

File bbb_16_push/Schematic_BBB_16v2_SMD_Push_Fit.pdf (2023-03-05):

### Power In Power In Fuse


OLED GND VCC Select Switch
SDA SCL VCC GND

# BeagleBone Black Rev.C

TITLE:; BeagleBone; REV: 1.0; Date:; Sheet: 2/6; Company:; GND; BBB Headers; DATA16; DATA15 DATA14; DATA13 ENTER; UP DATA12; DATA11 DOWN; BACK DATA10; DATA9; OUT28; OUT30; OUT29 OUT32; OUT31 DATA8; OUT33 DATA7; OUT34 DATA6; OUT35 DATA5; OUT36 DATA4; DATA20 DATA3; DATA19 DATA2; DATA18 DATA1; DATA17; VIN2_ADC; VIN1_ADC; OUT21 GPIO1; OUT22 TXD1; OUT23 GPIO2; TXD2 I2C2_SDA; I2C2_SCL; OUT24 OUT26; OUT25; OUT27; PWR_BUT

Drawn By: GDWoody

GND; DATA17; DATA18; DATA19; DATA20; TITLE:; Diff 17-20; REV: 1.0; Date:; Sheet: 3/6; Company:; AM26C31IDR U9; GND 8; 3A 9 3Y 10 3Z 11 G# 12 4Z 13 4Y 14 4A 15 VCC 16 RJ3

Drawn By: GDWoody

### LOR/DMX Select

6 6 5 5 4 4

TITLE:; Serial; REV: 1.0; Date:; Sheet: 4/6; Company:; TXD1; TXD2; DMX1+ DMX1-; DMX2- DMX2+; DMX1+; DMX1-; DMX2+; DMX2-; GND; DMX 2; LOR/DMX 1; AM26C31IDR U10; GND 8; 3A 9 3Y 10 3Z 11 G# 12 4Z 13 4Y 14 4A 15 VCC 16

Drawn By: GDWoody



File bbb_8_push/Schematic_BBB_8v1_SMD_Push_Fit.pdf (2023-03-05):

### Power In Power In Fuse


OLED GND VCC Select Switch
SDA SCL VCC GND

# BeagleBone Black Rev.C

TITLE:; BeagleBone; REV: 1.0; Date:; Sheet: 2/6; Company:; GND; BBB Headers; DATA16; DATA15 DATA14; DATA13 ENTER; UP DATA12; DATA11 DOWN; BACK DATA10; DATA9; OUT28; OUT30; OUT29 OUT32; OUT31 DATA8; OUT33 DATA7; OUT34 DATA6; OUT35 DATA5; OUT36 DATA4; DATA20 DATA3; DATA19 DATA2; DATA18 DATA1; DATA17; VIN2_ADC; VIN1_ADC; OUT21 GPIO1; OUT22 TXD1; OUT23 GPIO2; TXD2 I2C2_SDA; I2C2_SCL; OUT24 OUT26; OUT25; OUT27; PWR_BUT

Drawn By: GDWoody

OUT20-; OUT20+; OUT18-; OUT19+; OUT19-; OUT18+; OUT17+ OUT17-; OUT19- OUT19+; DATA17; DATA18; DATA19; DATA20; TITLE:; Diff 17-20; REV: 1.0; Date:; Sheet: 3/6; Company:; GND; AM26C31IDR U9; GND 8; 3A 9 3Y 10 3Z 11 G# 12 4Z 13 4Y 14 4A 15 VCC 16 RJ3

Drawn By: GDWoody

### LOR/DMX Select

6 6 5 5 4 4

TITLE:; Serial; REV: 1.0; Date:; Sheet: 4/6; Company:; TXD1; TXD2; DMX1+ DMX1-; DMX2- DMX2+; DMX1+; DMX1-; DMX2+; DMX2-; GND; DMX 2; LOR/DMX 1; AM26C31IDR U10; GND 8; 3A 9 3Y 10 3Z 11 G# 12 4Z 13 4Y 14 4A 15 VCC 16

Drawn By: GDWoody


### Diff 9 - 12

TITLE:; Output 9-16; REV: 1.0; Date:; Sheet: 6/6; Company:; AM26C31IDR U6; GND 8; 3A 9 3Y 10 3Z 11 G# 12 4Z 13 4Y 14 4A 15 VCC 16; GND; DATA12; DATA11; DATA10; DATA9; OUT9-; OUT9+; OUT11+; OUT11-; OUT12- OUT12+; OUT10+ OUT10-; OUT14-; OUT14+; OUT16+; OUT16-; OUT15- OUT15+; OUT13+ OUT13-; DATA13; DATA14; DATA15; DATA16; Diff 13 - 16; AM26C31IDR U8; 3A 9 3Y 10 3Z 11 G# 12 4Z 13 4Y 14 4A 15 VCC 16 RJ2; OUT9+ OUT9- OUT10+ OUT11- OUT11+ OUT10-; OUT12-; OUT12+; OUT15+; OUT15-; OUT16+ OUT16-

Drawn By: GDWoody

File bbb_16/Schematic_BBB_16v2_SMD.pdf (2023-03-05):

### Power In Power In Fuse


SDA SCL VCC GND

# BeagleBone Black Rev.C

TITLE:; BeagleBone; REV: 1.0; Date:; Sheet: 2/6; Company:; GND; PWR_BUT; OUT27 OUT26; OUT25; OUT24; I2C2_SDA; I2C2_SCL GPIO2; TXD2; TXD1; OUT23 GPIO1; OUT22; OUT21; VIN2_ADC; VIN1_ADC; DATA1; DATA17; GND DATA2; DATA18 DATA3; DATA19 DATA4; DATA20 DATA5; OUT36 DATA6; OUT35 DATA7; OUT34 DATA8; OUT33 OUT32; OUT31 OUT30; OUT29; OUT28 DATA10; DATA9 DOWN; BACK DATA12; DATA11 ENTER; UP DATA14; DATA13 DATA16; DATA15; BBB Headers

Drawn By: GDWoody

GND; TITLE:; Diff 17-20; REV: 1.0; Date:; Sheet: 3/6; Company:; AM26C31IDR U9; GND 8; 3A 9 3Y 10 3Z 11 G# 12 4Z 13 4Y 14 4A 15 VCC 16 RJ3; DATA17 OUT17+ OUT17-; OUT19- OUT19+ DATA19; DATA20; OUT20+; OUT20-; OUT18-; OUT18+; OUT17+; DATA18; OUT17- OUT18+ OUT19- OUT19+ OUT18- OUT20+ OUT20-

Drawn By: GDWoody

TITLE:; Serial; REV: 1.0; Date:; Sheet: 4/6; Company:; TXD1; TXD2; DMX1+ DMX1-; DMX2- DMX2+; DMX1+; DMX1-; DMX2+; DMX2-; GND; LOR/DMX Select; DMX 2; LOR/DMX 1; AM26C31IDR; GND 8; 3A 9 3Y 10 3Z 11 G# 12 4Z 13 4Y 14 4A 15 VCC SW6

Drawn By: GDWoody



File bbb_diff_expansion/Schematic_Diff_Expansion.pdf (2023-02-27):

# GND

+5V


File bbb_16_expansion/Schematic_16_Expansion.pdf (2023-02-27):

### Expansion Header




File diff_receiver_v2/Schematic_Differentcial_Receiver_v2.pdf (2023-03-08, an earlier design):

# Receiver

+5V


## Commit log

2023-02-28 assembly fils
    [BOM_BBB 4v1 SMD PCB.csv, PickAndPlace_BBB 4v1 SMD PCB.csv]
2023-02-28 assembly files
    [BOM_BBB 8v1 SMD PCB.csv, PickAndPlace_BBB 8v1 SMD PCB.csv]
2023-02-28 Update BOM_BBB-16 SMD PCB.csv
    [BOM_BBB-16 SMD PCB.csv]
2023-02-28 Update PickAndPlace_BBB-16 SMD PCB.csv
    [PickAndPlace_BBB-16 SMD PCB.csv]
2023-02-28 Update BOM_BBB 4v1 SMD PCB.csv
    [BOM_BBB 4v1 SMD PCB.csv]
2023-02-28 Update PickAndPlace_BBB 4v1 SMD PCB.csv
    [PickAndPlace_BBB 4v1 SMD PCB.csv]
2023-02-28 Update BOM_BBB 8v1 SMD PCB.csv
    [BOM_BBB 8v1 SMD PCB.csv]
2023-02-28 Update PickAndPlace_BBB 8v1 SMD PCB.csv
    [PickAndPlace_BBB 8v1 SMD PCB.csv]
2023-02-28 Update BOM_BBB All Diff SMD PCB.csv
    [BOM_BBB All Diff SMD PCB.csv]
2023-02-28 Update PickAndPlace_BBB All Diff SMD PCB.csv
    [PickAndPlace_BBB All Diff SMD PCB.csv]
2023-02-28 Update PickAndPlace_16 Expansion PCB.csv
    [PickAndPlace_16 Expansion PCB.csv]
2023-02-28 Update BOM_16 Expansion PCB.csv
    [BOM_16 Expansion PCB.csv]
2023-02-28 Update PickAndPlace_Diff Expansion PCB.csv
    [PickAndPlace_Diff Expansion PCB.csv]
2023-02-28 Update BOM_Diff Expansion PCB.csv
    [BOM_Diff Expansion PCB.csv]
2023-02-28 new folder
    [BOM BBB 16v2 SMD Push.csv, PickAndPlace BBB 16v2 SMD Push.csv]
2023-03-01 Update Schematic BBB 16v2 SMD Push.pdf
2023-03-01 Update Schematic BBB All Diffv1.pdf
2023-03-01 Bom and pick and place files
    [BOM BBB 8v1 SMD Push PCB.csv, PickAndPlace BBB 8v1 SMD Push PCB.csv]
2023-03-02 update bom
    [BOM BBB 16v2 SMD PCB.csv, BOM_BBB-16 SMD PCB.csv, PickAndPlace BBB 16v2 SMD PCB.csv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]
2023-03-02 Create BBB 16v2 SMD PCB Other Parts.csv
    [BBB 16v2 SMD PCB Other Parts.csv]
2023-03-02 assembly files update
    [BOM_BBB_16v2_SMD_PCB.csv, PickAndPlace_BBB_16v2_SMD_PCB.csv]
2023-03-02 bom update
    [BOM_BBB_16v2_SMD_PCB_Other_Parts.csv]
2023-03-02 bom renam
    [BOM_BBB_16v2_SMD_PCB.xlsx]
2023-03-02 bom file
    [PickAndPlace_BBB_16v2_SMD_PCB.csv, PickAndPlace_BBB_16v2_SMD_PCB.xlsx]
2023-03-02 bom changes
    [BOM_BBB_16v2_SMD_PCB_Other_Parts.csv, BOM_BBB_16v2_SMD_PCB_Other_Parts.xlsx]
2023-03-03 file rename
    [CPL_BBB_16v2_SMD_PCB.xlsx]
2023-03-05 Create Gerber_BBB 8v1_SMD_PCB_Push.zip
2023-03-05 bom files
    [BOM_BBB_8v1_SMD_Push.xlsx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]
2023-03-05 gerber rename
2023-03-05 Create Schematic BBB 8v1 SMD Push Fit.pdf
2023-03-05 Create Schematic BBB 16v2 SMD Push Fit.pdf
2023-03-06 Create Schematic BBB All Diffv1.pdf
2023-03-08 rename Schematic
2023-03-08 delet files
    [BOM_16 Expansion PCB.csv, BOM_BBB 4v1 SMD PCB.csv, BOM_BBB All Diff SMD PCB.csv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]
2023-03-08 bom files uploaded
    [BOM_BBB_4v1_SMD.xlsx, BOM_BBB_4v1_other_parts.xlsx]
2023-03-08 gerber folder
2023-03-08 upload bom files
    [BOM_BBB_8v1_Push_Fit_other_parts.xlsx, BOM_BBB_8v1_SMD_Push_Fit.xlsx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]
2023-03-08 upload assembly files
    [BOM_BBB_All_Diff_SMD.xlsx, BOM_BBB_All_Diff_other_parts.xlsx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]
2023-03-09 file upload
    [BOM_Diff_Expansion_SMD.xlsx, BOM_Diff_Expansion_other_parts.xlsx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]
2023-05-13 Create BBB All Diff SMD Mount.dxf
    added DFX board mounting
    [BBB All Diff SMD Mount.dxf]
2023-05-13 Create BBB 16v2 SMD Mount.dxf
    [BBB 16v2 SMD Mount.dxf]
2023-05-13 Create BBB 4v1 SMD Mount.dxf
    [BBB 4v1 SMD Mount.dxf]
2023-05-13 Create Differential Receiver v3 Mount.dxf
    [Differential Receiver v3 Mount.dxf]
2023-05-13 upload dfx files
    [Differential Receiver v2 Mount.dxf, Differential Receiver v4 Mount.dxf]
2023-05-13 Create BBB 4v1 SMD Push Mount.dxf
    [BBB 4v1 SMD Push Mount.dxf]
2023-05-13 Create BBB 8v1 SMD Mount.dxf
    [BBB 8v1 SMD Mount.dxf]
2023-05-13 Create BBB 8v1 SMD PCB Push Mount.dxf
    [BBB 8v1 SMD PCB Push Mount.dxf]
2023-05-13 Create 16 Expansion PCB Mount.dxf
    [16 Expansion PCB Mount.dxf]
2023-05-13 Create BBB 16v2 SMD Push Mount.dxf
    [BBB 16v2 SMD Push Mount.dxf]
2023-05-13 Create Diff Expansion Mount.dxf
    [Diff Expansion Mount.dxf]
2023-10-10 rename folder
    rename folder
    [Differential Receiver v2 Mount.dxf, Differential Receiver v3 Mount.dxf, Differential Receiver v4 Mount.dxf]
2023-10-10 add jlcpcb folder and files
    added jlcpcb folder, added files
    [BOM_Differential Receiver v2.xlsx, PickAndPlace_Differential Receiver v2.xlsx]
2023-10-10 upload v3 files
    [Differential Receiver v3 Mount.dxf]
2023-10-10 upload v3 files and folders
    [BOM_Differential Receiver v3_2023-10-10.xlsx, Differential Receiver v3 Mount.dxf, PickAndPlace_Differential Receiver v3_2023-10-10.xlsx]
2023-10-10 upload v4 files
    [BOM_Differential Receiver v3.xlsx, BOM_Differential Receiver v4.xlsx, Differential Receiver v4 Mount.dxf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]
2023-10-22 added WELD files and folders
    [BOM_WLED HW-010 Diff PCB_2023-10-22.xlsx, PickAndPlace_WLED HW-010 Diff PCB_2023-10-22.xlsx, WLED HW-010 Diff PCB.dxf]
2023-10-22 weld doc files
